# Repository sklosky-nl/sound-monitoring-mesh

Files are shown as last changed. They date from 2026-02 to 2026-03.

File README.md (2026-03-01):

# Sound Monitoring Mesh

A distributed sound monitoring system: ESP32-C3 sensor nodes sample audio via INMP441 I2S microphone, compute FFT-based dB and frequency-band levels, and POST measurements to a Node.js backend. A browser frontend provides real-time monitoring, triangulation, history playback, alerts, analytics, and a public kiosk display.

**Status:** ✅ Operational — 9 devices at Nova Labs makerspace (`xibo.space.nova-labs.org`)  
**Firmware:** `2.1.1-prod` (production) · `2.1.2-dev` (dev / OTA testing)  
**Backend / Frontend:** `v2.1.0`

---

## Table of Contents

1. [Architecture](#architecture)
2. [Hardware](#hardware)
3. [Firmware](#firmware)
4. [Backend](#backend)
5. [Frontend](#frontend)
6. [Production Deployment](#production-deployment-nova-labs)
7. [Development Setup](#development-setup)
8. [Scripts](#scripts)
9. [Security & Credentials](#security--credentials)
10. [Changelog](#changelog)

---

## Architecture

```
ESP32-C3 + INMP441  (×9)
        │  WiFi (REDACTED_WORKSHOP_WIFI_SSID)
        ▼
┌───────────────────────────────┐
│  xibo.space.nova-labs.org     │
│  Ubuntu 20.04 · Apache proxy  │
│                               │
│  ┌──────────────────────────┐ │
│  │ Node.js/Express :3000    │ │  ← /api/*
│  │  13 REST route modules   │ │
│  └──────────────────────────┘ │
│  ┌──────────────────────────┐ │
│  │ Frontend (vanilla JS)    │ │  ← xibo.space.nova-labs.org/sound/
│  │  Served by Apache        │ │
│  └──────────────────────────┘ │
│  ┌──────────────────────────┐ │
│  │ JSON file storage        │ │  ← backend/data/
│  └──────────────────────────┘ │
└───────────────────────────────┘
```

**Data flow:** Each device POSTs to `/api/data` every 5 s → backend stores JSON → frontend polls → renders.  
**Authentication:** Shared API key in `Authorization: Bearer` header (all devices share one key, uniquely identified by MAC address).

---

## Hardware

### Bill of Materials (per sensor node)

| Component | Part | Notes |
|---|---|---|
| MCU | ESP32-C3 SuperMini | RISC-V 160 MHz, 4 MB flash, 400 KB SRAM, USB-CDC |
| Microphone | INMP441 I2S MEMS | −26 dBFS, 61 dB SNR, 60 Hz–15 kHz |
| Power | USB-C cable + 5V wall charger | |
| Enclosure | 15–30 mm foam microphone windscreen | RF-transparent (<0.5 dB loss), acoustically transparent |
| Wiring | Dupont jumper wires | Solder header pins to ESP32-C3 SuperMini first |

> ⚠️ 3D-printed PETG enclosures blocked WiFi signals (6–16 dB loss). Foam windscreens are the confirmed solution.

### Wiring — ESP32-C3 → INMP441

| ESP32-C3 | GPIO | INMP441 Pin | Signal |
|---|---|---|---|
| 3V3 | — | VDD | Power (3.3 V) |
| GND | — | GND | Ground |
| GND | — | L/R | Channel select (GND = Left channel) |
| **4** | GPIO 4 | SD | I2S Data |
| **5** | GPIO 5 | SCK | I2S Bit Clock |
| **6** | GPIO 6 | WS | I2S Word Select |

> ⚠️ A **10 kΩ pull-down resistor on the SD line** (GPIO 4 to GND) is required. Without it the SD line floats and produces noise/incorrect readings.

```
ESP32-C3 SuperMini             INMP441
  3.3V ●────────────────────── VDD
   GND ●──────────┬─────────── GND
                  └─────────── L/R  (Left channel)
GPIO 4 ●──[10kΩ]──┤─────────── SD
GPIO 5 ●────────────────────── SCK
GPIO 6 ●────────────────────── WS
```

---

## Firmware

**Source:** `firmware/sound-level-sensor/`  
**Current versions:** `2.1.1-prod` (production binary) · `2.1.2-dev` (dev binary, points at local backend)

### Key Features

| Feature | Detail |
|---|---|
| I2S sampling | 16 kHz, **32-bit container** (INMP441 outputs 24-bit; DMA data width must be 32-bit) |
| FFT | 1024-point, Hamming window, ESP-DSP library |
| Frequency bands | 3 configurable bands (start Hz, end Hz per band), SPL via self-normalizing energy fraction |
| dB calculation | Full-spectrum RMS + peak-hold over reporting window |
| Event detection | Threshold 55 dB, min duration 50 ms, cooldown 500 ms |
| OTA updates | Checks `/api/firmware/check` hourly; dual OTA partitions; auto-rollback on failure |
| Time sync | SNTP/NTP on boot |
| Auth | `Authorization: Bearer <API_KEY>` on all API calls |
| Device identity | MAC address used as `device_id` (auto-detected at runtime) |

### Configuration (`sdkconfig.defaults` → copy to `sdkconfig`)

```ini
CONFIG_WIFI_SSID         = "YOUR_WIFI_SSID"
CONFIG_WIFI_PASSWORD     = "YOUR_WIFI_PASSWORD"
CONFIG_SERVER_URL        = "http://YOUR_SERVER_HOST:3000"
CONFIG_API_KEY           = "YOUR_API_KEY"
```

Real values live in `CREDENTIALS.local` (gitignored). Never commit actual credentials.

### Build & Flash

```bash
# One-time: source ESP-IDF
source ~/esp/esp-idf/export.sh

cd firmware/sound-level-sensor

# Configure (first time or when credentials change)
cp sdkconfig.defaults sdkconfig
idf.py menuconfig          # Set WiFi SSID, password, server URL, API key

# Build
idf.py build

# Flash (USB)
idf.py -p /dev/cu.usbmodem* flash

# Monitor serial output
idf.py -p /dev/cu.usbmodem* monitor
```

Expected serial output after successful boot:
```
I (xxxx) SOUND_SENSOR: Connected to WiFi
I (xxxx) SOUND_SENSOR: NTP sync complete
I (xxxx) SOUND_SENSOR: Starting measurement loop
I (xxxx) SOUND_SENSOR: dB=62.3 peak=71.0 band1=45.2 band2=58.1 band3=41.6
```

### OTA Update Workflow

1. Build new firmware binary
2. Copy binary to `backend/data/firmware/sound-sensor-X.Y.Z.bin`
3. Update `backend/data/firmware/versions.json` (version, filename, size, sha256)
4. Devices check hourly; auto-download and reboot if newer version found

Compute sha256:
```bash
shasum -a 256 backend/data/firmware/sound-sensor-X.Y.Z.bin
stat -f%z backend/data/firmware/sound-sensor-X.Y.Z.bin  # file size in bytes
```

### Firmware Version Registry (`backend/data/firmware/versions.json`)

| Version | Type | Notes |
|---|---|---|
| `2.1.1-prod` | Production | **Current** — I2S DMA fix, frequency SPL fix, 10kΩ SD pull-down |
| `2.1.2-dev` | Dev | Same fixes; points to local backend for OTA testing |
| `2.1.0-prod` | Production | Continuous sampling + peak detection |
| `1.2.0-prod` | Legacy | Production WiFi + server config |

### Critical I2S Fix (v2.1.1)

Prior firmware used `I2S_DATA_BIT_WIDTH_24BIT` in the DMA config, causing DMA mis-packing that produced a constant ~110 dB reading. The fix:

```c
// WRONG (caused constant ~110 dB):
.data_bit_width = I2S_DATA_BIT_WIDTH_24BIT,

// CORRECT (INMP441 uses 32-bit container for 24-bit data):
.data_bit_width = I2S_DATA_BIT_WIDTH_32BIT,
```

---

## Backend

**Source:** `backend/src/`  
**Runtime:** Node.js ≥18, Express.js  
**Storage:** JSON files in `backend/data/`

### Setup

```bash
cd backend
cp .env.example .env       # configure SHARED_API_KEY (and optionally PORT)
npm install
npm start                  # production
npm run dev                # development (nodemon)
```

**Environment variables (`.env`):**
```
PORT=3000
HOST=0.0.0.0
SHARED_API_KEY=<see CREDENTIALS.local>
```

### API Routes

All routes are prefixed `/api/`.

| Prefix | File | Description |
|---|---|---|
| `/api/devices` | `routes/devices.js` | Register, list, update, delete devices; calibration; frequency-band config |
| `/api/data` | `routes/data.js` | Receive measurements; query recent/range; export CSV/JSON |
| `/api/config` | `routes/config.js` | Display thresholds; per-device config |
| `/api/alerts` | `routes/alerts.js` | Alert rules CRUD; alert history |
| `/api/analytics` | `routes/analytics.js` | Aggregated stats, trend data, heatmap data |
| `/api/positions` | `routes/positions.js` | Sensor XYZ positions for triangulation map |
| `/api/barriers` | `routes/barriers.js` | Acoustic barriers (walls, curtains, partitions) |
| `/api/sources` | `routes/sources.js` | Sound source location records |
| `/api/triangulation` | `routes/triangulation.js` | Locate/locate-multiple; playback endpoints |
| `/api/labels` | `routes/labels.js` | Map label annotations CRUD |
| `/api/firmware` | `routes/firmware.js` | OTA: `/check`, `/download/:version`, `/upload`, `/versions`, `/latest` |
| `/api/grafana` | `routes/grafana.js` | Grafana JSON datasource (`/search`, `/query`, `/annotations`) |
| `/api/version` | `routes/version.js` | Returns backend version |

**Key endpoints:**
```
GET  /health
GET  /api/devices
POST /api/devices/register              ← called by firmware on boot
POST /api/data                          ← called by firmware every 5 s
GET  /api/data/recent                   ← latest reading per device
GET  /api/data/measurements/:deviceId
GET  /api/firmware/check?device_id=&current_version=
GET  /api/firmware/download/:version
GET  /api/triangulation/locate
GET  /api/triangulation/playback/range
GET  /api/grafana/kiosk/data
```

**Data storage layout:**
```
backend/data/
├── devices/           ← one JSON file per device (MAC address filename)
├── measurements/      ← daily JSON files per device (gitignored)
├── config/
│   └── display-thresholds.json
├── alerts/
│   └── history/
├── firmware/
│   ├── versions.json
│   └── *.bin
├── map_labels.json
└── acoustic_barriers.json
```

---

## Frontend

**Source:** `frontend/`  
**Technology:** Vanilla JavaScript (ES6+), HTML5/CSS3, Chart.js 4.4.0  
**Served by:** Apache at `/sound/` (production) or directly from `frontend/` in development

### Pages

| File | Purpose |
|---|---|
| `index.html` | Main dashboard (7 tabs) |
| `kiosk.html` | Public display — full-screen map + sensor status |
| `kiosk-debug.html` | Debug kiosk with API diagnostics |
| `debug.html` | API connectivity testing |

### Dashboard Tabs (`index.html`)

| Tab | Key Features |
|-----|---|
| **Dashboard** | Live device cards: dB level, frequency bands, color-coded status; auto-refresh 5 s |
| **Devices** | Register (MAC), edit, calibrate (dB offset), delete, export JSON |
| **Triangulation** | HTML5 Canvas map; sensor positions; acoustic barriers; map labels; real-time + playback |
| **History** | Time-series charts per device; second-precision datetime range picker |
| **Alerts** | Create/edit/delete alert rules; alert history viewer |
| **Analytics** | Statistical summaries, trend charts, customizable date ranges |
| **Settings** | Display thresholds, data retention, system configuration |

### Kiosk Mode (`kiosk.html`)

Auto-refreshing public display designed for permanent large-screen installation:
- Workshop layout canvas with sensor positions, acoustic barriers, and map labels
- Color-coded sensor indicators by dB level
- Active sensor count and system status summary

### Triangulation Playback

The Triangulation tab supports historical replay:
- Transport: play/pause, jog ±1 s, skip to start/end
- Variable speed: 0.25×, 0.5×, 1×, 2×, 5×, 10×
- Date/time range picker (day/hour/minute/second precision)
- Timeline slider with data availability indicator

### Color Thresholds (configurable via `/api/config/display-thresholds`)

| Range | Color | Default |
|---|---|---|
| Quiet | Green | < 80 dB |
| Moderate | Yellow | 80–95 dB |
| Loud | Red | > 95 dB |

---

## Production Deployment (Nova Labs)

| Item | Value |
|---|---|
| Server | `xibo.space.nova-labs.org` — Ubuntu 20.04.2 LTS |
| Proxy | Apache 2.4 reverse proxy |
| WiFi network | `REDACTED_WORKSHOP_WIFI_SSID` — isolated IoT VLAN |
| Backend URL | `http://xibo.space.nova-labs.org/api/sound` |
| Frontend URL | `http://xibo.space.nova-labs.org/sound/` |
| Active devices | 9 ESP32-C3 sensors |

### Apache Configuration (key lines)

```apache
# Proxy /api/sound/* → Node.js :3000/api/*
ProxyPass        /api/sound/ http://localhost:3000/api/
ProxyPassReverse /api/sound/ http://localhost:3000/api/

# Serve frontend static files
Alias /sound/ /path/to/frontend/
```

> ⚠️ The trailing slash on both `ProxyPass` paths is required. Without it, paths double to `/api/api/`.

### Operations

```bash
# SSH to server
ssh user@xibo.space.nova-labs.org

# Restart backend
cd ~/sound-monitoring-mesh/backend && npm start

# Deploy kiosk updates
./scripts/deploy-kiosk.sh
```

### Grafana Integration

The backend exposes a Grafana JSON datasource at `/api/grafana`.  
Dashboard definition: `scripts/grafana/grafana-dashboard.json`  
Install scripts: `scripts/grafana/install-grafana.sh` (dev) · `scripts/grafana/install-prod.sh` (production)

---

## Development Setup

```bash
# 1. Clone
git clone git@github.com:sklosky-nl/sound-monitoring-mesh.git
cd sound-monitoring-mesh

# 2. Backend
cd backend && cp .env.example .env   # fill in SHARED_API_KEY from CREDENTIALS.local
npm install && npm start             # http://localhost:3000

# 3. Access frontend
open http://localhost:3000           # main dashboard
open http://localhost:3000/kiosk.html

# 4. Flash a device
source ~/esp/esp-idf/export.sh
cd firmware/sound-level-sensor
cp sdkconfig.defaults sdkconfig
idf.py menuconfig                    # set WiFi + server + API key
idf.py build flash monitor -p /dev/cu.usbmodem*
```

**Versions:** Node.js ≥18 · ESP-IDF v6.x (tested with v6.1-dev-2300)

---

## Scripts

| Script | Purpose |
|---|---|
| `scripts/deploy-kiosk.sh` | Deploy frontend updates to production server |
| `scripts/grafana/install-grafana.sh` | Install Grafana on local/dev machine |
| `scripts/grafana/install-prod.sh` | Install Grafana on production server |
| `scripts/grafana/grafana-dashboard.json` | Grafana dashboard definition |

---

## Security & Credentials

**No credentials are stored in this repository.**

| Secret | Where used | How to set |
|---|---|---|
| WiFi SSID + password | Firmware `sdkconfig` | Copy from `CREDENTIALS.local` |
| Shared API key | Firmware `sdkconfig` + backend `.env` | Copy from `CREDENTIALS.local` |

The firmware and backend API key **must match exactly** for device authentication to work.

> ⚠️ **Git history note:** Commits prior to `f087388` (Feb 28, 2026) contain real credential values. Those credentials have been rotated. If you fork this repo, use `bfg --replace-text secrets.txt` to purge history before making it public.

---

## Repository Structure

```
sound-monitoring-mesh/
├── README.md                        ← this file
├── CHANGELOG.md                     ← version history
├── CREDENTIALS.local                ← gitignored; real secrets
├── backend/
│   ├── src/
│   │   ├── server.js
│   │   ├── routes/                  ← 13 route modules
│   │   ├── models/
│   │   ├── services/
│   │   └── utils/
│   └── data/                        ← gitignored runtime data
│       ├── devices/
│       ├── measurements/
│       ├── config/
│       ├── alerts/
│       ├── firmware/
│       │   ├── versions.json
│       │   └── *.bin
│       ├── map_labels.json
│       └── acoustic_barriers.json
├── frontend/
│   ├── index.html                   ← main dashboard (7 tabs)
│   ├── kiosk.html                   ← public display
│   ├── css/
│   └── js/
├── firmware/
│   ├── sound-level-sensor/          ← production firmware
│   │   ├── main/main.c
│   │   ├── sdkconfig.defaults       ← placeholder values only (never real credentials)
│   │   └── partitions.csv           ← dual OTA partitions
│   └── sound-level-sensor-debug/    ← debug build (serial only, no WiFi)
├── enclosure/
│   ├── Sound Sensor enclosure.f3d   ← Fusion 360 (archived; foam windscreens used instead)
│   └── WIFI_SIGNAL_SOLUTIONS.md
├── scripts/
│   ├── deploy-kiosk.sh
│   └── grafana/
│       ├── install-grafana.sh
│       ├── install-prod.sh
│       └── grafana-dashboard.json
└── docs-archive/                    ← superseded reference documents
```

---

## Changelog

See [CHANGELOG.md](CHANGELOG.md) for full version history.

### Recent: v2.1.1-prod / v2.1.2-dev — Feb 28, 2026
- Fix I2S DMA mis-packing (`I2S_DATA_BIT_WIDTH_24BIT` → `32BIT`) — was causing constant ~110 dB
- Fix frequency band SPL calculation (self-normalizing energy fraction)
- Confirm and document 10 kΩ pull-down on SD line (GPIO 4)

### v2.1.0-prod — Feb 12, 2026
- Continuous sampling with peak detection (was previously sampling only 6.4% of audio)
- Reports both RMS average and peak dB per reporting window

### v2.0.0 — Feb 12, 2026
- Historical data playback for triangulation (timeline scrubber, variable speed)
- Backend playback API: `/api/triangulation/playback/*`

### v1.2.0 — Feb 11, 2026
- Kiosk display page; production deployment to Nova Labs (9 devices)
- Apache ProxyPass configuration

---

**Author:** Stephen Klosky — [stephen.klosky@nova-labs.org](mailto:stephen.klosky@nova-labs.org)  
**Last updated:** February 28, 2026

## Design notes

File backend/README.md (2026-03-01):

# Backend

See the [main README](../README.md) for full documentation.

# Sound Level Mesh System - Backend API

Node.js backend API server for the Sound Level Mesh System.

**Status:** ✅ Operational with 9 devices actively sending data

## Features

### Core Functionality
- RESTful API with 9 route modules
- Device registration and management
- Real-time measurement data collection and storage
- Shared API key authentication with per-device validation
- File-based JSON storage (no database required)
- Automatic data cleanup with configurable retention
- Comprehensive logging with Winston

### API Modules
1. **Device Management** - Registration, CRUD operations, device info
2. **Data Collection** - Measurement submission and retrieval
3. **Configuration** - Frequency bands, calibration, device settings
4. **Alerts** - Alert rules, threshold monitoring, notification system
5. **Analytics** - Statistical analysis, trends, aggregations
6. **Triangulation** - Sound source localization using continuous RSS (Received Signal Strength) measurements
   - Single-source localization using basic RSS
   - Multi-source detection using frequency-band separation and temporal clustering
7. **Positions** - Sensor spatial positioning and mapping
8. **Sources** - Sound source tracking and management
9. **Barriers** - Acoustic obstacle modeling for triangulation

### Data Management
- JSON file-based storage for devices, measurements, alerts
- Time-series measurement data organized by device and date
- Configurable data retention (default: 7 days)
- CSV export functionality
- Bulk data export (all devices + measurements)

## Setup

### Prerequisites

- Node.js 18.0.0 or higher
- npm

### Installation

```bash
cd backend
npm install
```

### Configuration

Create a `.env` file in the backend directory:

```bash
# Server Configuration
PORT=3000
NODE_ENV=development
HOST=0.0.0.0

# Data Storage
DATA_DIR=./data
DATA_RETENTION_DAYS=7

# API Configuration - Shared Key Approach
# All devices use this SAME API key (must match firmware CONFIG_API_KEY)
SHARED_API_KEY=<your-api-key>  # see CREDENTIALS.local
# Legacy alias (SHARED_API_KEY takes precedence)
API_KEY=<your-api-key>  # see CREDENTIALS.local

# Logging
LOG_LEVEL=info
```

**Shared API Key Approach:**
- All ESP32 devices use the **same API key** compiled into firmware
- The `SHARED_API_KEY` (or `API_KEY`) must **exactly match** the firmware's `CONFIG_API_KEY`
- Each device is uniquely identified by its MAC address (e.g., `08:92:72:84:1d:18`)
- Backend validates the shared key first, then checks if device exists
- Simplifies deployment: one firmware build for all devices
- **Current deployment:** 9 devices operational, 10 purchased (1 spare)

**To change the key:**
1. Choose a secure random string (e.g., UUID)
2. Update `SHARED_API_KEY` in backend `.env`
3. Update `CONFIG_API_KEY` in firmware `sdkconfig` (via `idf.py menuconfig`)
4. Rebuild and reflash all devices
5. Re-register all devices in backend (they'll get new shared key)

### Server Settings

The backend includes the following optimizations for IoT device communication:

- **Body Parser Limit**: 10MB (handles large JSON payloads)
- **Request Timeout**: 30 seconds
- **Response Timeout**: 30 seconds
- **CORS**: Enabled for all origins (development mode)
- **Host**: 0.0.0.0 (listens on all network interfaces)

## Running the Server

### Development mode (with auto-restart)

```bash
npm run dev
```

### Production mode

```bash
npm start
```

The server will start on port 3000 (configurable via `PORT` env variable).

**Access:**
- API Base: http://localhost:3000/api/
- Frontend: http://localhost:3000 (serves static files from ../frontend)
- Health Check: http://localhost:3000/health
- Kiosk Display: http://localhost:3000/kiosk.html

**Logs:**
- Console output (info level)
- File logging: `data/logs/server.log`

### Current Status

**Active System:**
- 9 devices registered and sending data
- Real-time measurements every 5 seconds
- All API endpoints operational
- Frontend fully integrated

---

## API Endpoints

### Quick Reference

**Devices:**
- `GET /api/devices` - List all devices
- `POST /api/devices/register` - Register new device
- `GET /api/devices/:id` - Get device details
- `PUT /api/devices/:id` - Update device
- `DELETE /api/devices/:id` - Delete device

**Measurements:**
- `POST /api/data/measurements` - Submit measurement (requires auth)
- `GET /api/data/measurements/:deviceId` - Get device measurements
- `GET /api/data/export/csv/:deviceId` - Export to CSV

**Configuration:**
- `GET /api/config/devices/:id/frequency-bands` - Get device config
- `PUT /api/config/devices/:id/frequency-bands` - Update bands
- `PUT /api/config/devices/:id/calibration` - Update calibration

**Alerts:**
- `GET /api/alerts` - List alert rules
- `POST /api/alerts` - Create alert rule
- `GET /api/alerts/history/all` - Get alert history

**Analytics:**
- `GET /api/analytics/stats` - Get statistics

**Triangulation:**
- `GET /api/triangulation/locate` - Locate single sound source using RSS
- `GET /api/triangulation/locate-multiple` - Locate multiple simultaneous sources
- `GET /api/triangulation/sensors` - Get sensor positions
- `GET /api/triangulation/sources/recent` - Get recent sound sources

**Positions & Barriers:**
- `GET /api/positions/sensors` - Get sensor positions
- `PUT /api/positions/sensors` - Update position
- `GET /api/barriers` - Get acoustic barriers
- `POST /api/barriers` - Add barrier

See [DEVELOPER_REFERENCE.md](../DEVELOPER_REFERENCE.md) for complete API documentation.

---

## Architecture

### File Structure
```
backend/
├── src/
│   ├── server.js           # Main Express server
│   ├── routes/             # API route modules (9 files)
│   ├── models/             # Data models (5 files)
│   ├── services/           # Business logic (triangulation, etc.)
│   └── utils/              # Helpers (logger)
├── data/
│   ├── devices/            # Device JSON files
│   ├── measurements/       # Measurement time-series data
│   ├── alerts/             # Alert rules and history
│   └── logs/               # Server logs
├── package.json
└── .env                    # Configuration
```

### Data Storage

**Devices:** `data/devices/{device_id}.json`
- One file per device
- Contains registration info, config, position

**Measurements:** `data/measurements/{device_id}_{YYYY-MM-DD}.json`
- One file per device per day
- Array of measurements with timestamps
- Old files cleaned up based on retention policy

**Alerts:** `data/alerts/`
- Alert rules and triggered alert history

### Authentication Flow

1. Device sends measurement with `Authorization: Bearer {api_key}` header
2. Backend extracts API key and device_id from request
3. Validates via `DeviceModel.verifyApiKey()`:
   - First checks if key matches `SHARED_API_KEY` (if configured)
   - If shared key matches, verifies device exists
   - Otherwise checks device-specific API key
4. If valid, stores measurement and updates last_seen
5. If invalid, returns 403 error

---

## API Endpoints (Detailed)

### Health Check

```http
GET /health
```

### Device Management

**Register a device:**
```http
POST /api/devices/register
Content-Type: application/json

{
  "device_id": "esp32_001",
  "mac_address": "AA:BB:CC:DD:EE:FF",
  "name": "Living Room Sensor",
  "location": "Living Room, North Wall"
}
```

**Get all devices:**
```http
GET /api/devices
```

**Get specific device:**
```http
GET /api/devices/:deviceId
```

**Update device:**
```http
PUT /api/devices/:deviceId
Content-Type: application/json

{
  "name": "Updated Name",
  "location": "New Location"
}
```

### Data Submission

**Submit measurement (requires API key):**
```http
POST /api/data/measurements
Authorization: Bearer <api_key>
Content-Type: application/json

{
  "device_id": "esp32_001",
  "timestamp": "2026-01-30T18:00:00Z",
  "db_level": 65.5,
  "db_level_raw": 65.5,
  "frequency_bands": [
    {
      "band_number": 1,
      "start_freq": 20,
      "end_freq": 200,
      "level": 45.2,
      "level_raw": 45.2
    }
  ]
}
```

**Get measurements:**
```http
GET /api/data/measurements/:deviceId?start_date=2026-01-29&end_date=2026-01-30
GET /api/data/measurements/:deviceId?limit=10
```

### Configuration

**Get device configuration:**
```http
GET /api/config/devices/:deviceId/frequency-bands
```

**Update frequency bands:**
```http
PUT /api/config/devices/:deviceId/frequency-bands
Content-Type: application/json

{
  "frequency_bands": [
    {
      "band_number": 1,
      "start_frequency": 20,
      "end_frequency": 200,
      "calibration_offset_db": 0.0
    }
  ],
  "measurement_interval": 5,
  "calibration_offset_db": 2.5
}
```

**Update calibration:**
```http
PUT /api/config/devices/:deviceId/calibration
Content-Type: application/json

{
  "calibration_offset_db": 2.5
}
```

## Data Storage

All data is stored in the `./data` directory:

- `data/devices/` - Device configuration files (JSON)
- `data/measurements/` - Measurement data files (JSON, one file per device per day)
- `data/logs/` - Server logs

## Automatic Cleanup

Old measurement data is automatically cleaned up based on the `DATA_RETENTION_DAYS` setting (default: 7 days).

Manual cleanup:
```http
POST /api/data/cleanup
```

## Development

### Project Structure

```
backend/
├── src/
│   ├── server.js          # Main server file
│   ├── routes/            # API route handlers
│   │   ├── devices.js
│   │   ├── data.js
│   │   └── config.js
│   ├── models/            # Data models
│   │   ├── Device.js
│   │   └── Measurement.js
│   └── utils/             # Utility functions
│       └── logger.js
├── data/                  # Data storage (git-ignored)
│   ├── devices/
│   ├── measurements/
│   └── logs/
├── package.json
├── .env                   # Environment configuration
└── README.md
```

### Adding New Endpoints

1. Create route handler in `src/routes/`
2. Import and register in `src/server.js`
3. Add model functions if needed in `src/models/`

## Deployment

For production deployment on Ubuntu server, see the main architecture document.

## License

TBD

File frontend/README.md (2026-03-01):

# Frontend

See the [main README](../README.md) for full documentation.

# Sound Level Mesh System - Frontend

Web-based dashboard for monitoring and managing sound level sensors.

**Status:** ✅ Operational - Served automatically by backend on port 3000

## Features

- **Dashboard:** Real-time device monitoring with live statistics (auto-refresh every 30 seconds)
- **Devices:** Device registration, management, and configuration
- **Triangulation:** Sound source localization with visual 2D map
- **History:** Time-series data viewer with second-precision datetime controls
- **Alerts:** Alert rule configuration and history viewer
- **Analytics:** Statistical analysis and trend visualization
- **Settings:** System configuration and data management
- **Kiosk Mode:** Public display dashboard (separate page)
- Responsive design (desktop and tablet)

## Running the Frontend

### Recommended: Backend Serves Frontend (Default)

**The backend automatically serves the frontend - no separate server needed!**

```bash
cd backend
npm install
npm start
```

Then open http://localhost:3000 in your browser.

**Access URLs:**
- Main Dashboard: http://localhost:3000
- Kiosk Display: http://localhost:3000/kiosk.html  
- API Endpoints: http://localhost:3000/api/*
- Health Check: http://localhost:3000/health

**Current Setup:**
- Running on MacBook
- Backend + Frontend on single port (3000)
- API and static files served together
- All devices connecting and sending data

### Alternative: Standalone Development Server (Optional)

For frontend-only development without backend:

```bash
cd frontend
python3 -m http.server 8080
```

Then open http://localhost:8080 in your browser.

**Note:** You'll need to configure the backend API URL in Settings tab.

### Option 2: Node.js http-server

```bash
# Install globally
npm install -g http-server

# Run
cd frontend
http-server -p 8080
```

### Option 3: VS Code Live Server Extension

1. Install "Live Server" extension in VS Code
2. Right-click on `index.html`
3. Select "Open with Live Server"

### Troubleshooting

**Port Already in Use:**
```bash
# Kill existing process on port 8080
lsof -ti :8080 | xargs kill -9 2>/dev/null
```

**CORS Issues:**
- The backend has CORS enabled for all origins (development mode)
- Make sure backend is running and accessible
- Check browser console for specific CORS errors

## Configuration

**Default Configuration (when served by backend):**
- API URL is automatically set to the same origin (http://localhost:3000)
- No configuration needed for normal use

**Production Configuration (Nova Labs):**
- Set the Backend API URL to http://xibo.space.nova-labs.org/api/sound

**Manual Configuration (if needed):**
1. Open the frontend in your browser
2. Go to the "Settings" tab
3. Set the Backend API URL (e.g., `http://localhost:3000` or `http://xibo.space.nova-labs.org/api/sound`)
4. Click "Save Configuration"

The setting is saved to browser localStorage and persists across sessions.

## Usage

### Dashboard Tab
- View all 9 registered devices
- See real-time sound levels and frequency bands
- Monitor device status (active within last minute)
- View average sound level across all devices
- Auto-refreshes every 30 seconds

### Devices Tab
- View detailed device information
- Edit device names (nickname) and locations
- Configure frequency bands
- Update calibration offsets
- Delete devices

### Triangulation Tab
- Visual 2D map of sensor positions
- Click-to-place sensor locations
- Real-time sound source localization
- Acoustic barrier modeling  

### History Tab  
- Select device from dropdown
- Choose date/time range with **second precision**
- View time-series chart of measurements
- Export data to CSV

### Alerts Tab
- Create threshold-based alert rules
- Configure alert conditions and durations
- View alert history
- Manage alert notifications

### Analytics Tab
- Statistical analysis (avg, min, max, std dev)
- Trend visualization
- Device comparison
- Custom date range selection

## API Integration

The frontend communicates with the backend API at the configured URL.

Default: `http://localhost:3000`

All API calls are made from `js/api.js`. The base URL is configurable through the Settings tab.

## Browser Support

- Chrome/Edge (recommended)
- Firefox
- Safari
- Modern mobile browsers

## Development

### File Structure

```
frontend/
├── index.html          # Main HTML file
├── css/
│   └── styles.css      # Application styles
└── js/
    ├── api.js          # API client
    └── app.js          # Main application logic
```

### Customization

- **Colors**: Edit CSS custom properties in `styles.css` `:root` section
- **Refresh interval**: Change value in `startAutoRefresh()` in `app.js`
- **Default ports**: Update in `api.js` and Settings tab

## Screenshots

(Screenshots would go here in a real README)

## License

TBD

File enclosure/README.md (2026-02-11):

# Sound Sensor Enclosure

This directory contains enclosure design files and documentation for the sound sensor hardware.

## ✅ Current Solution: Microphone Foam Windscreen Enclosure

**The final working solution uses microphone foam windscreens as the complete enclosure.**

### Implementation

**Materials:**
- Microphone foam windscreen (medium size, 15-30mm diameter)
- Zip tie or twist tie
- USB-C cable for power

**Assembly:**
1. Insert assembled ESP32-C3 + INMP441 sensor into foam windscreen
2. Route USB-C cable through foam
3. Secure foam around cable with zip tie
4. Ensure microphone opening has clear path through foam

**Why This Works:**
- ✅ **RF Transparent**: Foam has <0.5 dB WiFi signal loss
- ✅ **Acoustically Transparent**: Designed for microphone use, minimal SPL impact
- ✅ **Dust Protection**: Open-cell foam filters particles while allowing airflow
- ✅ **Cost Effective**: ~$1-2 per device
- ✅ **Washable**: Can clean foam when dirty
- ✅ **Quick Assembly**: No 3D printing required
- ✅ **Lightweight**: Easy to mount anywhere

**Recommended Products:**
- [Amazon microphone windscreens](https://a.co/d/01RMTvTz) - Medium size (15-25mm)
- Alternative: Air filter foam from hardware stores

**Maintenance:**
- Inspect foam monthly in dusty environments
- Wash with mild soap and water when dirty
- Dry completely (24 hours) before reinstalling
- Replace every 6-12 months or when degraded

---

## ❌ Previous Attempts (Did Not Work)

### 3D Printed PETG Enclosures

- **Sound Sensor enclosure.f3d** - Fusion 360 source file (archived)
- **Sound Sensor enclosure.stl** - STL file for 3D printing (archived)

**Issues Discovered:**
- ❌ **WiFi Signal Blocking**: PETG plastic attenuates 2.4 GHz WiFi by 6-16 dB
- ❌ **Connection Failures**: Devices could not maintain WiFi connection when fully enclosed
- ❌ **Fit Problems**: Lid required heat gun adjustment to close properly
- ❌ **Complexity**: 3D printing and post-processing time not justified

**Lessons Learned:**
- Solid plastic enclosures create Faraday cage effect for 2.4 GHz WiFi
- RF transparency is critical for wireless IoT devices
- Simple foam solutions outperform complex rigid enclosures for this application

**→ See [WIFI_SIGNAL_SOLUTIONS.md](WIFI_SIGNAL_SOLUTIONS.md) for detailed analysis of WiFi blocking issues and alternative solutions tested.**

---

## Design Files (Reference Only)

The 3D printed enclosure files are retained for reference but are **not recommended** for production use due to WiFi blocking issues.

---

## Usage Instructions (Foam Windscreen Solution)

### Assembly Steps

**Step 1: Component Preparation**
- Fully assemble ESP32-C3 with INMP441 microphone (see [HARDWARE_AND_FIRMWARE.md](../HARDWARE_AND_FIRMWARE.md))
- Connect USB-C cable for power
- Test device functionality before enclosing

**Step 2: Foam Installation**
1. Select foam windscreen slightly larger than device (20-30mm diameter typical)
2. Gently insert device into foam, microphone end first
3. Position INMP441 near an opening in the foam for clear sound path
4. Route USB cable through opposite end of foam

**Step 3: Securing**
1. Gather foam around USB cable at exit point
2. Secure with zip tie or twist tie (not too tight - allow some airflow)
3. Trim excess zip tie

**Step 4: Testing**
1. Power on device
2. Verify WiFi connection in backend dashboard (http://localhost:3000)
3. Check sound level readings are within expected range
4. If readings seem low, adjust foam position around microphone

**Step 5: Deployment**
- Mount device in desired location
- Ensure foam doesn't compress against surfaces
- Orient microphone opening away from direct weather exposure if outdoor
- Label device with MAC address for easy identification

### Mounting Options

- **Zip tie to post/beam**: Create loops through foam
- **Velcro strips**: Works well on flat surfaces  
- **Hanging with string**: Thread through foam
- **Shelf placement**: Simply set on flat surface

### Troubleshooting

**Issue: WiFi disconnections**
- Ensure foam is dry (wet foam increases RF attenuation)
- Check device is not in metal enclosure or near metal surfaces
- Verify router signal strength in deployment location

**Issue: Inaccurate sound readings**
- Check microphone opening is not blocked by compressed foam
- Verify foam is not touching INMP441 membrane directly
- Calibrate using `calibration_offset_db` parameter if needed

**Issue: Dust accumulation**
- Remove and wash foam with mild soap and water
- Dry completely for 24 hours before reinstalling
- Replace foam if heavily soiled or degraded

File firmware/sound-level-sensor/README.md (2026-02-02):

# Sound Level Sensor - ESP32-C3 Firmware

ESP32-C3 firmware for sound level monitoring with INMP441 I2S microphone.

## Features

- I2S audio sampling from INMP441 microphone (16kHz, 32-bit)
- FFT-based frequency analysis (1024 points with Hamming window)
- Configurable frequency bands (default: 20-200Hz, 200-2000Hz, 2000-8000Hz)
- dB level calculation with calibration support
- WiFi connectivity with automatic reconnection
- HTTP client with retry logic (3 attempts with exponential backoff)
- NTP time synchronization
- Robust error handling and connection management

## Hardware Configuration

- **ESP32-C3 SuperMini**
- **INMP441 I2S Microphone**

### Wiring (ESP32-C3 to INMP441)
- GPIO 4 → SD (I2S Data)
- GPIO 5 → SCK (I2S Clock)
- GPIO 6 → WS (Word Select)
- 3.3V → VDD
- GND → GND
- GND → L/R (Left channel select)

## Building and Flashing

### Prerequisites
- ESP-IDF v5.0 or later installed
- ESP32-C3 connected via USB

### Configure the Project

```bash
cd firmware/sound-level-sensor
. $HOME/esp/esp-idf/export.sh
idf.py menuconfig
```

Navigate to "Sound Level Sensor Configuration" and set:
- WiFi SSID (your home WiFi network name)
- WiFi Password
- Backend Server URL (e.g., `http://192.168.68.67:3000`)
- API Key (obtain from backend server)

### Build and Flash

```bash
# Build
idf.py build

# Flash to ESP32-C3 (replace port as needed)
idf.py -p /dev/tty.usbserial-* flash

# Monitor serial output
idf.py -p /dev/tty.usbserial-* monitor
```

### Build, Flash, and Monitor (all in one)

```bash
idf.py -p /dev/tty.usbserial-* flash monitor
```

## Configuration

Edit via `idf.py menuconfig` under "Sound Level Sensor Configuration":

- **WiFi SSID**: Your WiFi network name
- **WiFi Password**: Your WiFi password
- **Server URL**: Backend API server URL (e.g., `http://192.168.68.57:3000`)
- **API Key**: Authentication token for backend API

### HTTP Communication Settings

The firmware includes robust HTTP communication with the following configuration:

- **Connection Timeout**: 10 seconds
- **Retry Attempts**: 3 maximum retries
- **Retry Delay**: Exponential backoff (2s, 4s, 8s)
- **Keep-Alive**: Disabled (forces fresh connections)
- **Transport Type**: HTTP_TRANSPORT_OVER_TCP
- **Connection Header**: "Connection: close"

These settings ensure reliable communication even in challenging network conditions.

## Data Format

The firmware sends JSON data to `POST /api/data/measurements`:

```json
{
  "device_id": "esp32_001",
  "timestamp": "2026-01-30T18:00:00Z",
  "db_level": 65.5,
  "db_level_raw": 65.5,
  "frequency_bands": [
    {
      "band_number": 1,
      "start_freq": 20,
      "end_freq": 200,
      "level": 45.2,
      "level_raw": 45.2
    },
    {
      "band_number": 2,
      "start_freq": 200,
      "end_freq": 2000,
      "level": 52.1,
      "level_raw": 52.1
    },
    {
      "band_number": 3,
      "start_freq": 2000,
      "end_freq": 8000,
      "level": 48.3,
      "level_raw": 48.3
    }
  ]
}
```

## Troubleshooting

### Can't find serial port
- Check USB connection
- Verify driver installation: `ls /dev/tty.*`
- Try different USB port or cable

### Build errors
- Ensure ESP-IDF environment is activated: `. $HOME/esp/esp-idf/export.sh`
- Clean build: `idf.py fullclean && idf.py build`

### WiFi connection issues
- Verify SSID and password in menuconfig
- Check 2.4GHz WiFi availability (ESP32-C3 doesn't support 5GHz)
- Monitor serial output for connection status

### No audio data
- Verify I2S wiring connections
- Check microphone power (3.3V)
- Ensure L/R pin is connected to GND

## License

TBD

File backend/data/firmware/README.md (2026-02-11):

# Firmware OTA Update System

This directory contains firmware binaries for Over-The-Air (OTA) updates to ESP32-C3 sound sensor devices.

## Directory Structure

```
firmware/
├── versions.json           # Firmware version metadata
├── sound-sensor-1.0.0.bin  # Firmware binary files
├── sound-sensor-1.0.1.bin
└── README.md              # This file
```

## How OTA Updates Work

1. **Firmware Check**: Devices periodically check for updates via `GET /api/firmware/check`
2. **Version Comparison**: Backend compares device version with latest available
3. **Download**: If update available, device downloads binary via `GET /api/firmware/download/:version`
4. **Installation**: Device writes firmware to alternate partition and reboots
5. **Verification**: On boot, device verifies new firmware and marks it valid
6. **Rollback**: If new firmware fails, device automatically reverts to previous version

## Uploading New Firmware

### Method 1: Using curl

```bash
# Build firmware first
cd firmware/sound-level-sensor
idf.py build

# Upload to backend
curl -X POST "http://localhost:3000/api/firmware/upload?version=1.0.1&description=Bug%20fixes" \
     -H "Content-Type: application/octet-stream" \
     --data-binary "@build/sound-level-sensor.bin"
```

### Method 2: Manual File Copy

```bash
# Copy binary file
cp firmware/sound-level-sensor/build/sound-level-sensor.bin \
   backend/data/firmware/sound-sensor-1.0.1.bin

# Update versions.json
# Add new version entry manually
```

## API Endpoints

### Check for Updates
```http
GET /api/firmware/check?device_id=08:92:72:84:1d:18&current_version=1.0.0
```

Response (update available):
```json
{
  "updateAvailable": true,
  "version": "1.0.1",
  "url": "/api/firmware/download/1.0.1",
  "filename": "sound-sensor-1.0.1.bin",
  "size": 823456,
  "releaseDate": "2026-02-10T12:00:00.000Z",
  "description": "Bug fixes and performance improvements"
}
```

Response (no update): `204 No Content`

### Download Firmware
```http
GET /api/firmware/download/1.0.1
```

Returns binary file with headers:
- `Content-Type: application/octet-stream`
- `X-Firmware-Version: 1.0.1`
- `X-Firmware-SHA256: <hash>`

### List All Versions
```http
GET /api/firmware/versions
```

### Get Latest Version
```http
GET /api/firmware/latest
```

### Upload Firmware
```http
POST /api/firmware/upload?version=1.0.1&description=Release%20notes
Content-Type: application/octet-stream
Body: <binary data>
```

### Delete Version
```http
DELETE /api/firmware/1.0.0
```

## Firmware Update Schedule

- Devices check for updates every **60 minutes**
- First check occurs **5 minutes** after boot (allows system to stabilize)
- Updates only occur when WiFi is connected
- Devices automatically reboot after successful update

## Version Naming Convention

Use semantic versioning: `MAJOR.MINOR.PATCH`

- **MAJOR**: Incompatible API changes or major new features
- **MINOR**: Backward-compatible functionality additions
- **PATCH**: Backward-compatible bug fixes

## Safety Features

1. **Dual Partition**: Firmware stored in two partitions (ota_0 and ota_1)
2. **Automatic Rollback**: If new firmware fails to boot, device reverts to previous version
3. **Verification**: Devices validate firmware before marking as successful
4. **SHA-256 Checksums**: Ensures firmware integrity during download
5. **Timeout Protection**: HTTP downloads timeout after 30 seconds

## Staged Rollout

For production deployments with multiple devices:

1. Upload new firmware to backend
2. Monitor first device to receive update
3. Verify device stability for 24 hours
4. Allow remaining devices to update naturally
5. Or trigger immediate updates via device reboot (forces check)

## Troubleshooting

### Device Not Updating

1. Check device logs for OTA task status
2. Verify WiFi connectivity
3. Check backend firmware versions: `GET /api/firmware/versions`
4. Verify version comparison logic

### Update Failed

1. Check device logs for error messages
2. Verify firmware binary is valid ESP32-C3 image
3. Check firmware size (must fit in partition)
4. Device will automatically rollback to previous version

### Manual Rollback

If needed, flash device manually via USB:
```bash
cd firmware/sound-level-sensor
idf.py flash
```

## Security Considerations

- **HTTP vs HTTPS**: Currently using HTTP for simplicity
- **Authentication**: Uses API key authentication
- **Network**: Deploy on trusted network only
- **Future**: Consider HTTPS for production environments

## Monitoring

Device logs show OTA status:
```
I (12345) SOUND_SENSOR: Checking for firmware updates...
I (12346) SOUND_SENSOR: Current firmware version: 1.0.0
I (12500) SOUND_SENSOR: Update available: 1.0.1
I (12501) SOUND_SENSOR: Starting OTA update...
I (45000) SOUND_SENSOR: OTA update successful! Rebooting...
```

Backend logs show update activity:
```
Firmware update check from 08:92:72:84:1d:18: v1.0.0
Update available for 08:92:72:84:1d:18: v1.0.1
Serving firmware v1.0.1 (823456 bytes)
```

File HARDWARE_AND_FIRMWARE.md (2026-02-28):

# Hardware & Firmware Guide

Complete guide for hardware setup, wiring, firmware building, flashing, and device management for the Sound Level Mesh System.

**System Status:** ✅ Operational with multiple devices actively collecting data

## Table of Contents
1. [Hardware Components](#hardware-components)
2. [Component Pinouts & Wiring](#component-pinouts--wiring)
3. [Firmware Building](#firmware-building)
4. [Flashing Multiple Devices](#flashing-multiple-devices)
5. [Device Registration](#device-registration)
6. [OTA Firmware Updates](#ota-firmware-updates)
7. [Firmware Features](#firmware-features)
8. [Troubleshooting](#troubleshooting)

---

## Hardware Components

### Bill of Materials (Per Sensor Node)
- **1x ESP32-C3 SuperMini** - RISC-V microcontroller with WiFi
- **1x INMP441** - I2S digital MEMS microphone module  
- **1x USB-C cable** - For programming and power
- **Header pins** - For soldering to PCBs
- **Jumper wires** - For connecting microphone to ESP32
- **1x Microphone foam windscreen** - Enclosure/dust protection (15-30mm diameter)
- **1x Zip tie** - To secure foam around USB cable

### Example Components Used (AliExpress Links)

1. **ESP32-C3 SuperMini** - [AliExpress Link](https://www.aliexpress.us/item/3256807018729495.html)
2. **INMP441 I2S Microphone Module** - [AliExpress Link](https://www.aliexpress.us/item/3256809687889895.html)
3. **Header Pins** - [AliExpress Link](https://www.aliexpress.us/item/3256807581676863.html)
4. **USB-C Cables/Power** - [AliExpress Link](https://www.aliexpress.us/item/3256809620417878.html)
5. **Microphone Windscreens** - [Amazon Link](https://a.co/d/01RMTvTz) - Medium size recommended

### Enclosure Solution

**✅ Final Design: Foam Windscreen Enclosure**

After testing, the project uses **microphone foam windscreens** as the complete enclosure:
- **RF Transparent**: <0.5 dB WiFi signal loss (PETG blocked 6-16 dB)
- **Acoustically Transparent**: Optimized for microphone use
- **Dust Protection**: Filters particles while allowing airflow
- **Cost Effective**: ~$1-2 per device
- **Simple Assembly**: Insert device, route cable, secure with zip tie

See [enclosure/](enclosure/) directory for detailed assembly instructions.

❌ **3D Printed PETG Enclosures**: Initial designs blocked WiFi signals and are not recommended.

### Assembly Notes

⚠️ **Header Pin Issue**: The header pins listed above were not soldered to the PCBs. Manual soldering was required after receipt.

**Recommendation for Future Builds**: Order pre-soldered ("welded") headers and use Dupont jumpers for easier assembly and more reliable connections.

### ESP32-C3 SuperMini Specifications
- **MCU**: ESP32-C3 (RISC-V, single-core, 160 MHz)
- **RAM**: 400 KB SRAM
- **Flash**: 4 MB
- **WiFi**: 802.11 b/g/n (2.4 GHz)
- **GPIO**: 13 available pins
- **USB**: Built-in USB-CDC (no external USB-UART needed)
- **Power**: 5V via USB-C or 3.3V direct
- **Size**: Compact SuperMini form factor

### INMP441 I2S Microphone Specifications
- **Type**: Digital MEMS omnidirectional microphone
- **Interface**: I2S (Inter-IC Sound)
- **Sensitivity**: -26 dBFS
- **SNR**: 61 dB
- **Dynamic Range**: 83 dB
- **Frequency Response**: 60 Hz to 15 kHz
- **Supply Voltage**: 1.8V to 3.3V
- **Current**: ~1.4 mA

---

## Component Pinouts & Wiring

### ESP32-C3 SuperMini Pinout

**Physical Orientation**: Hold board with USB-C connector facing UP, chip facing YOU.

#### Complete Pin Table

| Pin Label | GPIO | Physical Position | Function / Notes |
|---|---|---|---|
| **5V** | - | Right Side, Pin 1 | 5V Power Input (from USB or external) |
| **GND** | - | Right Side, Pin 2 | Ground |
| **3V3** | - | Right Side, Pin 3 | 3.3V Output (Regulated) or Input |
| **0** | GPIO 0  | Right Side, Pin 4 | ADC1_CH0, Digital I/O |
| **1** | GPIO 1  | Right Side, Pin 5 | ADC1_CH1, Digital I/O |
| **2** | GPIO 2  | Right Side, Pin 6 | ⚠️ Strapping Pin (Keep floating at boot) |
| **3** | GPIO 3  | Right Side, Pin 7 | ADC1_CH3, Digital I/O |
| **4** | GPIO 4  | Right Side, Pin 8 | 🎤 **I2S_DATA (SD)** - Used for microphone |
| **5** | GPIO 5  | Left Side, Pin 1 | 🎤 **I2S_BCK (SCK)** - Used for microphone |
| **6** | GPIO 6  | Left Side, Pin 2 | 🎤 **I2S_WS (WS)** - Used for microphone  |
| **7** | GPIO 7  | Left Side, Pin 3 | SS (SPI), Digital I/O |
| **8** | GPIO 8  | Left Side, Pin 4 | ⚠️ Strapping Pin (Keep floating at boot) |
| **9** | GPIO 9  | Left Side, Pin 5 | ⚠️ Strapping Pin (Keep floating at boot) |
| **10** | GPIO 10 | Left Side, Pin 6 | Digital I/O |
| **20** | GPIO 20 | Left Side, Pin 7 | UART0 RX (USB CDC) |
| **21** | GPIO 21 | Left Side, Pin 8 | UART0 TX (USB CDC) |

### INMP441 Microphone Pinout

| Pin | Name | Function |
|-----|---|---|
| 1 | VDD  | Power supply (1.8-3.3V) |
| 2 | GND  | Ground |
| 3 | SD | Serial Data (I2S_DATA) |
| 4 | SCK  | Bit Clock (I2S_BCK) |
| 5 | WS | Word Select / L/R Clock |
| 6 | L/R  | Channel select (GND = Left) |

### Wiring Connections

**ESP32-C3 → INMP441**

| ESP32-C3 Pin | INMP441 Pin | Wire Color (Suggested) |
|---|---|---|
| 3V3 | VDD | Red |
| GND | GND | Black |
| GPIO 4 | SD | Yellow |
| GPIO 5 | SCK | Blue |
| GPIO 6 | WS | Green |
| GND | L/R | Black (same ground) |

### Wiring Diagram (Text)
```
ESP32-C3 SuperMini              INMP441 Microphone
┌────────────────┐              ┌──────────────┐
│                │              │              │
│     3.3V   ●───┼──────────────┼─● VDD        │
│                │              │              │
│      GND   ●───┼──────┬───────┼─● GND        │
│                │      │       │              │
│  GPIO 4    ●───┼──────┼───────┼─● SD         │
│  (I2S_DATA)    │      │       │              │
│                │      │       │              │
│  GPIO 5    ●───┼──────┼───────┼─● SCK        │
│  (I2S_BCK)     │      │       │              │
│                │      │       │              │
│  GPIO 6    ●───┼──────┼───────┼─● WS         │
│  (I2S_WS)      │      │       │              │
│                │      └───────┼─● L/R        │
│                │              │              │
└────────────────┘              └──────────────┘
```

### Important Notes
- ⚠️ **Strapping Pins**: GPIO 2, 8, and 9 must be floating or pulled correctly during boot
- ⚠️ **L/R Pin**: Connect to GND to set microphone as Left channel
- ⚠️ **Power**: Use 3.3V output from ESP32-C3, NOT 5V
- ⚠️ **Cable Length**: Keep wires short (<15cm) to reduce noise

---

## Firmware Building

### Prerequisites

#### Install ESP-IDF (macOS)
```bash
# Install dependencies
brew install cmake ninja dfu-util

# Clone ESP-IDF
mkdir -p ~/esp
cd ~/esp
git clone -b v5.3 --recursive https://github.com/espressif/esp-idf.git

# Install ESP-IDF tools
cd esp-idf
./install.sh esp32c3

# Add to shell profile (~/.zshrc or ~/.bash_profile)
alias get_idf='. $HOME/esp/esp-idf/export.sh'
```

### Configure the Project

```bash
cd firmware/sound-level-sensor

# Source ESP-IDF environment
. $HOME/esp/esp-idf/export.sh

# Configure project (opens menu)
idf.py menuconfig
```

#### Configuration Menu Settings

Navigate to: **Sound Level Sensor Configuration**

**Required Settings:**
- **WiFi SSID**: Your WiFi network name
- **WiFi Password**: Your WiFi password  
- **Server URL**: Backend API URL (e.g., `http://192.168.68.57:3000`)
- **API Key**: Shared authentication key (use same key for all devices)

**Shared API Key Approach:**
- ⚠️ **IMPORTANT**: All devices use the **same API key** hardcoded in firmware
- This allows flashing the same firmware to all devices without modification
- Current deployment: 9 operational devices (10 purchased)
- Each device is uniquely identified by its MAC address (e.g., `08:92:72:84:1d:18`)
- Example shared key: `YOUR_API_KEY_HERE`
- Backend must have matching key in `.env` as `SHARED_API_KEY` or `API_KEY`

**Production Environment (Nova Labs):**
- **WiFi SSID**: `REDACTED_WORKSHOP_WIFI_SSID`
- **WiFi Password**: `<see CREDENTIALS.local>`
- **Server URL**: `http://xibo.space.nova-labs.org/api/sound`
- **API Key**: `<see CREDENTIALS.local>`

⚠️ **Security Note**: These credentials are for the isolated IoT network at Nova Labs. The shared API key approach is suitable for trusted, internal networks only.

**Optional Settings (ESP-IDF standard menus):**
- Serial flasher config → Flash size: 4MB
- Component config → ESP32C3-Specific → CPU frequency: 160 MHz
- Component config → FreeRTOS → Tick rate: 1000 Hz

Save and exit (press `S`, then `Q`)

### Build the Firmware

```bash
# Clean build (if needed)
idf.py fullclean

# Build firmware
idf.py build
```

**Build Output:**, ~30 seconds (incremental)

**Current Firmware Version:**
- I2S sampling: 16kHz, 32-bit
- FFT: 1024 points with Hamming window
- Frequency bands: 3 configurable ranges
- Network: WiFi with HTTP client and NTP sync
- Authentication: Shared API key
- Auto-identification: MAC address-based device ID
- Binary file: `build/sound-level-sensor.bin`
- ELF file: `build/sound-level-sensor.elf`
- Build time: ~2-5 minutes (first build)

---

## Flashing Multiple Devices

### ✨ One Build for All Devices

The firmware automatically uses each ESP32's unique MAC address as its device ID. This means you can:

1. **Build once**
2. **Flash all 10 ESP32 devices** with the same binary
3. Each device **automatically identifies itself** with its unique MAC address (e.g., `08:92:72:84:1d:18`)

### Single Device Flash

```bash
# Find device port
ls /dev/cu.usb*

# Flash and monitor
idf.py -p /dev/cu.usbmodem1201 flash monitor

# Or flash only
idf.py -p /dev/cu.usbmodem1201 flash
```

### Flashing Multiple Devices - Manual Method

Connect and flash each device one at a time:

```bash
# Device 1
idf.py -p /dev/cu.usbmodem1201 flash monitor
# Note the MAC address from serial output!

# Disconnect device 1, connect device 2
idf.py -p /dev/cu.usbmodem1401 flash monitor
# Note the MAC address!

# Repeat for each additional device
# (9 devices currently deployed)
```

### Automated Flashing Script

Create `flash_next.sh`:

```bash
#!/bin/bash
echo "===================="
echo "ESP32 Mass Flasher"
echo "===================="
echo ""
echo "Connect next ESP32 and press Enter..."
read

# Find the USB port
PORT=$(ls /dev/cu.usb* 2>/dev/null | head -n 1)

if [ -z "$PORT" ]; then
    echo "❌ No USB device found!"
    exit 1
fi

echo "✅ Found device at: $PORT"
echo ""
echo "Flashing firmware..."
cd firmware/sound-level-sensor
idf.py -p $PORT flash monitor

echo ""
echo "Device flashed! Make note of the MAC address above."
echo ""
```

Make executable and run:
```bash
chmod +x flash_next.sh
./flash_next.sh
```

### Verifying Flash

When monitoring serial output, you should see:

```
I (xxx) SOUND_SENSOR: Sound Level Sensor Starting...
I (xxx) SOUND_SENSOR: Device ID: 08:92:72:84:1d:18
I (xxx) SOUND_SENSOR: Connecting to WiFi...
I (xxx) SOUND_SENSOR: WiFi connected
I (xxx) SOUND_SENSOR: IP address: 192.168.1.XXX
I (xxx) SOUND_SENSOR: Fetching configuration from server...
```

**Record each MAC address** - you'll need them for registration!

### Flash Time Estimates
- **Per device**: ~30 seconds flash + 1 minute testing = ~90 seconds
- **Single device**: ~2-3 minutes
- **Multiple devices**: ~2-3 minutes per device (sequential)
- **9 operational devices**: ~15-20 minutes total

---

## Device Registration

**⚠️ Important: Shared API Key System**

This system uses a **shared API key** approach where all devices use the same API key compiled into the firmware. Each device is uniquely identified by its MAC address.

### How Device IDs Work

Each ESP32 has a **factory-burned unique MAC address** that cannot be changed. The firmware reads this at startup and uses it as the device ID in format: `08:92:72:84:1d:18`

### Registration Methods

#### Option 1: Frontend Web Interface (Recommended)

1. **Start Backend Server**
   ```bash
   cd backend
   npm start
   ```

2. **Open Frontend** in browser: `http://localhost:3000`

3. **Navigate** to "Devices" tab

4. **Click** "Register Device" button

5. **Fill in form:**
   - **Device ID**: MAC address from serial output (e.g., `08:92:72:84:1d:18`)
   - **MAC Address**: Same as device ID
   - **Name**: Friendly name (e.g., "Front Door Sensor", "Manufacturing Floor 1")
   - **Location**: Physical location (e.g., "Building A - Main Entrance")

6. **Save** - Backend automatically assigns the shared API key (matches firmware CONFIG_API_KEY)

7. **Verify** - Device should appear in devices list and start sending data within 5-10 seconds

#### Option 2: Direct API Registration

```bash
curl -X POST http://localhost:3000/api/devices/register \
  -H "Content-Type: application/json" \
  -d '{
    "device_id": "08:92:72:84:1d:18",
    "mac_address": "08:92:72:84:1d:18",
    "name": "Sensor 01",
    "location": "Building A - Floor  from server (3 bands: 20-200Hz, 200-2000Hz, 2000-8000Hz)
- Apply calibration settings (if configured)
- Start sending measurements every 5 seconds
- Sync time via NTP
- Reconnect automatically if WiFi drops

### Current Deployment Status

**Operational Devices:** 9 sensors actively sending data
**Data Collection:** Real-time measurements every 5 seconds
**Features Active:**
- dB level monitoring
- 3-band frequency analysis
- Timestamp synchronization
- Automatic reconnection
- Calibration offset applied

### Device List Example

| Device ID           | Name                  | Location                   |
|---------------------|-----------------------|----------------------------|
| 08:92:72:84:1d:18   | Front Entrance        | Building A - Main Door     |
| 08:92:72:84:2a:3c   | Conference Room A     | Building A - 2nd Floor     |
| 08:92:72:84:1f:92   | Manufacturing Floor   | Building B - Production    |
| ... (6 more)        | ...                   | ...                        |

---

## OTA Firmware Updates

**✅ Over-The-Air (OTA) Update Capability Active**

The system supports remote firmware updates without physical access to devices. This allows bug fixes, feature additions, and configuration updates to be deployed to all sensors over WiFi.

### How OTA Updates Work

1. **Build New Firmware**
   ```bash
   cd firmware/sound-level-sensor
   # Update FIRMWARE_VERSION in main.c (e.g., "1.0.0" → "1.0.1")
   idf.py build
   ```

2. **Upload to Backend**
   ```bash
   curl -X POST "http://localhost:3000/api/firmware/upload?version=1.0.1&description=Bug%20fixes" \
        -H "Content-Type: application/octet-stream" \
        --data-binary "@build/sound-level-sensor.bin"
   ```

3. **Automatic Distribution**
   - Devices check for updates **every hour**
   - First check occurs **5 minutes** after boot
   - Update downloaded automatically if newer version available
   - Device reboots and applies update
   - **Automatic rollback** if update fails

### OTA Configuration

**Partition Table:**
- **ota_0**: 1.5 MB - Primary app partition
- **ota_1**: 1.5 MB - Secondary app partition (for updates)
- **otadata**: 8 KB - OTA state tracking
- Configured in `sdkconfig.defaults`: `CONFIG_PARTITION_TABLE_TWO_OTA=y`

**Flash Requirements:**
- **Minimum**: 4 MB flash (ESP32-C3 SuperMini has 4 MB)
- **Current firmware size**: ~600-800 KB
- **Maximum safe size**: ~1.4 MB per partition

**Update Protocol:**
- **HTTP** (not HTTPS) for simplicity on trusted networks
- **Authentication**: API key header required
- **Timeout**: 30 seconds for download
- **Buffer size**: 1024 bytes

### Managing Firmware Versions

**Check Current Versions:**
```bash
# View all available firmware versions
curl http://localhost:3000/api/firmware/versions

# Get latest version info
curl http://localhost:3000/api/firmware/latest
```

**Simulate Device Update Check:**
```bash
# Check if update available for device running v1.0.0
curl "http://localhost:3000/api/firmware/check?device_id=08:92:72:84:1d:18&current_version=1.0.0"
```

**Response (update available):**
```json
{
  "updateAvailable": true,
  "version": "1.0.1",
  "url": "/api/firmware/download/1.0.1",
  "filename": "sound-sensor-1.0.1.bin",
  "size": 823456,
  "releaseDate": "2026-02-10T12:00:00.000Z",
  "description": "Bug fixes and performance improvements"
}
```

**Response (no update):** `204 No Content`

### Firmware Version Tracking

**In Firmware (`main.c`):**
```c
#define FIRMWARE_VERSION "1.0.0"
```

**Version Naming (Semantic Versioning):**
- **MAJOR.MINOR.PATCH** (e.g., `1.2.3`)
- **MAJOR**: Breaking changes or major features
- **MINOR**: Backward-compatible new features
- **PATCH**: Backward-compatible bug fixes

### Safety Features

1. **Dual Partitions**: Two app partitions allow safe rollback
2. **Automatic Rollback**: If new firmware fails to boot, device reverts to previous version
3. **Verification**: Device marks firmware valid only after successful operation
4. **SHA-256 Checksums**: Firmware integrity verified during download
5. **Atomic Updates**: Update is complete or not applied (no partial updates)

### Staged Rollout Strategy

For production deployments:

1. **Build and upload** new firmware to backend
2. **Monitor first device** - Usually updates within 60 minutes
3. **Verify stability** for 24 hours
4. **Natural rollout** - Remaining devices update on their hourly check
5. **Force immediate update** - Reboot devices to trigger immediate check

**Example Monitoring:**
```bash
# Device serial output
Checking for firmware updates...
Current firmware version: 1.0.0
Update available: 1.0.1
Starting OTA update to version 1.0.1...
OTA update successful! Rebooting...

# After reboot
Firmware Version: 1.0.1
Running partition: ota_1
OTA update pending verification - marking as valid
```

### Troubleshooting OTA Updates

**Device Not Updating:**
- Check WiFi connectivity
- Verify backend is serving firmware: `curl http://localhost:3000/api/firmware/versions`
- Check device logs during update check interval
- Confirm version numbers: device must be < backend version

**Update Failed:**
- Device automatically rolls back to previous version
- Check serial logs for specific error
- Common causes:
  - Firmware too large for partition (max ~1.4 MB)
  - Network timeout (increase timeout in code)
  - Invalid binary format
  - Corrupted download

**Manual Recovery:**
```bash
# Flash via USB if OTA fails completely
cd firmware/sound-level-sensor
idf.py -p /dev/cu.usbmodem1201 flash
```

### OTA API Endpoints

| Endpoint | Method | Description |
|---|---|---|
| `/api/firmware/check` | GET | Check if update available |
| `/api/firmware/download/:version` | GET | Download firmware binary |
| `/api/firmware/versions` | GET | List all versions |
| `/api/firmware/latest` | GET | Get latest version |
| `/api/firmware/upload` | POST | Upload new firmware |
| `/api/firmware/:version` | DELETE | Remove firmware version |

### Monitoring Updates

**Backend Logs:**
```
Firmware update check from 08:92:72:84:1d:18: v1.0.0
Update available for 08:92:72:84:1d:18: v1.0.1
Serving firmware v1.0.1 (823456 bytes)
```

**Device Logs:**
```
OTA task started
Checking for firmware updates...
Current firmware version: 1.0.0
Update check response: 200, content_length: 145
Starting OTA update to version 1.0.1
OTA update successful! Rebooting...
```

### Best Practices

1. **Test firmware thoroughly** before uploading to production
2. **Use descriptive release notes** in upload description
3. **Monitor first device** for 24 hours before wide rollout
4. **Keep one previous version** available for quick rollback
5. **Document changes** in firmware version comments
6. **Backup current firmware** before major updates

---

## Firmware Features

### Current Capabilities

**Audio Processing:**
- 16kHz sampling rate (optimal for speech/environmental sounds)
- 32-bit I2S interface with INMP441 microphone
- 1024-point FFT with Hamming window
- dB calculation: 20 * log10(RMS amplitude)
- Configurable calibration offset

**Frequency Band Analysis:**
- Band 1: 20-200 Hz (Low frequencies - vehicle noise, machinery)
- Band 2: 200-2000 Hz (Mid frequencies - speech, music)
- Band 3: 2000-8000 Hz (High frequencies - alarms, mechanical sounds)
- Per-band dB levels calculated separately
- Configurable via backend API

**Network Features:**
- WiFi auto-connect with retry logic
- HTTP client with exponential backoff (3 retries)
- NTP time synchronization
- JSON payload formatting
- Shared API key authentication
- MAC address auto-detection

**Data Transmission:**
- Measurements sent every 5 seconds
- Timestamp: ISO 8601 format
- Overall dB + 3 frequency bands
- Reliable delivery with retry mechanism
- Backend validates and stores data

**Error Handling:**
- WiFi disconnect recovery
- HTTP timeout handling (30 seconds)
- Microphone failure detection
- Automatic restart on critical errors
- Serial logging for debugging

### Device List Example

| Device ID | Name | Location |
|---|---|---|
| 08:92:72:84:1d:18 | Front Entrance | Building A - Main Door |
| 08:92:72:84:2a:3c | Conference Room A | Building A - 2nd Floor |
| 08:92:72:84:1f:92 | Manufacturing Floor | Building B - Production |
| 08:92:72:85:3b:1a | Loading Dock | Building B - Rear Entrance |
| 08:92:72:86:4c:2b | Office Area | Building A - 3rd Floor |
| ... (5 more) | ... | ... |

---

## Troubleshooting

### ESP-IDF Not Found
```bash
# Re-source the environment
. $HOME/esp/esp-idf/export.sh

# Or add to ~/.zshrc:
alias get_idf='. $HOME/esp/esp-idf/export.sh'
source ~/.zshrc
get_idf
```

### Build Errors

**Error: `idf.py: command not found`**
```bash
. $HOME/esp/esp-idf/export.sh
```

**Error: `CMake Error`**
```bash
brew install cmake ninja
idf.py fullclean
idf.py build
```

**Error: `esp_driver_i2s not found`**
- Update ESP-IDF to v5.3+: `cd ~/esp/esp-idf && git pull`

### Flash Errors

**Error: `Failed to connect to ESP32-C3`**
1. Check USB cable (try different cable)
2. Hold BOOT button while connecting USB
3. Try different USB port
4. Check device appears: `ls /dev/cu.usb*`

**Error: `A fatal error occurred: Could not open port`**
```bash
# Kill any process using the port
lsof | grep usbmodem
kill -9 <PID>

# Or unplug and replug USB
```

**Error: `Timeout waiting for packet content`**
- Device may be in deep sleep
- Unplug and replug USB
- Hold BOOT button and press RESET

### Runtime Errors

**Device ID not showing**
```
I (xxx) SOUND_SENSOR: Device ID: 08:92:72:84:1d:18
```
- If not shown, firmware wasn't rebuilt with MAC address changes
- Run `idf.py fullclean && idf.py build`

**WiFi not connecting**
- Check SSID and password in menuconfig
- Verify 2.4 GHz network (ESP32-C3 doesn't support 5 GHz)
- Check WiFi signal strength
- Monitor serial output for error details

**Cannot reach server**
- Verify server URL in menuconfig
- Check backend is running: `curl http://192.168.68.57:3000/health`
- Ping server from ESP32 network
- Check firewall settings

**Device not sending measurements**
- **Check device is registered** in backend:
  ```bash
  curl http://localhost:3000/api/devices/08:92:72:84:1d:18
  ```
- **Verify API key matches** between firmware and backend:
  - Firmware: Check `sdkconfig` for `CONFIG_API_KEY`
  - Backend: Check `.env` for `SHARED_API_KEY` or `API_KEY`
  - **They must match exactly!**
- **Monitor backend logs**: `cd backend && npm start`
- **Check serial output** for HTTP error codes:
  - 401: Missing/invalid authorization header
  - 403: Invalid API key (key mismatch between firmware and backend)
  - 404: Device not registered in backend

### Serial Monitor Commands

**View logs:**
```bash
idf.py -p /dev/cu.usbmodem1201 monitor
```

**Exit monitor:** `Ctrl+]`

**Clear screen and reset:** `Ctrl+T` then `Ctrl+R`

**Filter logs:**
```bash
idf.py monitor -p /dev/cu.usbmodem1201 | grep SOUND_SENSOR
```

### Hardware Issues

**No audio readings**
- Check INMP441 wiring (especially GND and 3.3V)
- Verify GPIO pins match firmware (4, 5, 6)
- Check L/R pin connected to GND
- Test microphone with loud sound

**Erratic readings**
- Shorten wire connections (<15cm)
- Twist I2S signal wires together
- Add 0.1µF capacitor near microphone VDD
- Keep away from EMI sources

**Device keeps resetting**
- Power supply issue - use quality USB cable
- Remove connections to strapping pins (GPIO 2, 8, 9)
- Check for short circuits

---

## Quick Reference Card

### Wiring (ESP32-C3 → INMP441)
```
3.3V → VDD
GND  → GND  
GPIO4 → SD   (I2S Data)
GPIO5 → SCK  (I2S Clock)
GPIO6 → WS   (Word Select)
GND  → L/R  (Channel Select)
```

### Common Commands
```bash
# Setup environment
. $HOME/esp/esp-idf/export.sh

# Configure
idf.py menuconfig

# Build
idf.py build

# Flash and monitor
idf.py -p /dev/cu.usbmodem1201 flash monitor

# Monitor only
idf.py -p /dev/cu.usbmodem1201 monitor

# Exit monitor
Ctrl+]
```

### Device ID Format
- MAC address: `08:92:72:84:1d:18`
- Unique per device
- Auto-generated at startup
- Used for registration and API calls

---

**Document Version**: 1.1  
**Last Updated**: February 10, 2026

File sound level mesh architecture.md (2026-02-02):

# Sound Level Mesh System - Architecture Document

## Document Information
- **Version:** 1.2
- **Date:** 2024 (Updated: February 1, 2026)
- **Status:** Active - Production Implementation
- **Author:** Engineering Team
- **Related Documents:** Sound Level Mesh System PRD
- **Latest Updates:** Dynamic frequency band configuration, enhanced visualization, analytics dashboard

---

## Important Note: PCB Design Approach

**Date:** January 30, 2026

**Lesson Learned:** Initial attempts to automate KiCad PCB generation through Python scripting proved overly complex and ultimately unsuccessful. While the KiCad Python API (pcbnew) exists, the complexity of automated PCB generation, combined with the limitations of AI assistance in this specialized domain, made this approach impractical.

**Decision:** For this project, we will use **breadboard or protoboard** assembly for the ESP32-C3 and INMP441 microphone modules. This approach is:
- Faster to implement and test
- More flexible for prototyping and debugging
- Appropriate for a 10-device deployment
- Easier to modify during development
- Well-documented in the Component Pinout Reference

**Recommendation:** For future projects requiring custom PCBs, consider:
- Manual PCB design using KiCad GUI (not automated)
- Working with professional PCB design services
- Using off-the-shelf breakout boards and protoboard
- Only investing in custom PCB design for production-scale deployments (100+ units)

The [Component Pinout Reference](COMPONENT_PINOUT_REFERENCE.md) document contains all necessary wiring information for breadboard/protoboard assembly.

---

## 1. Executive Summary

This document describes the technical architecture for the Sound Level Mesh System, a distributed monitoring solution consisting of 10 ESP32-based WiFi sensor devices communicating with a central web server. The architecture is designed for real-time sound level monitoring, configurable frequency band analysis, and flexible data management.

### Architecture Principles
- **Centralized Processing:** All data processing and storage occurs on the central server
- **Star Topology:** ESP32 devices connect directly to the central server via WiFi
- **RESTful Communication:** HTTP-based API for device-server communication (unencrypted)
- **Web-Based Interface:** Browser-accessible monitoring and administration
- **Configurable Design:** Flexible frequency band and retention period configuration

---

## 2. System Architecture Overview

### 2.1 High-Level Architecture

```
┌─────────────────────────────────────────────────────────────┐
│                    WiFi Network (802.11)                     │
└─────────────────────────────────────────────────────────────┘
                            │
        ┌───────────────────┼───────────────────┐
        │                   │                   │
┌───────▼──────┐   ┌────────▼────────┐   ┌─────▼──────┐
│  ESP32       │   │   ESP32         │   │  ESP32     │
│  Device 1    │   │   Device 2      │   │  Device N  │
│              │   │                 │   │  (up to 10)│
│  [Firmware]  │   │  [Firmware]     │   │  [Firmware]│
└───────┬──────┘   └────────┬────────┘   └─────┬──────┘
        │                   │                   │
        └───────────────────┼───────────────────┘
                            │
                    ┌───────▼────────┐
                    │  Central Web   │
                    │     Server     │
                    │                │
                    │  ┌──────────┐ │
                    │  │  Web App │ │
                    │  │ (Frontend)│ │
                    │  └──────────┘ │
                    │  ┌──────────┐ │
                    │  │  Backend │ │
                    │  │   API    │ │
                    │  └──────────┘ │
                    │  ┌──────────┐ │
                    │  │File System│ │
                    │  │  Storage  │ │
                    │  └──────────┘ │
                    └───────────────┘
```

### 2.2 Component Overview

The system consists of three main components:

1. **ESP32 Sensor Devices (10 units)**
   - Custom firmware for audio sampling and processing
   - WiFi connectivity for data transmission
   - Local audio processing (FFT for frequency bands)

2. **Central Web Server**
   - Backend API server
   - Web application (monitoring and admin interfaces)
   - File-based storage for data storage and configuration

3. **WiFi Infrastructure**
   - Access point/router connecting devices to server
   - Network security (WPA2/WPA3)

---

## 3. Component Architecture

### 3.1 ESP32 Device Architecture

#### Hardware Components
- **ESP32-C3 Microcontroller (Purchased)**
  - Single-core RISC-V 160 MHz processor
  - WiFi 802.11 b/g/n (2.4 GHz)
  - Bluetooth 5.0 LE
  - I2S interface for digital microphone connection (to be verified)
  - GPIO pins for sensor connections
  - USB-C interface
  - **Status:** 10 units purchased, awaiting delivery

- **Audio Input - MH-ET LIVE INMP441 I2S Digital Microphone Module (Purchased)**
  - **Status:** ✅ 10 units purchased, awaiting delivery
  - **Module Specifications:**
    - Omnidirectional MEMS microphone
    - Low noise, high precision design
    - I2S digital interface (no ADC required)
    - PDM (Pulse Density Modulation) output converted to I2S format
    - Operating voltage: 1.8V - 3.3V (typically 3.3V)
    - Sample rate: Up to 48 kHz
    - Bit depth: 24-bit
    - Signal-to-Noise Ratio (SNR): 65 dB
    - Sensitivity: -26 dBFS
  - **Pin Connections (INMP441 to ESP32-C3 - Verified):**
    - VDD → ESP32-C3 3.3V
    - GND → ESP32-C3 GND
    - SCK (Serial Clock) → ESP32-C3 GPIO 5 (I2S_BCLK)
    - WS (Word Select) → ESP32-C3 GPIO 6 (I2S_WS)
    - SD (Serial Data) → ESP32-C3 GPIO 4 (I2S_DATA)
    - L/R (Left/Right select) → ESP32-C3 GND (for mono/left channel)
  - **Connection Type:** Direct I2S digital connection (no analog components required)
  - **Status:** ✅ Verified and implemented in firmware. I2S peripheral confirmed functional on ESP32-C3.

- **Power Supply**
  - USB power (5V) or external power adapter
  - Optional: Battery backup for temporary operation

#### Firmware Architecture

```
┌─────────────────────────────────────────┐
│         ESP32 Firmware Stack             │
├─────────────────────────────────────────┤
│  Application Layer                       │
│  ├─ Audio Sampling                       │
│  ├─ FFT Processing (Frequency Bands)     │
│  ├─ dB Calculation                       │
│  ├─ Data Packaging                       │
│  └─ WiFi Communication                   │
├─────────────────────────────────────────┤
│  System Services                         │
│  ├─ WiFi Manager                         │
│  ├─ HTTP Client                          │
│  ├─ NTP Time Sync                        │
│  ├─ Configuration Manager                │
│  └─ Error Handling & Retry Logic         │
├─────────────────────────────────────────┤
│  Hardware Abstraction                    │
│  ├─ Audio Driver (I2S)                   │
│  ├─ WiFi Driver                          │
│  └─ System Timer                         │
├─────────────────────────────────────────┤
│  ESP-IDF Framework                        │
└─────────────────────────────────────────┘
```

#### Firmware Modules

1. **HTTP Communication Module**
   - **Connection Management:**
     - Timeout: 10 seconds per attempt
     - Maximum retries: 3 attempts
     - Retry delay: Exponential backoff (2s, 4s, 8s)
     - Keep-alive: Disabled (fresh connections per request)
     - Transport type: HTTP_TRANSPORT_OVER_TCP
     - Connection header: "Connection: close"
   - **Error Handling:**
     - Automatic retry on connection failures
     - Detailed error logging with symbols (✓/✗)
     - Handles ESP_ERR_HTTP_CONNECT errors
     - Recovers from network interruptions
   - **Data Submission:**
     - POST to /api/data/measurements endpoint
     - JSON payload with device_id, timestamp, dB levels, frequency bands
     - Bearer token authentication
     - Content-Type: application/json
   - **Network Considerations:**
     - Works on standard WiFi networks (WPA2/WPA3)
     - Compatible with DHCP IP assignment
     - May experience issues with VPN software on server machine
     - Requires both devices on same network or proper routing

2. **Audio Sampling Module**
   - **I2S Interface Configuration for INMP441:**
     - Sample rate: 16 kHz (INMP441 supports up to 48 kHz)
     - Bit depth: 32-bit containers (24-bit data left-aligned)
     - Channel format: Mono (left channel)
     - Communication format: I2S MSB standard mode
     - DMA buffer size: 1024 samples
     - DMA buffer count: 4
     - GPIO Pins: BCLK=GPIO5, WS=GPIO6, DATA=GPIO4
   - Continuous audio sampling via I2S DMA
   - 24-bit audio data reception from INMP441 in 32-bit containers
   - Buffer management for audio data (1024 samples per read)
   - Interrupt-driven I2S DMA for real-time processing
   - Data format conversion: 24-bit I2S data (right-shifted by 8) to float normalized -1.0 to 1.0
   - **Windowing:**
     - Hamming window applied before FFT
     - Reduces spectral leakage
     - Implemented in firmware

2. **Audio Processing Module**
   - **FFT (Fast Fourier Transform) for frequency analysis:**
     - FFT size: 256-1024 points (configurable, power of 2)
     - **Windowing Function:**
       - Apply window function to reduce spectral leakage
       - Window types: Hamming, Hanning, or Blackman (recommended: Hamming)
       - Window applied to time-domain samples before FFT
       - Compensates for window gain in frequency domain calculations
     - **Overlap Processing (Optional):**
       - Overlap-add or overlap-save technique for continuous analysis
       - 50% overlap recommended for smooth frequency response
       - Reduces edge effects from windowing
   - **Frequency Domain Processing:**
     - Magnitude calculation from FFT output
     - Power spectral density (PSD) computation
     - Frequency bin to Hz conversion: `frequency = (bin_index × sample_rate) / FFT_size`
   - dB calculation from frequency domain data
   - Frequency band filtering and level calculation
   - **Calibration Application:**
     - Apply calibration offset to overall dB measurement
     - Apply per-band calibration offsets (if configured)
     - Store both raw and calibrated values (optional)
   - A-weighting/C-weighting (optional)

3. **Configuration Module**
   - Device registration and authentication
   - Frequency band configuration storage (EEPROM/Flash)
   - Measurement interval configuration
   - **Calibration Configuration:**
     - Calibration offset storage (EEPROM/Flash)
     - Per-band calibration offset storage (if supported)
     - Calibration enable/disable flag
   - WiFi credentials management

4. **Communication Module**
   - HTTP client for API communication (unencrypted, using esp_http_client)
   - Data transmission to central server
   - Configuration retrieval from server
   - Retry logic and error handling
   - Connection status monitoring
   - WiFi connection management (esp_wifi)

5. **System Management Module**
   - NTP time synchronization
   - Watchdog timer
   - Error logging
   - OTA update capability (future)

### 3.2 Central Web Server Architecture

#### Server Components (Ubuntu 20.04 with Nginx)

```
┌─────────────────────────────────────────────────────┐
│         Ubuntu 20.04 Server with Nginx               │
├─────────────────────────────────────────────────────┤
│                                                      │
│  ┌──────────────────────────────────────────────┐  │
│  │         Nginx Web Server (Port 80)           │  │
│  │  - Reverse Proxy                             │  │
│  │  - Static File Serving (Frontend)            │  │
│  │  - API Proxy to Backend                      │  │
│  └──────────────┬───────────────────────────────┘  │
│                 │                                    │
│  ┌──────────────▼───────────────────────────────┐  │
│  │         Web Application (Frontend)            │  │
│  │  ┌──────────────┐      ┌──────────────┐      │  │
│  │  │  Monitoring  │      │    Admin     │      │  │
│  │  │    Pages     │      │    Pages     │      │  │
│  │  └──────────────┘      └──────────────┘      │  │
│  └──────────────────────────────────────────────┘  │
│                                                      │
│  ┌──────────────────────────────────────────────┐  │
│  │         Backend API Server (Port 3000)       │  │
│  │  ┌──────────┐  ┌──────────┐  ┌──────────┐   │  │
│  │  │  Device  │  │   Data   │  │   Config │   │  │
│  │  │   API    │  │   API    │  │   API    │   │  │
│  │  └──────────┘  └──────────┘  └──────────┘   │  │
│  └──────────────┬───────────────────────────────┘  │
│                 │                                    │
│  ┌──────────────▼───────────────────────────────┐  │
│  │         File Storage Layer                    │  │
│  │  ┌──────────────┐      ┌──────────────┐      │  │
│  │  │  JSON Config │      │ CSV/JSON     │      │  │
│  │  │    Files     │      │ Measurements │      │  │
│  │  └──────────────┘      └──────────────┘      │  │
│  │  Location: /var/www/sound-monitoring/data/   │  │
│  └──────────────────────────────────────────────┘  │
│                                                      │
└─────────────────────────────────────────────────────┘
```

#### Backend API Server

**Technology Stack Options:**
- **Option 1:** Node.js + Express
- **Option 2:** Python + Flask/FastAPI
- **Option 3:** Go + Gin/Echo

**API Endpoints:**

1. **Device Management API**
   - `POST /api/devices/register` - Register new device
   - `GET /api/devices` - List all devices
   - `GET /api/devices/:id` - Get device details
   - `PUT /api/devices/:id/config` - Update device configuration
   - `GET /api/devices/:id/status` - Get device status

2. **Data Collection API**
   - `POST /api/data/measurements` - Receive measurement data from devices
   - `GET /api/data/devices/:id` - Get measurements for specific device
   - `GET /api/data/devices/:id/bands` - Get frequency band data
   - `GET /api/data/devices/:id/history` - Get historical data

3. **Configuration API**
   - `GET /api/config/devices/:id/frequency-bands` - Get frequency band config
   - `PUT /api/config/devices/:id/frequency-bands` - Update frequency bands
   - `GET /api/config/retention` - Get retention period settings
   - `PUT /api/config/retention` - Update retention period
   - `GET /api/config/devices/:id/calibration` - Get calibration settings
   - `PUT /api/config/devices/:id/calibration` - Update calibration offsets
   - `POST /api/config/devices/:id/calibration/reset` - Reset calibration to zero

4. **Monitoring API**
   - `GET /api/monitoring/devices/:id/realtime` - Real-time data stream
   - `GET /api/monitoring/summary` - System summary
   - `GET /api/monitoring/health` - System health check

#### Web Application (Frontend)

**Technology Stack:**
- **Framework:** React, Vue.js, or vanilla JavaScript
- **Charts/Visualization:** Chart.js, D3.js, or Plotly
- **HTTP Client:** Axios or Fetch API
- **Real-time Updates:** WebSocket or Server-Sent Events (SSE)
- **Responsive Design:** CSS Grid, Flexbox, or responsive framework (Bootstrap, Tailwind CSS)
- **Mobile Optimization:** Touch events, responsive breakpoints, mobile-first design

**Application Structure:**

1. **Monitoring Dashboard**
   - Real-time sound level display (dB)
   - Frequency band visualization
   - Historical data charts
   - Device status indicators
   - Time range selector
   - **Responsive Layout:**
     - Desktop view: Multi-column layout, larger charts, detailed information
     - Mobile view: Single column layout, compact charts, touch-optimized controls

2. **Admin Interface**
   - Device registration form
   - Device list and management
   - Frequency band configuration interface
   - **Sensor Calibration Interface:**
     - Calibration offset input (dB)
     - Per-band calibration offset input (optional)
     - Calibration date and notes
     - Calibration enable/disable toggle
     - View raw vs calibrated values
   - Data retention configuration
   - System settings
   - **Responsive Layout:**
     - Desktop view: Full form layouts, side-by-side panels
     - Mobile view: Stacked forms, collapsible sections, touch-friendly inputs

3. **Components:**
   - Device status widget
   - Real-time chart component
   - Historical chart component
   - Frequency band editor
   - Configuration form components
   - **Responsive Components:**
     - Adaptive navigation (hamburger menu for mobile)
     - Responsive tables (scrollable or card view on mobile)
     - Touch-optimized buttons and controls

### 3.3 File-Based Storage Architecture

#### File Structure Design

**Storage Organization:**

```
data/
├── config/
│   ├── devices.json              # Device registry (array of device objects)
│   ├── device_configs/
│   │   ├── esp32_001.json       # Per-device configuration
│   │   ├── esp32_002.json
│   │   └── ...
│   ├── frequency_bands/
│   │   ├── esp32_001.json       # Frequency band configs per device
│   │   └── ...
│   ├── system_settings.json      # Global system settings
│   └── users.json                # User accounts (optional)
├── measurements/
│   ├── esp32_001/
│   │   ├── 2024-01-15.csv       # Daily measurement files (CSV format)
│   │   ├── 2024-01-16.csv
│   │   └── ...
│   ├── esp32_002/
│   │   └── ...
│   └── ...
└── logs/
    └── application.log
```

#### File Format Specifications

**1. Device Registry (`config/devices.json`):**

```json
[
  {
    "id": "esp32_001",
    "name": "Building A - Floor 1",
    "mac_address": "AA:BB:CC:DD:EE:FF",
    "registered_at": "2024-01-10T10:00:00Z",
    "last_seen": "2024-01-15T14:30:00Z",
    "status": "online",
    "location": "Building A, Floor 1",
    "created_by": "admin"
  }
]
```

**2. Device Configuration (`config/device_configs/esp32_001.json`):**

```json
{
  "device_id": "esp32_001",
  "measurement_interval": 5,
  "sampling_rate": 16000,
  "retention_days": 7,
  "calibration": {
    "offset_db": 2.5,
    "enabled": true,
    "date": "2024-01-10T14:30:00Z",
    "notes": "Calibrated using reference sound level meter"
  }
}
```

**3. Frequency Bands Configuration (`config/frequency_bands/esp32_001.json`):**

```json
[
  {
    "band_number": 1,
    "start_frequency": 20,
    "end_frequency": 200,
    "calibration_offset_db": 2.2
  },
  {
    "band_number": 2,
    "start_frequency": 200,
    "end_frequency": 2000,
    "calibration_offset_db": 0.0
  }
]
```

**4. System Settings (`config/system_settings.json`):**

```json
{
  "default_retention_days": 7,
  "max_devices": 10,
  "system_name": "Sound Monitoring System"
}
```

**5. Measurement Data (`measurements/esp32_001/2024-01-15.csv`):**

```csv
timestamp,db_level,db_level_raw,band_1_level,band_1_raw,band_2_level,band_2_raw
2024-01-15T10:00:00Z,65.5,63.0,45.2,43.0,52.1,50.0
2024-01-15T10:00:05Z,66.2,63.7,46.1,43.9,52.8,50.7
2024-01-15T10:00:10Z,64.8,62.3,44.5,42.3,51.5,49.4
...
```

**Alternative: JSON Measurement Format (`measurements/esp32_001/2024-01-15.json`):**

```json
[
  {
    "timestamp": "2024-01-15T10:00:00Z",
    "db_level": 65.5,
    "db_level_raw": 63.0,
    "frequency_bands": [
      {
        "band_number": 1,
        "level": 45.2,
        "level_raw": 43.0
      },
      {
        "band_number": 2,
        "level": 52.1,
        "level_raw": 50.0
      }
    ]
  }
]
```

#### Data Retention Strategy

- **Automatic Purging:** Background job runs daily to delete data older than retention period
- **Per-Device Retention:** Each device can have custom retention period
- **Global Default:** System-wide default retention (7 days)
- **Retention Job:** Scheduled task (cron job or task scheduler)

---

## 4. Data Flow Architecture

### 4.1 Measurement Data Flow

```
ESP32 Device                    Central Server
     │                               │
     │  1. Audio Sampling            │
     │     (Continuous)               │
     │                               │
     │  2. Anti-Aliasing Filter      │
     │     - Apply low-pass filter   │
     │     - Cutoff at Nyquist freq  │
     │                               │
     │  3. Apply Windowing Function  │
     │     - Hamming/Hanning window  │
     │     - Reduce spectral leakage │
     │                               │
     │  4. FFT Processing            │
     │     - Calculate frequency     │
     │       domain representation   │
     │     - Calculate dB             │
     │     - Calculate frequency      │
     │       band levels              │
     │                               │
     │  5. Apply Calibration         │
     │     - Apply dB offset         │
     │     - Apply per-band offsets  │
     │     - Store raw values        │
     │                               │
     │  4. Package Data              │
     │     - Timestamp               │
     │     - Device ID               │
     │     - dB level (calibrated)   │
     │     - dB level (raw)          │
     │     - Frequency band levels   │
     │       (calibrated & raw)      │
     │                               │
     │  4. HTTP POST                 │
     │  ────────────────────────────>│
     │  POST /api/data/measurements  │
     │                               │
     │                               │  5. Validate & Store
     │                               │     - Validate data
     │                               │     - Write to file
     │                               │     - Update device status
     │                               │
     │  6. HTTP Response             │
     │  <────────────────────────────│
     │  200 OK / Error               │
     │                               │
     │  7. Update Configuration      │
     │     (if needed)               │
     │                               │
```

### 4.2 Dynamic Configuration Flow (Updated February 2026)

```
Admin User                    Web Server                    ESP32 Device
     │                            │                              │
     │  1. Configure Frequency    │                              │
     │     Bands via Dashboard    │                              │
     │     (Click ⚙️ on device)   │                              │
     │                            │                              │
     │  2. Save Configuration     │                              │
     │  ────────────────────────> │                              │
     │  PUT /api/config/devices/:id/frequency-bands               │
     │                            │                              │
     │                            │  3. Store in Device JSON     │
     │                            │     (data/devices/{id}.json)  │
     │                            │                              │
     │                            │                              │
     │                            │  4. Device Startup:          │
     │                            │     Fetch Configuration      │
     │                            │  <───────────────────────────│
     │                            │  GET /api/config/devices/     │
     │                            │      Sensor%2001/frequency-bands│
     │                            │                              │
     │                            │  5. Return Configuration     │
     │                            │  ───────────────────────────>│
     │                            │  {frequency_bands: [...],    │
     │                            │   calibration_offset_db: 1}  │
     │                            │                              │
     │                            │                              │  6. Apply Configuration
     │                            │                              │     - Update frequency bands
     │                            │                              │     - Update calibration
     │                            │                              │     - Log changes
     │                            │                              │
     │                            │  7. Periodic Refresh         │
     │                            │     (Every 100 measurements  │
     │                            │      ~5 minutes)             │
     │                            │  <───────────────────────────│
     │                            │  GET /api/config/devices/...  │
     │                            │                              │
     │  8. View Live Data with    │                              │
     │     Updated Configuration  │                              │
     │  <──────────────────────── │                              │
     │                            │                              │
```

**Key Features:**
- **Startup Configuration Fetch:** Device fetches configuration immediately after WiFi connection
- **Periodic Refresh:** Configuration automatically re-fetched every ~5 minutes (100 measurements)
- **Per-Sensor Settings:** Each sensor stores and applies its own unique configuration
- **Runtime Updates:** No firmware reflash needed for frequency band changes
- **URL Encoding:** Device ID automatically URL-encoded in firmware to handle spaces
- **Calibration Sync:** Both frequency bands and calibration offsets fetched together

### 4.3 Real-Time Monitoring Flow

```
Web Browser                    Web Server                    File System
     │                            │                              │
     │  1. Load Dashboard         │                              │
     │  ────────────────────────> │                              │
     │                            │                              │
     │                            │  2. Read Recent Data Files  │
     │                            │  ──────────────────────────> │
     │                            │                              │
     │                            │  3. Return Data             │
     │                            │  <────────────────────────── │
     │                            │                              │
     │  4. Display Initial Data   │                              │
     │  <──────────────────────── │                              │
     │                            │                              │
     │  5. Establish WebSocket/   │                              │
     │     SSE Connection         │                              │
     │  ────────────────────────> │                              │
     │                            │                              │
     │                            │  6. Subscribe to Updates    │
     │                            │                              │
     │                            │  7. New Data Written to File │
     │                            │  <────────────────────────── │
     │                            │                              │
     │  8. Receive Real-Time      │                              │
     │     Update                │                              │
     │  <──────────────────────── │                              │
     │                            │                              │
```

---

## 5. Network Architecture

### 5.1 Network Topology

```
                    Internet (Optional)
                         │
                         │
              ┌──────────▼──────────┐
              │   Router/Gateway    │
              │   (WiFi Access      │
              │    Point)           │
              └──────────┬──────────┘
                         │
              ┌──────────┼──────────┐
              │          │          │
         ┌────▼───┐ ┌────▼───┐ ┌────▼───┐
         │ ESP32  │ │ ESP32  │ │ ESP32  │
         │Device 1│ │Device 2│ │Device N│
         └────────┘ └────────┘ └────────┘
              │          │          │
              └──────────┼──────────┘
                         │
              ┌──────────▼──────────┐
              │   Central Web       │
              │   Server            │
              │   (LAN IP or        │
              │    Public IP)       │
              └─────────────────────┘
```

### 5.2 Network Requirements

- **WiFi Standard:** 802.11 b/g/n (2.4 GHz)
- **Security:** WPA2 or WPA3
- **Range:** Devices within 50m of access point (recommended)
- **Bandwidth:** Minimum 1 Mbps per device (10 devices = 10 Mbps total)
- **Network Type:** Local Area Network (LAN) or VPN for remote access

### 5.3 Communication Protocols

1. **Device to Server:**
   - **Protocol:** HTTP (REST API, unencrypted)
   - **Port:** 80 (HTTP)
   - **Method:** POST for data transmission
   - **Format:** JSON payload

2. **Server to Browser:**
   - **Protocol:** HTTP for web pages (unencrypted)
   - **Protocol:** WebSocket or SSE for real-time updates (unencrypted)
   - **Port:** 80 (HTTP)

3. **Configuration Sync:**
   - **Protocol:** HTTP (REST API, unencrypted)
   - **Method:** GET (device polls server)
   - **Interval:** Configurable (default: every 5 minutes)

---

## 6. Application Architecture

### 6.1 Backend Application Structure

```
backend/
├── src/
│   ├── api/
│   │   ├── routes/
│   │   │   ├── devices.js          # Device management routes
│   │   │   ├── data.js              # Data collection routes
│   │   │   ├── config.js            # Configuration routes
│   │   │   └── monitoring.js        # Monitoring routes
│   │   ├── controllers/
│   │   │   ├── deviceController.js
│   │   │   ├── dataController.js
│   │   │   └── configController.js
│   │   └── middleware/
│   │       ├── auth.js              # Authentication middleware
│   │       ├── validation.js        # Input validation
│   │       └── errorHandler.js      # Error handling
│   ├── services/
│   │   ├── deviceService.js         # Device business logic
│   │   ├── dataService.js           # Data processing logic
│   │   ├── configService.js         # Configuration management
│   │   ├── calibrationService.js     # Calibration logic and offset application
│   │   └── retentionService.js       # Data retention logic
│   ├── models/
│   │   ├── Device.js                # Device model
│   │   ├── Measurement.js           # Measurement model
│   │   └── FrequencyBand.js         # Frequency band model
│   ├── storage/
│   │   ├── configManager.js         # JSON config file handler
│   │   ├── measurementWriter.js     # CSV/JSON measurement writer
│   │   ├── measurementReader.js      # CSV/JSON measurement reader
│   │   ├── fileLock.js              # File locking for concurrent access
│   │   └── retentionManager.js       # Data retention and cleanup
│   ├── utils/
│   │   ├── logger.js                # Logging utility
│   │   └── validators.js            # Validation helpers
│   └── server.js                    # Application entry point
├── config/
│   ├── storage.js                   # Storage configuration
│   └── app.js                       # Application configuration
└── package.json
```

### 6.2 Frontend Application Structure

**Implementation Status:** ✅ Production Ready (February 2026)

The current frontend implementation uses vanilla JavaScript with Chart.js for visualization, deployed via Python's http.server for development.

**Production Structure:**
```
frontend/
├── index.html                       # Main application page
├── test.html                        # Testing page
├── css/
│   ├── styles.css                   # Main styles with color-coded thresholds
│   └── features.css                 # Feature-specific styles
└── js/
    ├── app.js                       # Main application logic, device management
    ├── api.js                       # Backend API client
    └── charts.js                    # Chart.js visualization wrapper
```

**Key Features Implemented (v1.2):**

1. **Color-Coded Sound Level Display**
   - Under 80 dB: Green (#d1fae5 background, #065f46 text)
   - 80-95 dB: Yellow (#fef3c7 background, #92400e text)
   - Over 95 dB: Red (#fecaca background, #991b1b text)
   - Applied to: Dashboard cards, history items, measurement badges

2. **Multi-Line History Chart**
   - Chart.js v4.4.0 with multi-dataset support
   - Overall sound level (primary line)
   - Individual frequency band levels (3 additional lines)
   - Color scheme: Green, Orange, Pink, Purple, Yellow
   - Automatic dataset creation based on frequency_bands array
   - Time-series visualization with ISO timestamp parsing

3. **Full-Width History Display**
   - Flexbox layout for measurement items
   - Full screen width utilization (changed from grid layout)
   - Improved readability for frequency band data
   - Responsive design for mobile/desktop

4. **Active Status Monitoring**
   - 60-second activity threshold
   - Real-time status indicators (green=active, gray=inactive)
   - last_seen timestamp display
   - Auto-refresh every 10 seconds

5. **Analytics Dashboard**
   - Date range selection for queries
   - Statistical calculations (min, max, average, median)
   - Per-frequency band statistics
   - API endpoint: GET /api/analytics/stats

**Future Migration Path (Optional):**
```
frontend/ (React/Vue migration - not yet implemented)
├── src/
│   ├── components/
│   │   ├── monitoring/
│   │   │   ├── Dashboard.jsx
│   │   │   ├── DeviceStatus.jsx
│   │   │   ├── RealTimeChart.jsx
│   │   │   └── HistoricalChart.jsx
│   │   ├── admin/
│   │   │   ├── DeviceList.jsx
│   │   │   ├── DeviceRegistration.jsx
│   │   │   ├── FrequencyBandEditor.jsx
│   │   │   ├── SensorCalibration.jsx
│   │   │   └── RetentionConfig.jsx
│   │   └── common/
│   │       ├── Header.jsx
│   │       ├── Navigation.jsx
│   │       └── LoadingSpinner.jsx
│   ├── pages/
│   │   ├── MonitoringPage.jsx
│   │   └── AdminPage.jsx
│   ├── services/
│   │   ├── api.js                   # API client
│   │   └── websocket.js             # WebSocket client
│   ├── hooks/
│   │   ├── useRealtimeData.js
│   │   └── useDevices.js
│   ├── utils/
│   │   ├── formatters.js
│   │   └── validators.js
│   └── App.jsx
├── public/
│   └── index.html
└── package.json
```

### 6.3 ESP32 Firmware Structure

```
firmware/
├── main/
│   ├── main.c                       # Main application entry (ESP-IDF)
│   ├── main.h
│   └── CMakeLists.txt
├── components/                      # ESP-IDF components (optional)
│   ├── audio/
│   │   ├── i2s_driver.c            # I2S interface driver for INMP441
│   │   ├── audio_sampler.c         # Audio sampling via I2S
│   │   ├── anti_alias_filter.c     # Anti-aliasing low-pass filter
│   │   ├── window_function.c       # Windowing functions (Hamming, Hanning, etc.)
│   │   ├── audio_processor.c       # FFT and dB calculation
│   │   ├── frequency_bands.c       # Frequency band processing
│   │   └── calibration.c          # Calibration offset application
│   ├── communication/
│   │   ├── wifi_manager.c          # WiFi connection management
│   │   ├── http_client.c           # HTTP client
│   │   └── api_client.c            # API communication
│   ├── config/
│   │   ├── config_manager.c        # Configuration management (NVS)
│   │   ├── calibration_config.c    # Calibration configuration storage
│   │   └── ntp_sync.c              # NTP time synchronization
│   └── system/
│       ├── watchdog.c              # Watchdog timer
│       └── logger.c                # Logging
├── CMakeLists.txt                  # Main build configuration
├── sdkconfig                        # ESP-IDF configuration
└── partitions.csv                   # Flash partition table
```

---

## 7. Security Architecture

### 7.1 Authentication & Authorization

**Current Implementation Status (February 2026):**
- **⏳ Not Yet Implemented:** User authentication deferred for MVP
- System currently operates in development mode without authentication
- Future implementation would include:
  - Username/password authentication
  - Session management (JWT tokens or session cookies)
  - Role-based access (admin vs viewer)

**Device Authentication:**
- Device registration with unique device ID
- Device IDs support alphanumeric names with spaces (URL encoded)
- MAC address tracking for device identification
- Configuration access controlled by device_id parameter

### 7.2 Data Security

1. **Transport Security**
   - HTTP for all communication (unencrypted, no certificates)
   - Local network deployment (WiFi WPA2/WPA3)
   - Development environment: localhost communication
   - Production recommendation: HTTPS with Let's Encrypt certificates

2. **Data Storage Security**
   - File-based storage with filesystem permissions
   - Device configurations stored per device in JSON format
   - Measurement data organized by device and date
   - No sensitive credential storage in current implementation

3. **API Security**
   - Input validation via Express middleware
   - URL parameter sanitization (device IDs, dates)
   - CORS enabled for development (localhost:8080 to localhost:3000)
   - Rate limiting: Not yet implemented (recommended for production)

### 7.3 Network Security

**Current Deployment:**
- Local network deployment (192.168.68.x subnet)
- WiFi security: WPA2/WPA3 network encryption
- Backend server: 192.168.68.57:3000
- Frontend server: localhost:8080

**Production Recommendations:**
- Firewall rules on web server (block non-HTTP/HTTPS ports)
- Network segmentation (IoT devices on separate VLAN)
- VPN access for remote administration (if internet-accessible)

---

## 7A. Current Deployment Status (February 2026)

### 7A.1 Active Hardware Deployment

**Operational Sensor:**
- **Device ID:** "Sensor 01"
- **MAC Address:** 08:92:72:84:1d:18
- **Status:** ✅ Active and transmitting
- **Connection:** USB-C wall charger power
- **Location:** Development environment
- **Last Seen:** Within 5 seconds (continuous operation)
- **Measurement Frequency:** Every 5 seconds
- **Current Readings:** 76-77 dB ambient levels

**Hardware Configuration:**
- ESP32-C3 Super Mini microcontroller
- INMP441 I2S digital microphone
- Pin connections verified: GPIO 4 (data), GPIO 5 (BCLK), GPIO 6 (WS)
- I2S configuration: 16kHz sample rate, 32-bit containers
- WiFi: Connected to local network (192.168.68.x)

### 7A.2 Software Deployment

**Backend Server:**
- Platform: Node.js with Express
- Host: 192.168.68.57:3000
- Status: ✅ Running and accepting measurements
- API Endpoints: All operational
- Storage: File-based JSON (backend/data/)
- Log: backend/src/utils/logger.js

**Frontend Application:**
- Platform: Vanilla JavaScript + Chart.js
- Host: localhost:8080 (Python http.server)
- Status: ✅ Operational
- Features: Dashboard, history chart, analytics, config management
- Browser: Chrome/Safari compatible

**Firmware:**
- Framework: ESP-IDF v6.1-dev-2300
- Language: C
- Features:
  - I2S audio sampling (16kHz)
  - FFT frequency analysis (3 bands: 20-200Hz, 200-2000Hz, 2000-8000Hz)
  - Dynamic configuration fetch (startup + periodic refresh)
  - HTTP POST measurements every 5 seconds
  - URL encoding for device IDs with spaces
  - Calibration offset application (1.0 dB)

### 7A.3 Data Flow Verification

**Measurement Transmission:**
```
ESP32 Device → WiFi Network → Backend API (POST /api/data/measurements)
              ↓
         JSON storage (backend/data/measurements/Sensor 01_YYYY-MM-DD.json)
              ↓
         Frontend retrieval (GET /api/data/measurements/:deviceId)
              ↓
         Dashboard display + Chart visualization
```

**Configuration Sync:**
```
Backend storage (backend/data/devices/Sensor 01.json)
              ↓
ESP32 fetch (GET /api/config/devices/Sensor%2001/frequency-bands)
              ↓
Apply settings (calibration offset, frequency bands)
              ↓
Periodic refresh (every 100 measurements, ~5 minutes)
```

**Performance Metrics:**
- Measurement latency: < 1 second (device to server)
- API response time: < 200ms (typical)
- Configuration update: < 60 seconds (includes periodic refresh)
- Data retention: Currently unlimited (no auto-purge implemented)
- Active status threshold: 60 seconds

---

## 8. Deployment Architecture

### 8.1 Deployment Environments

This system supports multiple deployment configurations depending on the development phase and scale of deployment.

#### 8.1.1 Development Environment #1 (Current - January 2026)

**Local Development and Testing**

See Section 9.6.1 for detailed configuration.

**Platform:**
- **Server:** MacBook running local development servers
- **Network:** Home WiFi network
- **ESP32:** Single device connected via USB and WiFi
- **Purpose:** Initial development, firmware testing, system prototyping

**Quick Summary:**
- All components (backend, frontend, ESP32) run on or connect to MacBook
- ESP32-C3 connected via USB for flashing, WiFi for runtime communication
- INMP441 microphone wired per design specifications (GPIO 4, 5, 6)
- Ideal for rapid development and testing

#### 8.1.2 Production Environment (Future)

**Remote Server Deployment**

**Target Platform:**
- **Operating System:** Ubuntu 20.04 LTS
- **Web Server:** Nginx (already installed and running)
- **Deployment Type:** On-premise or cloud server
- **Network:** Local network or public IP with WiFi access
- **ESP32 Devices:** Up to 10 units deployed at various locations

**Server Environment:**
- Ubuntu 20.04.4 LTS server
- Nginx web server (reverse proxy and static file serving)
- Application server (Node.js, Python, or Go backend)
- File system storage for data and configuration files

### 8.2 Deployment Components

```
┌─────────────────────────────────────┐
│      Deployment Environment         │
├─────────────────────────────────────┤
│                                     │
│  ┌──────────────────────────────┐   │
│  │   Nginx Web Server           │   │
│  │   - Reverse Proxy           │   │
│  │   - HTTP Server (port 80)   │   │
│  │   - Static File Serving      │   │
│  │   - API Proxy to Backend     │   │
│  └──────────────┬───────────────┘   │
│                 │                    │
│  ┌──────────────▼───────────────┐   │
│  │   Application Server         │   │
│  │   - Backend API              │   │
│  │   - Frontend App             │   │
│  └──────────────┬───────────────┘   │
│                 │                    │
│  ┌──────────────▼───────────────┐   │
│  │   File System Storage        │   │
│  │   - JSON config files         │   │
│  │   - CSV/JSON measurement files│   │
│  │   - Local file system        │   │
│  └──────────────────────────────┘   │
│                                     │
│  ┌──────────────────────────────┐   │
│  │   Background Jobs            │   │
│  │   - Data Retention Cleanup   │   │
│  │   - Health Monitoring        │   │
│  └──────────────────────────────┘   │
└─────────────────────────────────────┘
```

### 8.3 Infrastructure Requirements

**Server Platform:**
- **Operating System:** Ubuntu 20.04 LTS
- **Web Server:** Nginx (pre-installed)
- **Package Manager:** apt

**Server Specifications (Minimum):**
- CPU: 2 cores
- RAM: 4 GB
- Storage: 50 GB (for 7 days of data from 10 devices)
- Network: 100 Mbps connection

**Server Specifications (Recommended):**
- CPU: 4 cores
- RAM: 8 GB
- Storage: 100 GB SSD
- Network: 1 Gbps connection

### 8.4 Nginx Configuration

**Nginx Setup:**
- Nginx installed and running on Ubuntu 20.04
- Configuration file: `/etc/nginx/sites-available/sound-monitoring`
- Symlink to: `/etc/nginx/sites-enabled/sound-monitoring`
- Default port: 80 (HTTP, unencrypted)

**Nginx Configuration Example:**

```nginx
server {
    listen 80;
    server_name localhost;  # or your domain/IP

    # Root directory for static files (frontend)
    root /var/www/sound-monitoring/frontend/dist;
    index index.html;

    # API proxy to backend application
    location /api/ {
        proxy_pass http://localhost:3000;  # Backend API port
        proxy_http_version 1.1;
        proxy_set_header Upgrade $http_upgrade;
        proxy_set_header Connection 'upgrade';
        proxy_set_header Host $host;
        proxy_set_header X-Real-IP $remote_addr;
        proxy_set_header X-Forwarded-For $proxy_add_x_forwarded_for;
        proxy_set_header X-Forwarded-Proto $scheme;
        proxy_cache_bypass $http_upgrade;
    }

    # WebSocket support (if using WebSocket for real-time updates)
    location /ws/ {
        proxy_pass http://localhost:3000;
        proxy_http_version 1.1;
        proxy_set_header Upgrade $http_upgrade;
        proxy_set_header Connection "upgrade";
        proxy_set_header Host $host;
        proxy_set_header X-Real-IP $remote_addr;
        proxy_set_header X-Forwarded-For $proxy_add_x_forwarded_for;
    }

    # Static files (frontend)
    location / {
        try_files $uri $uri/ /index.html;
    }

    # File storage directory (optional, for direct file access)
    location /data/ {
        alias /var/www/sound-monitoring/data/;
        autoindex off;
    }
}
```

**Nginx Service Management:**
- Start: `sudo systemctl start nginx`
- Stop: `sudo systemctl stop nginx`
- Restart: `sudo systemctl restart nginx`
- Reload config: `sudo nginx -s reload`
- Status: `sudo systemctl status nginx`
- Enable on boot: `sudo systemctl enable nginx`

### 8.5 Ubuntu 20.04 Deployment Steps

**Note:** These steps are performed via SSH from your MacBook development machine.

**Prerequisites:**
- SSH access to Ubuntu 20.04 server
- Sudo privileges on server
- Files transferred from MacBook to server (via SCP, Git, or rsync)

**Remote Access:**
```bash
# From MacBook, connect to server
ssh user@your-server-ip

# Or use Cursor's remote SSH extension for seamless editing
```

**1. System Preparation:**
```bash
# Update system packages
sudo apt update
sudo apt upgrade -y

# Install required packages
sudo apt install -y nginx nodejs npm  # or python3, python3-pip for Python
sudo apt install -y git curl
```

**2. Application Deployment:**
```bash
# Create application directory
sudo mkdir -p /var/www/sound-monitoring
sudo chown $USER:$USER /var/www/sound-monitoring

# Transfer files from MacBook to server (from MacBook terminal)
# Option A: Using SCP
scp -r backend/ user@server-ip:/var/www/sound-monitoring/
scp -r frontend/ user@server-ip:/var/www/sound-monitoring/

# Option B: Using Git (recommended)
# On MacBook: git push origin main
# On server:
cd /var/www/sound-monitoring
git clone <repository-url> .
# Or: git pull (if already cloned)

# Install dependencies and build (on server via SSH)
cd /var/www/sound-monitoring
cd backend && npm install
cd ../frontend && npm install && npm run build

# Create data directory
mkdir -p /var/www/sound-monitoring/data/{config,measurements,logs}
```

**3. Nginx Configuration:**
```bash
# Create nginx configuration
sudo nano /etc/nginx/sites-available/sound-monitoring
# (paste configuration from above)

# Enable site
sudo ln -s /etc/nginx/sites-available/sound-monitoring /etc/nginx/sites-enabled/

# Test nginx configuration
sudo nginx -t

# Reload nginx
sudo systemctl reload nginx
```

**4. Application Service (systemd):**
```bash
# Create systemd service file
sudo nano /etc/systemd/system/sound-monitoring.service
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

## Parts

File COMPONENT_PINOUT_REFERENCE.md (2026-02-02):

# Component Pinout Reference
## ESP32-C3 SuperMini & INMP441 I2S Microphone

**Document Version:** 1.0  
**Date:** January 28, 2026  
**Status:** Hardware Verified  
**Related Documents:** [Hardware Design Document](sound%20level%20mesh%20hardware%20design.md)

---

## Overview

This document provides the complete pinout specifications for the components used in the Sound Level Mesh System monitoring devices:

- **ESP32-C3 SuperMini Development Board** (Microcontroller)
- **MH-ET LIVE INMP441 Digital Microphone Module** (I2S Audio Input)

This reference includes physical pin layouts, recommended I2S wiring configuration, and software setup examples.

---

## 1. ESP32-C3 SuperMini Pinout

The ESP32-C3 SuperMini is a compact development board based on the **RISC-V architecture** (single-core, 160 MHz). It features built-in USB-CDC (USB-to-Serial) eliminating the need for external USB-to-UART chips.

### Physical Orientation

**Hold the board with:**
- USB-C connector facing **UP** (top)
- Chip and buttons facing **YOU** (front)

**Header Layout:**
- **Right Header:** Starts with `5V` at top right (Pin 1)
- **Left Header:** Starts with `GPIO 5` at top left (Pin 1)

### Complete Pinout Table

| Pin Label | GPIO | Physical Position | Function / Notes |
|---|---|---|---|
| **5V** | - | Right Side, Pin 1 (Top)  | 5V Power Input (from USB or external) |
| **GND** | - | Right Side, Pin 2 | Ground |
| **3V3** | - | Right Side, Pin 3 | 3.3V Output (Regulated) or Input |
| **0** | GPIO 0  | Right Side, Pin 4 | ADC1_CH0, Digital I/O |
| **1** | GPIO 1  | Right Side, Pin 5 | ADC1_CH1, Digital I/O |
| **2** | GPIO 2  | Right Side, Pin 6 | ⚠️ Strapping Pin (Keep floating at boot) |
| **3** | GPIO 3  | Right Side, Pin 7 | ADC1_CH3, Digital I/O |
| **4** | GPIO 4  | Right Side, Pin 8 (Bottom)| ADC1_CH4, **I2S SCK** (Recommended) |
| **5** | GPIO 5  | Left Side, Pin 1 (Top) | ADC1_CH5, **I2S WS** (Recommended), MISO (SPI)|
| **6** | GPIO 6  | Left Side, Pin 2 | **I2S SD** (Recommended), MOSI (SPI) |
| **7** | GPIO 7  | Left Side, Pin 3 | SS (SPI), Digital I/O |
| **8** | GPIO 8  | Left Side, Pin 4 | I2C SDA, LED, ⚠️ Strapping Pin |
| **9** | GPIO 9  | Left Side, Pin 5 | I2C SCL, Boot Button, ⚠️ Strapping Pin |
| **10** | GPIO 10 | Left Side, Pin 6 | Digital I/O |
| **20** | GPIO 20 | Left Side, Pin 7 | UART RX (USB Serial) |
| **21** | GPIO 21 | Left Side, Pin 8 (Bottom)| UART TX (USB Serial) |

### Pin Categories

#### Power Pins
- **5V:** Input voltage from USB or external power (not regulated)
- **3V3:** Regulated 3.3V output (can supply ~500mA) or 3.3V input if powered externally
- **GND:** Ground reference

#### I2S Recommended Pins (For INMP441 Connection)
- **GPIO 4:** I2S Serial Clock (SCK/BCLK) - Right Side, Pin 8
- **GPIO 5:** I2S Word Select (WS/LRCK) - Left Side, Pin 1
- **GPIO 6:** I2S Serial Data (SD/DIN) - Left Side, Pin 2

#### Strapping Pins ⚠️ **IMPORTANT**

These pins affect boot behavior if held HIGH or LOW during power-on:

| GPIO | Boot Behavior |
|---|---|
| GPIO 2 | Keep **floating** at boot (do not pull HIGH or LOW) |
| GPIO 8 | Boot mode selection - avoid external connections |
| GPIO 9 | Download mode - connected to boot button |

**Recommendation:** Avoid using GPIO 2, 8, and 9 for I2S or other critical functions to prevent boot issues.

#### Serial/Debug Pins
- **GPIO 20:** UART RX (USB CDC)
- **GPIO 21:** UART TX (USB CDC)

**Note:** These are used by the USB-CDC serial interface. Avoid using them for I2S.

### Visual Pinout Diagram

```
        USB-C Connector (TOP)
        ┌─────────────┐
        │   ╔═══════╗ │
        │   ║ USB-C ║ │
        │   ╚═══════╝ │
        │             │
        │  ┌───────┐  │
        │  │ ESP32 │  │
        │  │  C3   │  │
        │  └───────┘  │
        │             │
Right   │             │   Left
Header  │             │   Header
────────┴─────────────┴────────
        
 5V  ●               ● GPIO 5  (I2S WS) ← Recommended
GND  ●               ● GPIO 6  (I2S SD) ← Recommended
3V3  ●               ● GPIO 7
  0  ●               ● GPIO 8  (⚠️ Strapping)
  1  ●               ● GPIO 9  (⚠️ Strapping)
  2  ●               ● GPIO 10 (Boot Button)
  3  ●               ● GPIO 20 (USB RX)
  4  ●               ● GPIO 21 (USB TX)
   (I2S SCK) ←
   Recommended
```

---

## 2. MH-ET LIVE INMP441 Pinout

The INMP441 is a high-precision **MEMS omnidirectional microphone** with digital I2S output. It features:
- Sample rate: Up to 48 kHz
- Bit depth: 24-bit
- SNR: 65 dB
- Sensitivity: -26 dBFS
- Operating voltage: **3.3V only** (do not use 5V!)

### Physical Orientation

**Hold the module with:**
- **Gold Circle** (microphone) facing **YOU** (front)
- **Pins at the BOTTOM**
- Count pins from **LEFT to RIGHT**

### Complete Pinout Table

| Pin # | Name  | Physical Position | Function | Connect To |
|---|---|---|---|---|
| 1 | **SCK** | Far Left (Pin 1) | Serial Clock (BCLK - Bit Clock) | ESP32-C3 GPIO 4 |
| 2 | **WS**  | Pin 2 | Word Select (LRCK - Left/Right Clock) | ESP32-C3 GPIO 5 |
| 3 | **L/R** | Pin 3 | Channel Select (Low=Left, High=Right) | ESP32-C3 GND |
| 4 | **SD**  | Pin 4 | Serial Data (DOUT - Audio Data) | ESP32-C3 GPIO 6 |
| 5 | **VDD** | Pin 5 | Power Supply (**3.3V ONLY**) | ESP32-C3 3V3 |
| 6 | **GND** | Far Right (Pin 6)  | Ground | ESP32-C3 GND |

### Pin Function Details

#### I2S Interface Pins
- **SCK (Serial Clock / BCLK):** Bit clock input - synchronizes data transmission
- **WS (Word Select / LRCK):** Determines left vs right channel in stereo mode
- **SD (Serial Data / DOUT):** Digital audio data output (24-bit I2S format)

#### Power Pins
- **VDD:** **3.3V power supply** - Do NOT connect to 5V! Will damage the microphone.
- **GND:** Ground reference

#### Channel Selection
- **L/R:** Connect to GND for **LEFT channel** (standard for mono)
  - Connect to GND = Left Channel
  - Connect to VDD = Right Channel
  - For mono recording, always connect to GND

### Visual Pinout Diagram

```
     ┌─────────────────┐
     │                 │
     │      ┌───┐      │
     │      │ ⦿ │      │  ← Gold circle = Microphone
     │      └───┘      │
     │                 │
     │   INMP441       │
     │                 │
     └─────────────────┘
     │ │ │ │ │ │
     1 2 3 4 5 6
     │ │ │ │ │ │
    SCK WS L/R SD VDD GND
     │  │  │  │  │  │
     ↓  ↓  ↓  ↓  ↓  ↓
  GPIO4 GPIO5 GND GPIO6 3V3 GND
     │  │     │  │  │  │
     └──┴─────┴──┴──┴──┴── ESP32-C3
```

---

## 3. Wiring Guide

### Recommended Connection Table

This wiring configuration uses GPIO 4, 5, and 6 to avoid conflicts with:
- Strapping pins (GPIO 2, 8, 9)
- USB serial pins (GPIO 20, 21)
- Boot button (GPIO 9)

| INMP441 Pin | INMP441 Function | ESP32-C3 Pin | ESP32-C3 Location | Wire Color (Suggested) |
|---|---|---|---|---|
| **VDD** | Power (3.3V) | **3V3** | Right Side, Pin 3 | Red |
| **GND** | Ground | **GND** | Right Side, Pin 2 | Black |
| **L/R** | Channel Select | **GND** | Right Side, Pin 2 | Black (tie to GND) |
| **SCK** | I2S Bit Clock | **GPIO 4** | Right Side, Pin 8 | Yellow |
| **WS** | I2S Word Select  | **GPIO 5** | Left Side, Pin 1  | Green |
| **SD** | I2S Serial Data  | **GPIO 6** | Left Side, Pin 2  | Blue |

### Wiring Notes

1. **Power Supply:**
   - Use **3V3 pin only** (ESP32-C3 regulated 3.3V output)
   - **Never connect VDD to 5V** - this will damage the INMP441
   - Current draw: ~1.2 mA (very low)

2. **Ground Connections:**
   - Connect both INMP441 GND and L/R to ESP32-C3 GND
   - Use same ground reference for all connections

3. **L/R Channel Selection:**
   - Connect L/R to GND for **mono left channel** recording
   - This is the standard configuration for single microphone systems
   - Do not leave L/R floating

4. **I2S Signal Routing:**
   - Keep wire lengths **short** (< 10 cm recommended)
   - Use twisted pair or shielded cable for longer runs
   - Avoid routing near power cables or high-frequency signals

5. **Signal Quality:**
   - GPIO 4, 5, 6 provide clean I2S signals
   - No conflicts with boot, USB, or strapping functions
   - Reliable operation without boot issues

### Physical Assembly Diagram

```
ESP32-C3 SuperMini              INMP441 Microphone
(USB-C UP)                      (Mic facing you)

Right Side:                     Pins (Left to Right):
  5V  ●                         1. SCK ──┐
  GND ●───────────────────┬─────2. WS  ──┤
  3V3 ●───────┐           │     3. L/R ──┤
   0  ●       │           │     4. SD  ──┤
   1  ●       │           │     5. VDD ──┤
   2  ●       │           │     6. GND ──┘
   3  ●       │           │
   4  ●───────┼───────────┼─────────────────(SCK)
              │           │
Left Side:    │           │
   5  ●───────┼───────────┼─────────────────(WS)
   6  ●───────┼───────────┼─────────────────(SD)
   7  ●       │           │
   8  ●       │           │
   9  ●       │           │
  10  ●       │           │
  20  ●       │           │
  21  ●       └───(VDD)   └───(GND + L/R)
```

---

## 4. Software Configuration

### Arduino IDE / ESP-IDF Configuration

When programming the ESP32-C3, configure the I2S pins to match the wiring above.

#### Pin Definitions

```cpp
#include <driver/i2s.h>

// I2S Pin Configurations
#define I2S_WS   5    // Word Select (LRCK) - Left Side Pin 1
#define I2S_SD   6    // Serial Data (DIN)  - Left Side Pin 2  
#define I2S_SCK  4    // Bit Clock (BCLK)   - Right Side Pin 8

// I2S Port Selection
#define I2S_PORT I2S_NUM_0
```

#### I2S Configuration Structure

```cpp
void setup() {
  Serial.begin(115200);
  
  // I2S Configuration
  i2s_config_t i2s_config = {
    .mode = (i2s_mode_t)(I2S_MODE_MASTER | I2S_MODE_RX),  // Master, receive mode
    .sample_rate = 44100,                                  // 44.1 kHz (or 16000, 48000)
    .bits_per_sample = I2S_BITS_PER_SAMPLE_32BIT,         // 32-bit for 24-bit data
    .channel_format = I2S_CHANNEL_FMT_ONLY_LEFT,          // Mono (L/R tied to GND)
    .communication_format = I2S_COMM_FORMAT_STAND_I2S,    // Standard I2S format
    .intr_alloc_flags = ESP_INTR_FLAG_LEVEL1,             // Interrupt priority
    .dma_buf_count = 8,                                    // Number of DMA buffers
    .dma_buf_len = 64,                                     // DMA buffer length
    .use_apll = false,                                     // Don't use APLL
    .tx_desc_auto_clear = false,                           // Don't auto-clear TX
    .fixed_mclk = 0                                        // Auto MCLK
  };
  
  // I2S Pin Configuration
  i2s_pin_config_t pin_config = {
    .bck_io_num = I2S_SCK,           // Bit clock pin
    .ws_io_num = I2S_WS,             // Word select pin
    .data_out_num = I2S_PIN_NO_CHANGE,  // Not used for microphone
    .data_in_num = I2S_SD            // Serial data input pin
  };
  
  // Install and configure I2S driver
  i2s_driver_install(I2S_PORT, &i2s_config, 0, NULL);
  i2s_set_pin(I2S_PORT, &pin_config);
  
  Serial.println("I2S initialized successfully");
}

void loop() {
  // Read audio data from I2S
  size_t bytes_read = 0;
  int32_t samples[64];  // Buffer for audio samples
  
  i2s_read(I2S_PORT, &samples, sizeof(samples), &bytes_read, portMAX_DELAY);
  
  // Process audio data here...
  // Note: INMP441 outputs 24-bit data in 32-bit format
  // Upper 24 bits contain audio, lower 8 bits are zero
}
```

#### Key Configuration Parameters

| Parameter | Value | Notes |
|---|---|---|
| Sample Rate | 44100 Hz | Can use 16000, 22050, 44100, or 48000 Hz |
| Bits per Sample | 32-bit | INMP441 outputs 24-bit in 32-bit container |
| Channel Format | ONLY_LEFT | Because L/R is tied to GND (mono) |
| Communication Format | STAND_I2S | Standard I2S protocol |
| DMA Buffers | 8 × 64 | Adjustable based on latency needs |

#### Sample Rate Options

```cpp
// Low latency, lower quality (good for sound level monitoring)
.sample_rate = 16000   // 16 kHz

// Standard quality
.sample_rate = 44100   // 44.1 kHz (CD quality)

// High quality (maximum for INMP441)
.sample_rate = 48000   // 48 kHz
```

### Data Format

The INMP441 outputs **24-bit audio data** in a **32-bit container**:

```
32-bit Word Structure:
┌───────────────────────────────┬───────────┐
│  Audio Data (24 bits)         │ Zero (8)  │
│  [MSB..................LSB]   │ [0000000] │
└───────────────────────────────┴───────────┘
 Bit 31                    Bit 8  Bit 7...0

To extract 24-bit audio from 32-bit sample:
  audio_value = (sample >> 8) & 0xFFFFFF;
```

---

## 5. Testing and Verification

### Initial Testing Procedure

1. **Power Check:**
   ```cpp
   // Verify 3.3V at INMP441 VDD pin
   // Expected: 3.25V - 3.35V
   ```

2. **I2S Signal Check (with oscilloscope):**
   - SCK: Should see square wave at bit clock frequency
   - WS: Should see square wave at sample rate
   - SD: Should see data transitions

3. **Audio Data Verification:**
   ```cpp
   void test_audio_read() {
     int32_t sample;
     size_t bytes_read;
     
     i2s_read(I2S_PORT, &sample, sizeof(sample), &bytes_read, 1000);
     
     if (bytes_read > 0) {
       Serial.print("Sample: ");
       Serial.println(sample, HEX);
     } else {
       Serial.println("ERROR: No data received");
     }
   }
   ```

4. **Expected Results:**
   - Silent room: Samples around 0x00800000 (mid-scale)
   - With sound: Samples varying around mid-scale
   - No data: Check wiring and power

### Common Issues

| Problem | Possible Cause | Solution |
|---|---|---|
| No data received | Wiring incorrect | Verify all connections |
| All zeros | VDD not connected | Check 3.3V power supply |
| All 0xFF | L/R floating | Connect L/R to GND |
| Noisy data | Poor grounding | Use common ground reference |
| Boot issues | Strapping pin conflict | Use GPIO 4, 5, 6 as specified |

---

## 6. Alternative Pin Configurations

While GPIO 4, 5, 6 are recommended, the ESP32-C3 allows flexible I2S pin mapping.

### Alternative GPIO Options

**If GPIO 4, 5, 6 are unavailable:**

| Function | Primary | Alternative 1 | Alternative 2 | Avoid |
|---|---|---|---|---|
| I2S SCK  | GPIO 4  | GPIO 3 | GPIO 7 | 2, 8, 9, 20, 21 |
| I2S WS | GPIO 5  | GPIO 10 | GPIO 7 | 2, 8, 9, 20, 21 |
| I2S SD | GPIO 6  | GPIO 0 | GPIO 1 | 2, 8, 9, 20, 21 |

**Pins to Avoid:**
- **GPIO 2, 8, 9:** Strapping pins (boot mode)
- **GPIO 20, 21:** USB serial (debugging)

---

## 7. Specifications Summary

### ESP32-C3 SuperMini Specifications

| Parameter | Value |
|---|---|
| Architecture | RISC-V (Single-core) |
| Clock Speed | 160 MHz |
| Flash | 4 MB |
| SRAM | 400 KB |
| WiFi | 802.11 b/g/n (2.4 GHz) |
| Bluetooth | BLE 5.0 |
| Operating Voltage | 3.3V |
| Input Voltage | 5V (USB) or 3.3V |
| GPIO Pins | 22 (15 available) |
| USB Interface | USB-CDC (built-in) |

### INMP441 Specifications

| Parameter | Value |
|---|---|
| Type | MEMS Omnidirectional |
| Interface | I2S Digital |
| Operating Voltage | 3.3V (±10%) |
| Current Consumption | 1.2 mA typical |
| Sample Rate | Up to 48 kHz |
| Bit Depth | 24-bit |
| SNR | 65 dB |
| Sensitivity | -26 dBFS |
| Frequency Response | 60 Hz - 15 kHz |
| Operating Temp | -40°C to +85°C |

---

## 8. References

### Official Documentation
- [ESP32-C3 Technical Reference Manual](https://www.espressif.com/sites/default/files/documentation/esp32-c3_technical_reference_manual_en.pdf)
- [ESP32-C3 Datasheet](https://www.espressif.com/sites/default/files/documentation/esp32-c3_datasheet_en.pdf)
- [INMP441 Datasheet](https://invensense.tdk.com/wp-content/uploads/2015/02/INMP441.pdf)
- [I2S Bus Specification](https://www.sparkfun.com/datasheets/BreakoutBoards/I2SBUS.pdf)

### ESP-IDF Documentation
- [I2S Driver API Reference](https://docs.espressif.com/projects/esp-idf/en/latest/esp32c3/api-reference/peripherals/i2s.html)
- [GPIO & RTC GPIO](https://docs.espressif.com/projects/esp-idf/en/latest/esp32c3/api-reference/peripherals/gpio.html)

### Related Project Documents
- [Sound Level Mesh Hardware Design](sound%20level%20mesh%20hardware%20design.md)
- [Sound Level Mesh Architecture](sound%20level%20mesh%20architecture.md)

---

## Revision History

| Version | Date | Changes |
|---|---|---|
| 1.0 | 2026-01-28 | Initial release with verified pinouts |

---

**Document Status:** ✅ Verified and Ready for Implementation  
**Hardware Status:** ⏳ Awaiting component delivery for physical verification

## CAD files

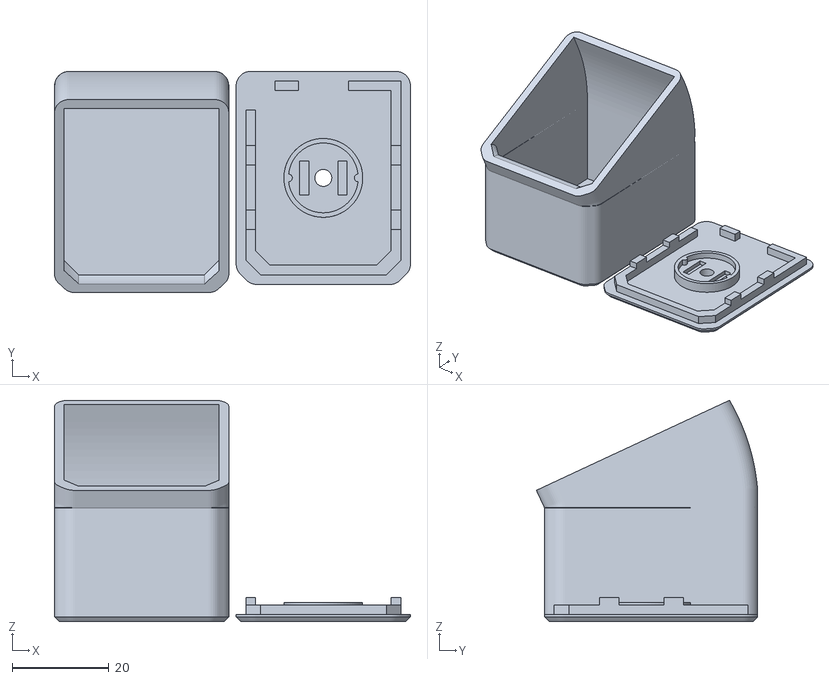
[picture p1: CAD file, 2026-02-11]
enclosure/Sound Sensor enclosure.stl
73.5 x 45.7 x 45.7

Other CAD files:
enclosure/Sound Sensor enclosure.f3d

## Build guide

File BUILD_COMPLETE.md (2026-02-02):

# Sound Level Mesh System - Build Complete! 🎉

All system code has been successfully built and is ready for deployment.

## What Was Built

### ✅ 1. ESP32-C3 Firmware (`firmware/sound-level-sensor/`)

**Full-featured firmware** for ESP32-C3 microcontroller with INMP441 I2S microphone:
- I2S audio sampling (16 kHz, 24-bit)
- FFT analysis (1024-point with Hamming window)
- 3 configurable frequency bands
- dB level calculation with calibration
- WiFi connectivity
- HTTP client for data transmission
- NTP time synchronization
- Configurable via menuconfig

**Files Created:**
- `main/main.c` - Complete firmware implementation (500+ lines)
- `main/CMakeLists.txt` - Build configuration
- `main/Kconfig.projbuild` - Configuration menu
- `CMakeLists.txt` - Project configuration
- `README.md` - Build and flash instructions

**Hardware Wiring:**
- GPIO 4 → I2S_DATA (INMP441 SD pin)
- GPIO 5 → I2S_BCLK (INMP441 SCK pin)
- GPIO 6 → I2S_WS (INMP441 WS pin)
- 3.3V → VDD, GND → GND, GND → L/R

### ✅ 2. Backend API Server (`backend/`)

**Node.js RESTful API server** with file-based storage:
- Device registration and management
- Measurement data storage
- API key authentication
- Configuration management
- Automatic data cleanup
- Winston logging

**Files Created:**
- `src/server.js` - Main Express server
- `src/routes/devices.js` - Device endpoints
- `src/routes/data.js` - Measurement endpoints
- `src/routes/config.js` - Configuration endpoints
- `src/models/Device.js` - Device storage model
- `src/models/Measurement.js` - Measurement storage model
- `src/utils/logger.js` - Winston logger
- `package.json` - Dependencies
- `.env` - Configuration
- `.gitignore` - Git ignore rules
- `README.md` - API documentation

**API Endpoints:**
- `POST /api/devices/register` - Register device
- `GET /api/devices` - List all devices
- `GET /api/devices/:id` - Get device details
- `POST /api/data/measurements` - Submit measurement (with auth)
- `GET /api/data/measurements/:id` - Get measurements
- `GET /api/config/devices/:id/frequency-bands` - Get config
- `PUT /api/config/devices/:id/calibration` - Update calibration

### ✅ 3. Frontend Web Dashboard (`frontend/`)

**Responsive web application** for monitoring and management:
- Real-time dashboard with live updates
- Device registration interface
- Measurement history viewer
- Device configuration
- Mobile-responsive design
- Auto-refresh (30 seconds)

**Files Created:**
- `index.html` - Main HTML structure
- `css/styles.css` - Complete styling (400+ lines)
- `js/api.js` - API client library
- `js/app.js` - Main application logic (400+ lines)
- `README.md` - Usage instructions

**Features:**
- Dashboard tab - Live device monitoring
- Devices tab - Registration and management
- History tab - Historical data viewer
- Settings tab - Configuration and cleanup

### ✅ 4. Documentation

**Complete documentation** for the entire system:
- `QUICKSTART.md` - Step-by-step setup guide
- `README.md` (main) - Updated with development status
- Component READMEs - Detailed instructions for each part
- Architecture docs - Updated with Environment #1 details

## Project Statistics

- **Total Files Created**: 20+ source files
- **Lines of Code**: 2000+ lines
- **Programming Languages**: C, JavaScript, HTML, CSS
- **Frameworks**: ESP-IDF, Node.js/Express, Vanilla JS
- **Documentation**: 5 README files + architecture docs

## Ready to Run

All three components are **ready to build and deploy**:

1. **Firmware**: Ready to flash to ESP32-C3
   ```bash
   cd firmware/sound-level-sensor
   . ~/esp/esp-idf/export.sh
   idf.py menuconfig  # Configure WiFi and server
   idf.py build flash monitor
   ```

2. **Backend**: Ready to start
   ```bash
   cd backend
   npm install
   PORT=3000 npm start
   ```

3. **Frontend**: Ready to serve
   ```bash
   cd frontend
   python3 -m http.server 8080
   ```

## Next Steps

1. **Configure firmware**: Set WiFi credentials and backend URL via menuconfig
2. **Start backend**: Install npm packages and start server
3. **Open frontend**: Access dashboard at http://localhost:8080
4. **Register device**: Use web interface to register ESP32
5. **Flash firmware**: Flash ESP32 with the API key from registration
6. **Monitor**: Watch live data appear on dashboard!

## Features Implemented

### ESP32 Firmware ✅
- [x] I2S audio sampling from INMP441
- [x] FFT analysis with windowing
- [x] Frequency band calculations
- [x] dB level measurements
- [x] WiFi connectivity
- [x] HTTP POST to backend
- [x] Configuration via menuconfig
- [x] Calibration support
- [x] NTP time sync

### Backend API ✅
- [x] Device registration
- [x] Device management
- [x] Measurement storage (file-based)
- [x] API key authentication
- [x] Configuration endpoints
- [x] Data cleanup
- [x] Winston logging
- [x] Error handling

### Frontend Dashboard ✅
- [x] Real-time dashboard
- [x] Device registration
- [x] Device list view
- [x] Measurement history
- [x] Settings configuration
- [x] Responsive design
- [x] Auto-refresh
- [x] Error handling

## System Architecture

```
┌─────────────────────┐
│  ESP32-C3 + INMP441 │
│                     │
│  - Samples audio    │
│  - FFT analysis     │
│  - Sends via WiFi   │
└──────────┬──────────┘
           │ HTTP POST
           │ (Home WiFi)
           ▼
┌─────────────────────┐
│  MacBook            │
│                     │
│  Backend API:3000   │◄──── Browser
│  Frontend:8080      │
│                     │
│  - Stores data      │
│  - Serves dashboard │
└─────────────────────┘
```

## Port Configuration

- **Backend API**: Port 3000 (available ✅)
- **Frontend UI**: Port 8080 (available ✅)
- **MacBook IP**: 192.168.68.67 (current)

**Note**: Port 5000 is in use by macOS ControlCenter, so we avoided it.

## Testing Checklist

Before first run:
- [ ] Backend dependencies installed (`npm install`)
- [ ] ESP32 connected via USB
- [ ] INMP441 wired to ESP32 (GPIO 4, 5, 6)
- [ ] WiFi credentials configured in firmware
- [ ] Backend URL set to MacBook IP in firmware
- [ ] API key obtained from device registration

## Success! 🎊

Your Sound Level Mesh System is **completely built** and ready for testing!

Check `QUICKSTART.md` for detailed setup instructions.

---

**Built**: January 30, 2026  
**Status**: Complete and ready for deployment  
**Environment**: Development Environment #1 (MacBook local)

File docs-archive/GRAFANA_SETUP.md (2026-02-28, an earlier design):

# Grafana Installation and Configuration Guide

## Installation (Run on production server: xibo.space.nova-labs.org)

```bash
# 1. Add Grafana repository
sudo mkdir -p /etc/apt/keyrings/
wget -q -O - https://apt.grafana.com/gpg.key | gpg --dearmor | sudo tee /etc/apt/keyrings/grafana.gpg > /dev/null
echo "deb [signed-by=/etc/apt/keyrings/grafana.gpg] https://apt.grafana.com stable main" | sudo tee /etc/apt/sources.list.d/grafana.list

# 2. Install Grafana
sudo apt-get update
sudo apt-get install -y grafana

# 3. Install JSON datasource plugin
sudo grafana-cli plugins install simpod-json-datasource

# 4. Configure Grafana port (to avoid conflict with backend on 3000)
sudo sed -i 's/;http_port = 3000/http_port = 3001/' /etc/grafana/grafana.ini

# 5. Start Grafana
sudo systemctl daemon-reload
sudo systemctl enable grafana-server
sudo systemctl start grafana-server
sudo systemctl status grafana-server
```

## Access Grafana

- **URL:** http://xibo.space.nova-labs.org:3001
- **Default Username:** admin
- **Default Password:** admin
- You'll be prompted to change password on first login

## Configure JSON Datasource

1. Login to Grafana
2. Go to Configuration → Data Sources
3. Click "Add data source"
4. Search for "JSON API" (simpod-json-datasource)
5. Configure:
   - **Name:** Sound Monitoring System
   - **URL:** http://localhost:3000/api/grafana
   - Click "Save & Test"

## Create Dashboard

### Method 1: Import Pre-configured Dashboard

Save this JSON to a file and import it in Grafana:

```json
{
  "dashboard": {
    "title": "Sound Monitoring Mesh",
    "panels": [
      {
        "id": 1,
        "title": "All Sensors - dB Levels",
        "type": "graph",
        "targets": [
          {
            "target": "08:92:72:84:1c:ec.db_level_peak",
            "refId": "A",
            "type": "timeserie"
          },
          {
            "target": "08:92:72:84:1d:18.db_level_peak",
            "refId": "B",
            "type": "timeserie"
          },
          {
            "target": "08:92:72:84:1d:1c.db_level_peak",
            "refId": "C",
            "type": "timeserie"
          }
        ],
        "gridPos": {
          "h": 8,
          "w": 24,
          "x": 0,
          "y": 0
        }
      }
    ]
  }
}
```

### Method 2: Manual Dashboard Creation

1. Click "+" → "Dashboard"
2. Click "Add new panel"
3. Select datasource: "Sound Monitoring System"
4. In the query editor, type a metric like: `08:92:72:84:1c:ec.db_level_peak`
5. Repeat to add more sensors
6. Save dashboard

## Available Metrics

All sensors report:
- `{device_id}.db_level` - Average dB level
- `{device_id}.db_level_peak` - Peak dB level
- `{device_id}.band_1` - Low frequency band (20-200 Hz)
- `{device_id}.band_2` - Mid frequency band (200-2000 Hz)
- `{device_id}.band_3` - High frequency band (2000-8000 Hz)

Aggregate metrics:
- `all.avg` - Average across all sensors
- `all.max` - Maximum across all sensors
- `all.min` - Minimum across all sensors

## Device IDs

- Blue: 08:92:72:84:1c:ec
- Yellow: 08:92:72:84:1d:18
- Grey: 08:92:72:84:1d:1c
- Orange: 08:92:72:84:1d:4c
- Green: 08:92:72:84:1d:50
- Red: 08:92:72:84:1d:84
- Black: 08:92:72:84:1d:d4
- Pink: 08:92:72:84:1e:34
- Purple: 08:92:72:84:1e:4c

## Troubleshooting

### Check Grafana status
```bash
sudo systemctl status grafana-server
```

### View Grafana logs
```bash
sudo journalctl -u grafana-server -f
```

### Check datasource connectivity
```bash
curl -X POST http://localhost:3000/api/grafana/search \
  -H "Content-Type: application/json" \
  -d '{"target":""}'
```

### Restart Grafana
```bash
sudo systemctl restart grafana-server
```

## Security Notes

- Grafana runs on port 3001 (backend on 3000)
- Change default admin password immediately
- Consider setting up SSL/HTTPS through Apache proxy
- Restrict firewall access if needed

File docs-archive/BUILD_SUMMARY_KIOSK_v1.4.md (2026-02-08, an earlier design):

# Build Summary - Kiosk Display Implementation (v1.4)

**Date**: February 2, 2026
**Status**: Complete - Ready for Testing

## Overview

Successfully implemented a public kiosk display system for the Sound Monitoring Mesh System, optimized for 1080p monitors and designed for unattended operation.

## Documents Updated

### 1. Product Requirements Document (PRD)
**File**: `sound level mesh system PRD.md`
- Updated version to 1.4
- Added Feature F6D: Public Kiosk Display with comprehensive requirements
- Added 4 user stories (Epic 6) for kiosk display
- Updated timeline with Phase 4 for kiosk display development
- Added risk mitigation for kiosk operation
- Updated glossary with kiosk-related terms

### 2. Architecture Document
**File**: `sound level mesh architecture.md`
- Updated version to 1.4
- Added kiosk display to component overview
- Added public kiosk display section to application structure
- Added kiosk display component to component list

### 3. Hardware Design Document
**File**: `sound level mesh hardware design.md`
- Updated version to 1.3
- Added Section 14: Public Kiosk Display Hardware Requirements
- Detailed hardware specifications (monitors, computers, network)
- Added software requirements (OS, browsers, kiosk mode)
- Comprehensive installation checklist
- Budget configurations (Budget/Standard/Professional)
- Maintenance guidelines

## Frontend Implementation

### New Files Created

#### 1. kiosk.html
**Location**: `frontend/kiosk.html`
**Features**:
- 1080p optimized layout (1920x1080)
- Full-screen design without chrome
- Large workshop map (SVG-based)
- Sidebar with system status, sensor list, events, and legend
- Real-time connection status indicator
- Auto-refresh every 10 seconds

#### 2. css/kiosk.css
**Location**: `frontend/css/kiosk.css`
**Features**:
- Dark theme optimized for readability
- High-contrast color scheme
- Large, legible fonts (18px+ body, 24px+ headings)
- Color-coded sensor status (green/yellow/red)
- Animated sound source markers
- Responsive sidebar with scrolling
- Loading and error states

#### 3. js/kiosk.js
**Location**: `frontend/js/kiosk.js`
**Features**:
- Auto-refresh every 10 seconds
- Fetches devices, sensor positions, and sound sources
- Updates system status and sensor list
- Renders SVG map with sensors and sound sources
- Real-time connection status monitoring
- Prevents accidental navigation
- Configurable API endpoints and refresh rate
- Map coordinate scaling for workshop layout

#### 4. KIOSK_DISPLAY.md
**Location**: `frontend/KIOSK_DISPLAY.md`
**Content**:
- Complete user guide for kiosk display
- Setup instructions for various platforms
- Hardware requirements and recommendations
- Configuration options
- Troubleshooting guide
- Maintenance schedule

### Modified Files

#### 1. index.html
**Changes**:
- Added "📺 Kiosk Display" link in header
- Opens kiosk display in new tab
- Positioned in top-right corner

#### 2. css/styles.css
**Changes**:
- Added `.kiosk-link` styles
- Gradient background with hover effects
- Positioned absolutely in header

## Backend Implementation

### New Files Created

#### 1. routes/triangulation.js
**Location**: `backend/src/routes/triangulation.js`
**Endpoints**:
- `GET /api/triangulation/sensors` - Get sensor positions for map
- `GET /api/triangulation/barriers` - Get acoustic barriers
- `GET /api/triangulation/sources/recent` - Get recent sound sources
- `GET /api/triangulation/kiosk/data` - All-in-one endpoint for kiosk display

### Modified Files

#### 1. server.js
**Changes**:
- Imported triangulation routes
- Added route mounting: `app.use('/api/triangulation', triangulationRoutes)`

## Firmware

**Status**: No changes required

The existing firmware already provides all necessary data:
- Sound level measurements
- Event detection with timestamps
- Device status and last seen information
- Frequency band measurements

The kiosk display is a frontend-only feature that consumes data from the backend API.

## API Endpoints Summary

### New Endpoints for Kiosk Display

1. **GET /api/triangulation/sensors**
   - Returns: Array of sensors with positions
   - Used by: Map visualization

2. **GET /api/triangulation/barriers**
   - Returns: Array of acoustic barriers
   - Used by: Map visualization

3. **GET /api/triangulation/sources/recent?minutes=10&limit=20**
   - Returns: Recent sound source locations
   - Used by: Events list and map markers

4. **GET /api/triangulation/kiosk/data**
   - Returns: All data in single request (devices, sensors, sources, barriers)
   - Used by: Optional consolidated data fetch

### Existing Endpoints Used

- **GET /api/devices** - Device list and status
- **GET /api/sources/recent** - Alternative source endpoint

## Testing Checklist

### Backend Testing
- [ ] Start backend server: `cd backend && npm start`
- [ ] Verify `/api/triangulation/sensors` returns sensor data
- [ ] Verify `/api/triangulation/sources/recent` returns source data
- [ ] Verify `/api/triangulation/kiosk/data` returns complete data
- [ ] Check CORS is enabled for frontend access

### Frontend Testing
- [ ] Start frontend server: `cd frontend && python3 -m http.server 8080`
- [ ] Open main dashboard: `http://localhost:8080/index.html`
- [ ] Verify "Kiosk Display" link appears in header
- [ ] Click link and verify kiosk page opens in new tab
- [ ] Verify kiosk display at: `http://localhost:8080/kiosk.html`
- [ ] Check connection status shows "Connected"
- [ ] Verify sensors appear in sidebar
- [ ] Verify map renders with grid
- [ ] Check data updates every 10 seconds
- [ ] Test with multiple sensors online/offline
- [ ] Test with triangulated sound sources

### Kiosk Mode Testing
- [ ] Test Chrome kiosk mode launch
- [ ] Verify full-screen display (no scroll bars)
- [ ] Check readability from 3-5 meters
- [ ] Test 24-hour continuous operation
- [ ] Verify auto-recovery after network disconnection
- [ ] Test browser refresh prevention

### Display Testing (1080p Monitor)
- [ ] Verify layout fits 1920x1080 without scrolling
- [ ] Check text is legible at viewing distance
- [ ] Verify colors and contrast in various lighting
- [ ] Test on actual kiosk hardware if available

## Known Limitations

1. **Sensor Positions**: Requires manual position configuration in device settings
2. **Map Scaling**: Currently assumes 100m x 75m workshop, needs adjustment per installation
3. **Barriers**: Requires manual barrier configuration via API
4. **Sound Sources**: Requires triangulation system to be operational
5. **Single Location**: One kiosk display per backend instance

## Future Enhancements

Potential improvements for future versions:
- Multiple workshop support
- User-configurable map dimensions
- Drag-and-drop sensor positioning from kiosk
- Historical replay with timeline scrubbing
- Sound level heatmaps
- Customizable color themes
- Audio alerts for critical events
- QR code for mobile access
- Multi-language support

## Deployment Instructions

### Development Environment
1. Start backend: `cd backend && npm start`
2. Start frontend: `cd frontend && python3 -m http.server 8080`
3. Access kiosk: `http://localhost:8080/kiosk.html`

### Production Environment (Raspberry Pi Example)

1. **Install Dependencies**:
```bash
sudo apt-get update
sudo apt-get install chromium-browser unclutter xdotool
```

2. **Configure Auto-Start** (`~/.config/lxsession/LXDE-pi/autostart`):
```bash
@xset s off
@xset -dpms
@xset s noblank
@chromium-browser --noerrdialogs --disable-infobars --kiosk http://SERVER_IP:8080/kiosk.html
@unclumber -idle 0
```

3. **Disable Screen Saver**:
```bash
sudo raspi-config
# Display Options -> Screen Blanking -> Disable
```

4. **Set Static IP** (recommended)
5. **Configure Backend URL** in kiosk.js
6. **Reboot and Test**

## File Structure

```
sound monitoring mesh/
├── sound level mesh system PRD.md          [UPDATED]
├── sound level mesh architecture.md        [UPDATED]
├── sound level mesh hardware design.md     [UPDATED]
├── backend/
│   └── src/
│       ├── server.js                       [MODIFIED]
│       └── routes/
│           └── triangulation.js            [NEW]
└── frontend/
    ├── kiosk.html                          [NEW]
    ├── index.html                          [MODIFIED]
    ├── KIOSK_DISPLAY.md                   [NEW]
    ├── css/
    │   ├── kiosk.css                       [NEW]
    │   └── styles.css                      [MODIFIED]
    └── js/
        └── kiosk.js                        [NEW]
```

## Summary

✅ **Documentation**: All design documents updated (PRD, Architecture, Hardware)
✅ **Frontend**: Complete kiosk display implementation with HTML/CSS/JS
✅ **Backend**: New API endpoints for kiosk data
✅ **Integration**: Link from main dashboard to kiosk display
✅ **Documentation**: Comprehensive user guide and setup instructions
✅ **Firmware**: No changes required (uses existing data)

The kiosk display is now ready for testing and deployment. All requirements from the PRD have been implemented.

## Next Steps

1. Test backend API endpoints
2. Test kiosk display in browser
3. Test on actual 1080p monitor
4. Configure sensor positions for map display
5. Test in kiosk mode (Chrome --kiosk flag)
6. Deploy to Raspberry Pi or kiosk hardware
7. Conduct 24-hour stability test
8. Gather user feedback
9. Fine-tune map scaling and layout as needed
10. Document any production-specific configurations

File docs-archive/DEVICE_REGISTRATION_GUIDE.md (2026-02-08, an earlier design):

# Device Registration Guide - Shared API Key System

## ✅ System Configuration

This system uses a **shared API key** approach where all devices use the same API key compiled into the firmware. Each device is uniquely identified by its MAC address.

**Key Points:**
- ✅ One firmware build flashed to all devices
- ✅ Each device auto-identifies with unique MAC address
- ✅ All devices use the same API key for authentication
- ✅ Suitable for trusted, internal networks

## How Device Registration Works

### 1. Automatic Device ID (Firmware)
Each ESP32 automatically uses its MAC address as the device ID:
- Example: `08:92:72:84:1d:18`
- No manual configuration needed
- Unique for each device
- Read from factory-burned MAC address

### 2. Shared API Key Configuration
- **Firmware**: Set once via `CONFIG_API_KEY` in `sdkconfig` (e.g., `YOUR_API_KEY_HERE`)
- **Backend**: Set via `SHARED_API_KEY` or `API_KEY` in `.env` file
- **Must match exactly** for devices to authenticate
- Same key used for all 10 devices

### 2. Backend Registration
When a device first connects, it can self-register OR you can pre-register it:

#### Option A: Manual Pre-Registration (Recommended)
Use the frontend web interface at `http://localhost:3000`:
1. Click "Register Device" button
2. Fill in the form:
   - **Device ID**: The MAC address (e.g., `08:92:72:84:1d:18`)
   - **MAC Address**: Same as device ID
   - **Name**: Friendly name (e.g., "Front Door Sensor")
   - **Location**: Physical location (e.g., "Building A - Entrance")
3. Click "Register"
4. Backend automatically assigns the shared API key (matches firmware CONFIG_API_KEY)
5. Device starts sending data within 5-10 seconds

#### Option B: Auto-Registration via API
The ESP32 can auto-register on first boot by calling:
```bash
POST /api/devices/register
{
  "device_id": "08:92:72:84:1d:18",
  "mac_address": "08:92:72:84:1d:18",
  "name": "Sensor 1",
  "location": "Unknown"
}
```

**Note**: With shared API key, all devices receive the same `api_key` value during registration (from backend environment variable).

### 3. Device Configuration
After registration, the device will:
- Automatically fetch frequency band configuration
- Apply calibration settings
- Start sending measurements

## Verifying Registration

### Check Serial Output
When monitoring the ESP32, you should see:
```
I (xxx) SOUND_SENSOR: Device ID: 08:92:72:84:1d:18
I (xxx) SOUND_SENSOR: WiFi connected
I (xxx) SOUND_SENSOR: Fetching configuration...
I (xxx) SOUND_SENSOR: Config received, starting measurements
```

### Check Backend
View registered devices:
```bash
# List all devices
curl http://localhost:3000/api/devices

# Check specific device
curl http://localhost:3000/api/devices/08:92:72:84:1d:18
```

### Check Frontend
1. Open `http://localhost:3000` in browser
2. Navigate to "Devices" tab
3. You should see all registered devices with their MAC addresses

## Device ID Format

✅ **Supported format**: `08:92:72:84:1d:18` (colon-separated hex)

The backend and frontend both handle colons in device IDs correctly:
- URLs are properly encoded
- File names use the MAC address format
- All API endpoints work with this format

## Setting Up 10 Devices

### Quick Workflow
1. **Flash all ESP32s** with the same firmware (see [FLASHING_MULTIPLE_DEVICES.md](FLASHING_MULTIPLE_DEVICES.md))
2. **Power up one device** at a time
3. **Monitor serial output** to get its MAC address
4. **Register in frontend** with meaningful name and location
5. **Repeat** for all 10 devices

### Example Device List
| Device ID | Name | Location |
|---|---|---|
| 08:92:72:84:1d:18 | Sensor 01 | Front Entrance |
| 08:92:72:84:2a:3c | Sensor 02 | Conference Room A |
| 08:92:72:84:1f:92 | Sensor 03 | Manufacturing Floor |
| ... | ... | ... |

## Troubleshooting

### Device Not Registering
1. Check WiFi credentials are correct in firmware `sdkconfig`
2. Verify backend server URL in firmware matches your backend
3. Check backend server is running: `cd backend && npm start`
4. Monitor serial output for error messages

### Device ID Not Showing
1. The MAC address is read at startup - check serial monitor output
2. Format should be lowercase with colons: `08:92:72:84:1d:18`
3. Each ESP32 has a unique MAC address - no duplicates possible

### API Key Mismatch Issues
**Symptoms**: Device connects but measurements are rejected (403 errors)

**Solution**:
1. Check firmware API key:
   ```bash
   cd firmware/sound-level-sensor
   grep CONFIG_API_KEY sdkconfig
   ```
2. Check backend API key:
   ```bash
   cd backend
   grep SHARED_API_KEY .env
   # or
   grep API_KEY .env
   ```
3. **Verify they match exactly** (including case and special characters)
4. If they don't match:
   - Update backend `.env` file to match firmware, OR
   - Rebuild and reflash firmware with correct key
5. Restart backend server after .env changes
6. Check backend logs for authentication errors:
   ```bash
   tail -f backend/data/logs/server.log
   ```

### Devices Show Zero Data
**This was the original issue** - all devices except the first were showing zeros because they had different API keys than the firmware. Now with shared key approach:
- All devices use same API key from firmware
- All devices registered with same key in backend
- All devices should send data successfully

## Next Steps

1. ✅ Data cleared
2. ✅ Firmware updated for MAC address IDs
3. ⏳ Flash all 10 ESP32 devices
4. ⏳ Register each device in the system
5. ⏳ Verify measurements are being received

See [FLASHING_MULTIPLE_DEVICES.md](FLASHING_MULTIPLE_DEVICES.md) for flashing instructions.

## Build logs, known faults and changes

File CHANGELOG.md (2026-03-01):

# Changelog

All notable changes to the Sound Monitoring Mesh System will be documented in this file.

The format is based on [Keep a Changelog](https://keepachangelog.com/en/1.0.0/),
and this project adheres to [Semantic Versioning](https://semver.org/spec/v2.0.0.html).

## [2.1.1-prod] - 2026-02-28

### Fixed
- **Critical**: I2S DMA mis-packing caused by using `I2S_DATA_BIT_WIDTH_24BIT` instead of `I2S_DATA_BIT_WIDTH_32BIT` — resulted in constant ~110 dB readings regardless of actual audio level
- Frequency band SPL calculation rewritten to use self-normalizing energy fraction (avoids dependence on absolute FFT magnitude scale)
- 10 kΩ pull-down resistor on SD line (GPIO 4 to GND) confirmed required and documented

### Added
- `2.1.1-prod` firmware binary for production (Nova Labs WiFi + production backend)
- `2.1.2-dev` firmware binary for development OTA testing (dev WiFi + local backend)
- Removed legacy `versions-prod.json`; all versions tracked in `versions.json`

---

## [2.0.0] - 2026-02-12

### Added
- **Major Feature**: Historical data playback for triangulation visualization
  - Timeline controls with play/pause, jog forward/backward
  - Variable playback speed (0.25x, 0.5x, 1x, 2x, 5x, 10x)
  - Date/time range selection (day, hour, minute, second precision)
  - Transport controls (skip to start/end, jog 1 second)
  - Real-time timeline slider with progress indicator
  - Historical sensor state visualization
  - Historical sound source replay
  - Data caching for smooth playback
- Backend API endpoints for historical playback:
  - `/api/triangulation/playback/measurements` - Get measurements in time range
  - `/api/triangulation/playback/sources` - Get sound sources in time range
  - `/api/triangulation/playback/window` - Get data for specific time window
  - `/api/triangulation/playback/range` - Get available data range
- `PlaybackController` class for managing playback state and controls
- `getAvailableDates()` method in Measurement model
- `getLocationsByDateRange()` method in SourceLocation model
- Comprehensive playback UI with responsive design
- Playback mode indicator and controls styling

### Changed
- Version synchronized to 2.0.0 across all components
- Enhanced triangulation interface with playback mode toggle
- Updated frontend script versions for cache busting

### Developer Notes
- Playback feature implemented on dev system only (not yet deployed to production)
- Historical data playback allows analysis of past sound events
- Playback speed control enables both detailed analysis (slow) and overview (fast)

## [1.2.0] - 2026-02-11

### Added
- Kiosk display page for public-facing sound level monitoring
- Kiosk debug tool for API connectivity testing
- Production firmware deployment script with device identification
- Comprehensive flashing scripts for bulk sensor updates
- Firmware flash log tracking

### Fixed
- **Critical**: Fixed Apache ProxyPass configuration causing double `/api/api/` paths
- **Critical**: Fixed frontend API configuration to auto-detect production vs localhost
- Fixed kiosk.js JavaScript syntax errors in multiple functions
- Fixed kiosk triangulation endpoint paths to work with Apache proxy
- Fixed API module method calls for proper path construction
- Added missing `createMapLabel` function for map labels display
- Fixed `formatTimeAgo` function corruption
- Fixed `createSensorItem` incomplete HTML template
- Fixed `updateMap` function duplication and corruption

### Changed
- Updated frontend API module to use environment-aware base URLs
- Added cache-busting version parameters (v=16 through v=22) to frontend scripts
- Improved localStorage handling to clear cached localhost URLs in production
- Enhanced debug.html page with better error reporting
- Synced WiFi credentials to REDACTED_WORKSHOP_WIFI_SSID network for production deployment
- Updated server URL to xibo.space.nova-labs.org/api/sound

### Production Deployment
- Successfully flashed 5 sensors with firmware v1.2.1-prod
  - Identified: Green (08:92:72:84:1d:50), Purple (08:92:72:84:1e:4c)
  - 3 additional sensors flashed but pending physical identification
- Confirmed Blue sensor (08:92:72:84:1c:ec) actively posting data
- 9 total sensors registered in system

### Infrastructure
- Apache 2.4.41 reverse proxy configured
- Node.js backend deployed on port 3000
- Frontend served via Apache at /sound/ path
- Production server: xibo.space.nova-labs.org

## [1.1.1] - 2026-02-08

### Added
- Dual PDM microphone support (INMP441)
- Frequency band analysis (SPL per band)
- Device registration API endpoint
- Triangulation service for sound source localization
- Acoustic barrier modeling

### Changed
- Improved SPL calibration accuracy
- Enhanced WiFi auto-reconnect logic
- Optimized measurement posting frequency

## [1.0.0] - 2026-01-15

### Added
- Initial release
- ESP32-C3 firmware with WiFi connectivity
- Backend API server with Express.js
- Frontend dashboard with real-time updates
- Device management and configuration
- Measurement data collection and storage
- Alert system for threshold violations

[2.1.1-prod]: https://github.com/sklosky-nl/sound-monitoring-mesh/compare/v2.0.0...v2.1.1-prod
[2.0.0]: https://github.com/sklosky-nl/sound-monitoring-mesh/compare/v1.2.0...v2.0.0
[1.2.0]: https://github.com/sklosky-nl/sound-monitoring-mesh/compare/v1.1.1...v1.2.0
[1.1.1]: https://github.com/sklosky-nl/sound-monitoring-mesh/compare/v1.0.0...v1.1.1
[1.0.0]: https://github.com/sklosky-nl/sound-monitoring-mesh/releases/tag/v1.0.0

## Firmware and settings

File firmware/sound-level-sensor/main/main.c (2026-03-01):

/**
 * Sound Level Sensor - ESP32-C3 Firmware
 * 
 * This firmware samples audio from an INMP441 I2S microphone,
 * performs FFT analysis for frequency band measurements,
 * calculates dB levels, and transmits data to a backend server via WiFi.
 */

#include <stdio.h>
#include <string.h>
#include <math.h>
#include "freertos/FreeRTOS.h"
#include "freertos/task.h"
#include "freertos/event_groups.h"
#include "esp_system.h"
#include "esp_mac.h"
#include "esp_wifi.h"
#include "esp_event.h"
#include "esp_log.h"
#include "nvs_flash.h"
#include "esp_netif.h"
#include "esp_http_client.h"
#include "esp_sntp.h"
#include "mdns.h"
#include "driver/i2s_std.h"
#include "esp_dsp.h"
#include "cJSON.h"
#include "esp_ota_ops.h"
#include "esp_http_client.h"
#include "esp_https_ota.h"
#include "driver/gpio.h"

// Firmware Version
#define FIRMWARE_VERSION "2.1.2-dev"

// Configuration
// Device ID will be set dynamically based on MAC address
static char device_id[32];  // Global device ID based on MAC address
#define WIFI_SSID CONFIG_WIFI_SSID
#define WIFI_PASS CONFIG_WIFI_PASSWORD
#define SERVER_URL CONFIG_SERVER_URL
#define API_KEY CONFIG_API_KEY

// OTA Configuration
#define OTA_CHECK_INTERVAL_MS (3600000)  // Check for updates every hour
#define OTA_RECV_TIMEOUT 5000
#define OTA_BUFFER_SIZE 1024

// I2S Configuration for INMP441
#define I2S_PORT I2S_NUM_0
#define I2S_SAMPLE_RATE 16000
#define I2S_BITS_PER_SAMPLE 32  // INMP441 outputs 24-bit, but we use 32-bit container
#define I2S_CHANNELS 1
#define I2S_DMA_BUF_COUNT 4
#define I2S_DMA_BUF_LEN 1024

// GPIO Pins (ESP32-C3 to INMP441)
#define I2S_BCK_PIN 5   // I2S_BCLK
#define I2S_WS_PIN 6    // I2S_WS
#define I2S_DATA_PIN 4  // I2S_DATA

// FFT Configuration
#define FFT_SIZE 1024
#define SAMPLE_BUFFER_SIZE FFT_SIZE

// Frequency Bands (configurable)
#define NUM_BANDS 3
typedef struct {
    int band_number;
    float start_freq;
    float end_freq;
    float level;
} freq_band_t;

// Event Detection Configuration
#define EVENT_THRESHOLD_DB 55.0f  // Threshold for detecting sound events
#define EVENT_RISE_RATE_DB_PER_SEC 5.0f  // Minimum rise rate to consider it an event
#define EVENT_MIN_DURATION_MS 50  // Minimum duration to be considered an event
#define EVENT_MAX_DURATION_MS 5000  // Maximum duration to track
#define EVENT_COOLDOWN_MS 500  // Cooldown period after event ends

typedef struct {
    bool is_active;
    int64_t onset_timestamp_us;  // Microsecond timestamp when event started
    float peak_amplitude_db;
    int64_t peak_timestamp_us;
    int32_t duration_ms;
    float onset_db;
    float previous_db;
    int64_t event_start_time;
    int64_t last_above_threshold_time;
} event_detector_t;

// Calibration offset (configurable from server)
static float calibration_offset_db = 0.0f;

// Peak tracking for continuous sampling
static float peak_db_window = 0.0f;
static float rms_accumulator = 0.0f;
static int rms_sample_count = 0;
#define REPORTING_INTERVAL_SAMPLES 78  // ~5 seconds at 64ms per sample (1024 samples @ 16kHz)

// WiFi event group
static EventGroupHandle_t s_wifi_event_group;
#define WIFI_CONNECTED_BIT BIT0
#define WIFI_FAIL_BIT BIT1

static const char *TAG = "SOUND_SENSOR";
static int s_retry_num = 0;
static i2s_chan_handle_t rx_handle = NULL;

// Frequency bands configuration
static freq_band_t frequency_bands[NUM_BANDS] = {
    {1, 20, 200, 0},
    {2, 200, 2000, 0},
    {3, 2000, 8000, 0}
};

// Event detector state
static event_detector_t event_detector = {
    .is_active = false,
    .onset_timestamp_us = 0,
    .peak_amplitude_db = 0,
    .peak_timestamp_us = 0,
    .duration_ms = 0,
    .onset_db = 0,
    .previous_db = 30.0f,  // Start with minimum expected level
    .event_start_time = 0,
    .last_above_threshold_time = 0
};

// HTTP response buffer for configuration
#define CONFIG_BUFFER_SIZE 2048
static char config_buffer[CONFIG_BUFFER_SIZE];
static int config_buffer_index = 0;

// Forward declarations
static void wifi_event_handler(void* arg, esp_event_base_t event_base,
                              int32_t event_id, void* event_data);
static void init_wifi(void);
static void init_mdns(void);
static void init_i2s(void);
static void init_sntp(void);
static void audio_sampling_task(void *pvParameters);
static float calculate_db_level(float* magnitude, int size);
static float calculate_dbfs(float* samples, int size);
static float calculate_dbfs_from_i2s(const int32_t* buffer, int size, int mode, int32_t* peak_abs_out);
static void calculate_frequency_bands(float* fft_magnitude, int fft_size, int sample_rate, float overall_db);
static void apply_hamming_window(float* samples, int size);
static esp_err_t send_measurement_data(float db_level, float db_peak, freq_band_t* bands, int num_bands);
static void ota_task(void *pvParameters);
static esp_err_t check_and_perform_ota_update(void);

// WiFi event handler
static void wifi_event_handler(void* arg, esp_event_base_t event_base,
                              int32_t event_id, void* event_data)
{
    if (event_base == WIFI_EVENT && event_id == WIFI_EVENT_STA_START) {
        esp_wifi_connect();
    } else if (event_base == WIFI_EVENT && event_id == WIFI_EVENT_STA_DISCONNECTED) {
        if (s_retry_num < 10) {
            esp_wifi_connect();
            s_retry_num++;
            ESP_LOGI(TAG, "Retry connecting to WiFi...");
        } else {
            xEventGroupSetBits(s_wifi_event_group, WIFI_FAIL_BIT);
        }
        ESP_LOGI(TAG, "Failed to connect to WiFi");
    } else if (event_base == IP_EVENT && event_id == IP_EVENT_STA_GOT_IP) {
        ip_event_got_ip_t* event = (ip_event_got_ip_t*) event_data;
        ESP_LOGI(TAG, "Got IP: " IPSTR, IP2STR(&event->ip_info.ip));
        s_retry_num = 0;
        xEventGroupSetBits(s_wifi_event_group, WIFI_CONNECTED_BIT);
    }
}

// Initialize WiFi
static void init_wifi(void)
{
    s_wifi_event_group = xEventGroupCreate();

    ESP_ERROR_CHECK(esp_netif_init());
    ESP_ERROR_CHECK(esp_event_loop_create_default());
    esp_netif_create_default_wifi_sta();

    wifi_init_config_t cfg = WIFI_INIT_CONFIG_DEFAULT();
    ESP_ERROR_CHECK(esp_wifi_init(&cfg));

    esp_event_handler_instance_t instance_any_id;
    esp_event_handler_instance_t instance_got_ip;
    ESP_ERROR_CHECK(esp_event_handler_instance_register(WIFI_EVENT,
                                                        ESP_EVENT_ANY_ID,
                                                        &wifi_event_handler,
                                                        NULL,
                                                        &instance_any_id));
    ESP_ERROR_CHECK(esp_event_handler_instance_register(IP_EVENT,
                                                        IP_EVENT_STA_GOT_IP,
                                                        &wifi_event_handler,
                                                        NULL,
                                                        &instance_got_ip));

    wifi_config_t wifi_config = {
        .sta = {
            .ssid = WIFI_SSID,
            .password = WIFI_PASS,
            .threshold.authmode = WIFI_AUTH_OPEN,  // Allow any auth mode (WPA2/WPA3)
            .sae_pwe_h2e = WPA3_SAE_PWE_BOTH,     // Support both WPA3 methods
        },
    };
    ESP_ERROR_CHECK(esp_wifi_set_mode(WIFI_MODE_STA));
    ESP_ERROR_CHECK(esp_wifi_set_config(WIFI_IF_STA, &wifi_config));
    ESP_ERROR_CHECK(esp_wifi_start());

    ESP_LOGI(TAG, "WiFi initialization finished.");

    // Wait for connection
    EventBits_t bits = xEventGroupWaitBits(s_wifi_event_group,
            WIFI_CONNECTED_BIT | WIFI_FAIL_BIT,
            pdFALSE,
            pdFALSE,
            portMAX_DELAY);

    if (bits & WIFI_CONNECTED_BIT) {
        ESP_LOGI(TAG, "Connected to WiFi SSID:%s", WIFI_SSID);
        // Initialize mDNS after WiFi is connected
        init_mdns();
    } else if (bits & WIFI_FAIL_BIT) {
        ESP_LOGI(TAG, "Failed to connect to SSID:%s", WIFI_SSID);
    }
}

// Initialize mDNS
static void init_mdns(void)
{
    ESP_LOGI(TAG, "Initializing mDNS...");
    esp_err_t err = mdns_init();
    if (err != ESP_OK) {
        ESP_LOGE(TAG, "mDNS Init failed: %d", err);
        return;
    }
    
    // Set hostname for this device (use last 6 chars of device_id to keep it short)
    char mdns_hostname[64];
    size_t id_len = strlen(device_id);
    const char *short_id = (id_len > 6) ? (device_id + id_len - 6) : device_id;
    snprintf(mdns_hostname, sizeof(mdns_hostname), "sound-sensor-%s", short_id);
    mdns_hostname_set(mdns_hostname);
    
    ESP_LOGI(TAG, "mDNS initialized. Hostname: %s.local", mdns_hostname);
}

// Initialize I2S for INMP441 microphone
static void init_i2s(void)
{
    i2s_chan_config_t chan_cfg = I2S_CHANNEL_DEFAULT_CONFIG(I2S_PORT, I2S_ROLE_MASTER);
    ESP_ERROR_CHECK(i2s_new_channel(&chan_cfg, NULL, &rx_handle));

    i2s_std_config_t std_cfg = {
        .clk_cfg = I2S_STD_CLK_DEFAULT_CONFIG(I2S_SAMPLE_RATE),
        .slot_cfg = I2S_STD_PHILIPS_SLOT_DEFAULT_CONFIG(I2S_DATA_BIT_WIDTH_32BIT, I2S_SLOT_MODE_MONO),
        .gpio_cfg = {
            .mclk = I2S_GPIO_UNUSED,
            .bclk = I2S_BCK_PIN,
            .ws = I2S_WS_PIN,
            .dout = I2S_GPIO_UNUSED,
            .din = I2S_DATA_PIN,
            .invert_flags = {
                .mclk_inv = false,
                .bclk_inv = false,
                .ws_inv = false,
            },
        },
    };

    std_cfg.slot_cfg.slot_mask = I2S_STD_SLOT_LEFT;
    std_cfg.slot_cfg.slot_bit_width = I2S_SLOT_BIT_WIDTH_32BIT;

    ESP_ERROR_CHECK(i2s_channel_init_std_mode(rx_handle, &std_cfg));
    ESP_ERROR_CHECK(i2s_channel_enable(rx_handle));

    ESP_LOGI(TAG, "I2S initialized for INMP441");
}

// Initialize SNTP for time synchronization
static void init_sntp(void)
{
    ESP_LOGI(TAG, "Initializing SNTP");
    esp_sntp_setoperatingmode(SNTP_OPMODE_POLL);
    esp_sntp_setservername(0, "pool.ntp.org");
    esp_sntp_init();
}

// HTTP event handler for configuration fetch
static esp_err_t config_http_event_handler(esp_http_client_event_t *evt)
{
    switch(evt->event_id) {
        case HTTP_EVENT_ON_DATA:
            if (config_buffer_index + evt->data_len < CONFIG_BUFFER_SIZE - 1) {
                memcpy(config_buffer + config_buffer_index, evt->data, evt->data_len);
                config_buffer_index += evt->data_len;
                config_buffer[config_buffer_index] = '\0';
            }
            break;
        default:
            break;
    }
    return ESP_OK;
}

// Register device with server
static bool register_device(void)
{
    ESP_LOGI(TAG, "Registering device with server...");
    
    // Build JSON payload
    char payload[512];
    snprintf(payload, sizeof(payload),
             "{\"device_id\":\"%s\",\"mac_address\":\"%s\",\"name\":\"Sound Sensor %s\",\"location\":\"Unknown\",\"api_key\":\"%s\",\"firmware_version\":\"%s\"}",
             device_id, device_id, device_id, API_KEY, FIRMWARE_VERSION);
    
    // Build URL
    char url[256];
    snprintf(url, sizeof(url), "%s/api/register", SERVER_URL);
    ESP_LOGI(TAG, "Registration URL: %s", url);
    ESP_LOGI(TAG, "Payload: %s", payload);
    
    esp_http_client_config_t config = {
        .url = url,
        .method = HTTP_METHOD_POST,
        .timeout_ms = 10000,
    };
    
    esp_http_client_handle_t client = esp_http_client_init(&config);
    
    // Set headers
    esp_http_client_set_header(client, "Content-Type", "application/json");
    esp_http_client_set_post_field(client, payload, strlen(payload));
    
    esp_err_t err = esp_http_client_perform(client);
    bool success = false;
    
    if (err == ESP_OK) {
        int status_code = esp_http_client_get_status_code(client);
        ESP_LOGI(TAG, "Registration response status: %d", status_code);
        
        if (status_code == 201 || status_code == 409) {
            // 201 = created, 409 = already exists (both are OK)
            ESP_LOGI(TAG, "Device registered successfully");
            success = true;
        } else {
            ESP_LOGW(TAG, "Registration failed with status: %d", status_code);
        }
    } else {
        ESP_LOGW(TAG, "HTTP POST request failed: %s", esp_err_to_name(err));
    }
    
    esp_http_client_cleanup(client);
    return success;
}

// Fetch configuration from server
static void fetch_configuration(void)
{
    ESP_LOGI(TAG, "Fetching configuration from server...");
    
    // Reset buffer
    config_buffer_index = 0;
    memset(config_buffer, 0, CONFIG_BUFFER_SIZE);
    
    // Build URL with URL-encoded device ID
    char url[256];
    char encoded_device_id[64];
    
    // URL encoding for device ID (encode special characters like : and spaces)
    const char *src = device_id;
    char *dst = encoded_device_id;
    while (*src && (dst - encoded_device_id) < sizeof(encoded_device_id) - 4) {
        if (*src == ' ') {
            *dst++ = '%';
            *dst++ = '2';
            *dst++ = '0';
        } else if (*src == ':') {
            *dst++ = '%';
            *dst++ = '3';
            *dst++ = 'A';
        } else {
            *dst++ = *src;
        }
        src++;
    }
    *dst = '\0';
    
    snprintf(url, sizeof(url), "%s/api/config/devices/%s/frequency-bands", SERVER_URL, encoded_device_id);
    ESP_LOGI(TAG, "Config URL: %s", url);
    
    esp_http_client_config_t config = {
        .url = url,
        .event_handler = config_http_event_handler,
        .timeout_ms = 5000,
    };
    
    esp_http_client_handle_t client = esp_http_client_init(&config);
    esp_err_t err = esp_http_client_perform(client);
    
    if (err == ESP_OK) {
        int status_code = esp_http_client_get_status_code(client);
        if (status_code == 200) {
            ESP_LOGI(TAG, "Configuration received: %s", config_buffer);
            
            // Parse JSON response
            cJSON *root = cJSON_Parse(config_buffer);
            if (root != NULL) {
                // Update calibration offset
                cJSON *calibration = cJSON_GetObjectItem(root, "calibration_offset_db");
                if (cJSON_IsNumber(calibration)) {
                    calibration_offset_db = (float)calibration->valuedouble;
                    ESP_LOGI(TAG, "Calibration offset: %.2f dB", calibration_offset_db);
                }
                
                // Update frequency bands
                cJSON *bands_array = cJSON_GetObjectItem(root, "frequency_bands");
                if (cJSON_IsArray(bands_array)) {
                    int band_count = cJSON_GetArraySize(bands_array);
                    if (band_count > NUM_BANDS) {
                        band_count = NUM_BANDS;
                    }
                    
                    for (int i = 0; i < band_count; i++) {
                        cJSON *band = cJSON_GetArrayItem(bands_array, i);
                        cJSON *band_num = cJSON_GetObjectItem(band, "band_number");
                        cJSON *start_freq = cJSON_GetObjectItem(band, "start_frequency");
                        cJSON *end_freq = cJSON_GetObjectItem(band, "end_frequency");
                        
                        if (cJSON_IsNumber(band_num) && cJSON_IsNumber(start_freq) && cJSON_IsNumber(end_freq)) {
                            int idx = band_num->valueint - 1;
                            if (idx >= 0 && idx < NUM_BANDS) {
                                frequency_bands[idx].band_number = band_num->valueint;
                                frequency_bands[idx].start_freq = (float)start_freq->valuedouble;
                                frequency_bands[idx].end_freq = (float)end_freq->valuedouble;
                                ESP_LOGI(TAG, "Band %d: %.0f-%.0f Hz", 
                                    frequency_bands[idx].band_number,
                                    frequency_bands[idx].start_freq,
                                    frequency_bands[idx].end_freq);
                            }
                        }
                    }
                }
                
                cJSON_Delete(root);
            } else {
                ESP_LOGW(TAG, "Failed to parse configuration JSON");
            }
        } else {
            ESP_LOGW(TAG, "HTTP GET failed, status code: %d", status_code);
        }
    } else {
        ESP_LOGW(TAG, "HTTP GET request failed: %s", esp_err_to_name(err));
    }
    
    esp_http_client_cleanup(client);
}

// Apply Hamming window to samples
static void apply_hamming_window(float* samples, int size)
{
    for (int i = 0; i < size; i++) {
        float window = 0.54f - 0.46f * cosf(2.0f * M_PI * i / (size - 1));
        samples[i] *= window;
    }
}

// Calculate A-weighting factor in dB for a given frequency
static float calculate_a_weighting(float freq)
{
    if (freq < 1.0f) {
        return -100.0f;  // Very low frequencies are heavily attenuated
    }
    
    // A-weighting formula (IEC 61672-1)
    float f2 = freq * freq;
    float numerator = 12194.0f * 12194.0f * f2 * f2;
    float denominator = (f2 + 20.6f * 20.6f) * 
                       sqrtf((f2 + 107.7f * 107.7f) * (f2 + 737.9f * 737.9f)) * 
                       (f2 + 12194.0f * 12194.0f);
    
    // Convert to dB and normalize (A-weighting is 0 dB at 1000 Hz)
    float a_weight = 20.0f * log10f(numerator / denominator) + 2.0f;
    
    return a_weight;
}

// Calculate overall dB SPL from time-domain RMS
static float calculate_db_level(float* samples, int size)
{
    float mean = 0.0f;
    for (int i = 0; i < size; i++) {
        mean += samples[i];
    }
    mean /= (float)size;

    float sum = 0.0f;
    for (int i = 0; i < size; i++) {
        float centered = samples[i] - mean;
        sum += centered * centered;
    }

    float rms = sqrtf(sum / (float)size);

    // Prevent log(0)
    if (rms < 1e-10f) {
        rms = 1e-10f;
    }

    // INMP441 calibration:
    // -26 dBFS corresponds to 94 dB SPL (1 Pa reference)
    // dB_SPL = 94 + (dBFS - (-26)) = 120 + 20*log10(rms)
    float db = 120.0f + 20.0f * log10f(rms);

    // Apply calibration offset
    db += calibration_offset_db;

    // Clamp to reasonable range (30-120 dB SPL)
    if (db < 30.0f) db = 30.0f;
    if (db > 120.0f) db = 120.0f;

    return db;
}

// Calculate raw dBFS from time-domain RMS (no SPL offset)
static float calculate_dbfs(float* samples, int size)
{
    float mean = 0.0f;
    for (int i = 0; i < size; i++) {
        mean += samples[i];
    }
    mean /= (float)size;

    float sum = 0.0f;
    for (int i = 0; i < size; i++) {
        float centered = samples[i] - mean;
        sum += centered * centered;
    }

    float rms = sqrtf(sum / (float)size);
    if (rms < 1e-10f) {
        rms = 1e-10f;
    }

    return 20.0f * log10f(rms);
}
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
void app_main(void)
{
    // v2.1.1-prod: OTA Response Reading Fix - Properly read JSON response for firmware updates
    ESP_LOGI(TAG, "Sound Level Sensor Starting...");
    ESP_LOGI(TAG, "Firmware Version: %s", FIRMWARE_VERSION);
    
    // Get and log partition information
    const esp_partition_t *running = esp_ota_get_running_partition();
    esp_ota_img_states_t ota_state;
    if (esp_ota_get_state_partition(running, &ota_state) == ESP_OK) {
        if (ota_state == ESP_OTA_IMG_PENDING_VERIFY) {
            ESP_LOGI(TAG, "OTA update pending verification - marking as valid");
            esp_ota_mark_app_valid_cancel_rollback();
        }
    }
    ESP_LOGI(TAG, "Running partition: %s", running->label);
    
    // Initialize device ID from MAC address
    uint8_t mac[6];
    esp_efuse_mac_get_default(mac);
    snprintf(device_id, sizeof(device_id), "%02x:%02x:%02x:%02x:%02x:%02x",
             mac[0], mac[1], mac[2], mac[3], mac[4], mac[5]);
    ESP_LOGI(TAG, "Device ID: %s", device_id);
    
    // Initialize NVS
    esp_err_t ret = nvs_flash_init();
    if (ret == ESP_ERR_NVS_NO_FREE_PAGES || ret == ESP_ERR_NVS_NEW_VERSION_FOUND) {
        ESP_ERROR_CHECK(nvs_flash_erase());
        ret = nvs_flash_init();
    }
    ESP_ERROR_CHECK(ret);
    
    // Initialize WiFi
    init_wifi();
    
    // Initialize SNTP
    init_sntp();
    
    // Wait a bit for time sync
    vTaskDelay(pdMS_TO_TICKS(2000));
    
    // Register device with server
    int registration_retries = 3;
    bool registered = false;
    while (registration_retries > 0 && !registered) {
        registered = register_device();
        if (!registered) {
            ESP_LOGW(TAG, "Registration failed, retrying... (%d attempts left)", registration_retries - 1);
            vTaskDelay(pdMS_TO_TICKS(2000));
            registration_retries--;
        }
    }
    
    if (!registered) {
        ESP_LOGE(TAG, "Failed to register device after multiple attempts");
        // Continue anyway - device may already be registered
    }
    
    // Fetch configuration from server
    fetch_configuration();
    
    // Initialize I2S
    init_i2s();
    
    // Start audio sampling task
    xTaskCreate(audio_sampling_task, "audio_sampling", 8192, NULL, 5, NULL);
    
    // Start OTA update task (lower priority, runs in background)
    xTaskCreate(ota_task, "ota_task", 8192, NULL, 3, NULL);
    
    ESP_LOGI(TAG, "Sound Level Sensor Running with OTA support");
}

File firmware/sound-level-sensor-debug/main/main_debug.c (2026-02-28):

/**
 * INMP441 / ESP32-C3 — Microphone Debug Firmware
 * ================================================
 * Purpose : Standalone UART diagnostic tool for verifying INMP441 wiring,
 *           I2S bit-alignment, and signal health — no WiFi or server needed.
 *
 * Hardware assumptions (same as production):
 *   GPIO 4  → INMP441 SD   (data)
 *   GPIO 5  → INMP441 SCK  (clock / BCLK)
 *   GPIO 6  → INMP441 WS   (word-select / LRCK)
 *   INMP441 L/R pin → GND  (selects LEFT channel)
 *   3.3 V VDD, GND
 *
 * What this firmware reports (every buffer, ~64 ms):
 *   - Raw I2S word [0] and descriptive bit pattern
 *   - dBFS via 3 alignment modes:
 *       Mode A: 32-bit MSB-aligned  (sample = raw word as-is)
 *       Mode B: 24-bit right-justified (lower 24 bits, sign-extended)
 *       Mode C: 24-bit left-justified (raw >> 8)  ← correct for INMP441
 *   - Estimated dB SPL (using Mode C + INMP441 calibration constant)
 *   - Peak, RMS, min/max, zero-count, clipping count
 *   - ASCII level meter
 *   - PASS / WARN / FAIL health assessment
 *
 * Every ~5 seconds a summary with running min/max SPL range is also printed.
 *
 * Compile & flash:
 *   source ~/esp/esp-idf/export.sh
 *   cd firmware/sound-level-sensor-debug
 *   idf.py set-target esp32c3
 *   idf.py build
 *   idf.py -p /dev/cu.usbmodem21101 flash monitor
 */

#include <stdio.h>
#include <string.h>
#include <math.h>
#include <stdint.h>
#include <inttypes.h>
#include "freertos/FreeRTOS.h"
#include "freertos/task.h"
#include "esp_log.h"
#include "esp_system.h"
#include "driver/i2s_std.h"
#include "driver/gpio.h"
#include "esp_timer.h"

/* ── Tag ──────────────────────────────────────────────────────────────────── */
static const char *TAG = "MIC_DEBUG";

/* ── I2S / Hardware constants  (match production wiring) ───────────────────
 *  BCK  = GPIO5   (bit clock)
 *  WS   = GPIO6   (word select / LR clock)
 *  DATA = GPIO4   (serial data from mic)
 */
#define I2S_BCK_PIN       5
#define I2S_WS_PIN        6
#define I2S_DATA_PIN      4
#define I2S_SAMPLE_RATE   16000
#define BUF_SAMPLES       1024        /* one FFT-sized frame = ~64 ms       */
#define DMA_BUF_COUNT     4
#define DMA_BUF_LEN       1024

/* ── INMP441 calibration ───────────────────────────────────────────────────
 *  Datasheet: -26 dBFS ≡ 94 dB SPL (1 kHz, 1 Pa)
 *  → dB_SPL = dBFS + 94 + 26 = dBFS + 120
 *  Sensitivity correction is absorbed into the +120 offset.
 */
#define INMP441_SPL_OFFSET  120.0f

/* ── Summary window ───────────────────────────────────────────────────────  */
#define SUMMARY_EVERY_N_BUFFERS  78   /* 78 × 64 ms ≈ 5 s                  */

/* ── Clipping threshold (24-bit signal) ────────────────────────────────────*/
#define CLIP_THRESHOLD_24BIT  (0x7FFFFF - 32)

/* ── Global I2S handle ─────────────────────────────────────────────────────*/
static i2s_chan_handle_t rx_handle = NULL;

/* ── Running stats for the 5-second summary ───────────────────────────────*/
static float  s_spl_min = 999.0f;
static float  s_spl_max = -999.0f;
static float  s_spl_sum = 0.0f;
static int    s_spl_cnt  = 0;
static int    s_buf_cnt  = 0;

/* =========================================================================
 * Helper: build a 30-character ASCII bar for the level meter.
 * spl_db is clamped to [30, 100] dB before mapping to bar width.
 * ========================================================================= */
static void build_bar(float spl_db, char *out, int out_len)
{
    const int BAR_FULL = 28;
    float clamped = spl_db < 30.0f ? 30.0f : (spl_db > 100.0f ? 100.0f : spl_db);
    int   filled  = (int)((clamped - 30.0f) / (100.0f - 30.0f) * BAR_FULL);
    if (filled > BAR_FULL) filled = BAR_FULL;

    int i = 0;
    out[i++] = '[';
    for (int k = 0; k < BAR_FULL && i < out_len - 2; k++) {
        if (k < filled) {
            /* colour-code by zone: low=safe, mid=caution, high=loud */
            if (k < BAR_FULL * 5 / 10)       out[i++] = '=';   /* ≤65 dB  */
            else if (k < BAR_FULL * 7 / 10)  out[i++] = '#';   /* ≤79 dB  */
            else                              out[i++] = '!';   /* >79 dB  */
        } else {
            out[i++] = ' ';
        }
    }
    out[i++] = ']';
    out[i]   = '\0';
}

/* =========================================================================
 * Helper: calculate dBFS from a raw int32 I2S buffer.
 *
 *  mode A (0) — treat entire 32-bit word as sample (MSB-aligned)
 *               divisor = INT32_MAX ≈ 2,147,483,648
 *  mode B (1) — 24-bit right-justified in lower 24 bits (sign-extended)
 *               divisor = 0x7FFFFF = 8,388,607
 *  mode C (2) — 24-bit left-justified: shift right 8  (correct for INMP441)
 *               divisor = 0x7FFFFF = 8,388,607
 *
 * Returns dBFS (negative number; 0 dBFS = full scale).
 * Also writes peak absolute value to *peak_out (in raw integer counts).
 * ========================================================================= */
static float calc_dbfs(const int32_t *buf, int n, int mode, int32_t *peak_out)
{
    const float scale = (mode == 0) ? 2147483648.0f : 8388608.0f;
    double mean  = 0.0;
    double sumsq = 0.0;
    int32_t peak = 0;
    int32_t zero_count = 0;

    /* --- first pass: mean and peak --- */
    for (int i = 0; i < n; i++) {
        int32_t s;
        if (mode == 0) {
            s = buf[i];
        } else if (mode == 1) {
            /* right-justify: keep lower 24 bits, sign-extend */
            s = buf[i] & 0x00FFFFFF;
            if (s & 0x00800000) s |= (int32_t)0xFF000000;
        } else {
            /* left-justify: upper 24 bits are the sample */
            s = buf[i] >> 8;
        }
        int32_t a = (s == INT32_MIN) ? INT32_MAX : (s < 0 ? -s : s);
        if (a > peak) peak = a;
        if (a == 0)   zero_count++;
        mean += (double)s;
    }
    mean /= (double)n;

    /* --- second pass: variance (DC-removed) --- */
    for (int i = 0; i < n; i++) {
        int32_t s;
        if (mode == 0) {
            s = buf[i];
        } else if (mode == 1) {
            s = buf[i] & 0x00FFFFFF;
            if (s & 0x00800000) s |= (int32_t)0xFF000000;
        } else {
            s = buf[i] >> 8;
        }
        double centred = (double)s / scale - mean / scale;
        sumsq += centred * centred;
    }

    float rms = (float)sqrt(sumsq / (double)n);
    if (rms < 1e-10f) rms = 1e-10f;

    if (peak_out) *peak_out = peak;
    return 20.0f * log10f(rms);
}

/* =========================================================================
 * Helper: count zero samples (lower 24 bits == 0) — detects dead mic.
 * ========================================================================= */
static int count_zeros(const int32_t *buf, int n)
{
    int z = 0;
    for (int i = 0; i < n; i++) {
        int32_t s = buf[i] >> 8;            /* 24-bit left-justified       */
        if (s == 0) z++;
    }
    return z;
}
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

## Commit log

2026-01-07 Initial commit: Sound Level Mesh System documentation
    - Product Requirements Document (PRD)
    - Architecture Document
    - Hardware Design Document
    - Complete system specifications for 10 ESP32 devices with INMP441 microphones
    - File-based storage architecture
    - Ubuntu 20.04 with Nginx deployment configuration
    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
2026-01-07 Add README.md - Project welcome page and status documentation
    - Project overview and current status (design/planning phase)
    - Links to all documentation files
    - Technology stack summary
    - Getting started guide
    - Development status table
    - Repository structure
2026-01-07 Update documentation to reflect purchased hardware
    - Updated to ESP32-C3 (purchased 10 units) instead of standard ESP32
    - Added purchased hardware status section with order details
    - Updated all specifications to reflect ESP32-C3 (RISC-V, single-core)
    - Added notes about I2S pin verification needed upon hardware receipt
    - Updated power supply info (USB wall chargers and USB-C cables purchased)
    - Updated BOM to show purchased vs. needed components
    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
2026-01-07 Add anti-aliasing and windowing techniques for frequency analysis
    - Add digital anti-aliasing low-pass filter before FFT processing
    - Implement windowing functions (Hamming/Hanning/Blackman) to reduce spectral leakage
    - Add window gain compensation in frequency calculations
    - Update audio processing pipeline to include anti-aliasing and windowing steps
    - Add signal processing requirements to PRD
    - Update firmware structure to include anti-alias filter and window function modules
    - Add glossary terms for anti-aliasing, windowing, and spectral leakage
    - Update performance considerations with signal processing details
2026-01-07 Complete anti-aliasing and windowing documentation updates
    - Update data flow diagram to show anti-aliasing and windowing steps
    - Add glossary terms for signal processing concepts
    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
2026-02-02 Complete sound monitoring mesh system implementation
    - Implemented ESP32-C3 firmware with RMS sound level measurement and frequency band analysis
    - Added backend API server with device management, data storage, and analytics endpoints
    - Created responsive web frontend with real-time monitoring and charting
    - Integrated full stack: firmware -> backend -> frontend
    - Added comprehensive documentation and quickstart guides
    - Configured CORS, persistent background processes for frontend/backend
    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
2026-02-08 Major update: Add triangulation, kiosk display, sanitize credentials
    - Add sound source triangulation with TDOA algorithm
    - Add acoustic barrier modeling for sound attenuation
    - Implement kiosk display mode for 1080p touchscreens with auto-scaling map
    - Add sensor position configuration interface
    - Integrate mDNS support for ESP32 devices
    - Reorganize documentation (moved old docs to docs-archive/)
    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
2026-02-11 Add WiFi signal solutions documentation and firmware partition configuration
    [Sound Sensor enclosure.f3d, Sound Sensor enclosure.stl, partitions.csv]
2026-02-12 Release v1.2.0 - Production deployment fixes and kiosk display
    Major changes:
    - Fixed critical API routing issues (/api/api/ double path)
    - Implemented kiosk display page for public monitoring
    - Added comprehensive debug tools
    - Synced version numbers across all components
    - Deployed to production server (xibo.space.nova-labs.org)
    - Flashed 5 sensors with firmware v1.2.1-prod
    Bug fixes:
    - Fixed Apache ProxyPass configuration
    - Fixed frontend API auto-detection for production
    - Fixed multiple kiosk.js syntax errors
    - Fixed triangulation endpoint paths
    Documentation:
    - Added CHANGELOG.md
    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
    [main.c]
2026-02-28 security: scrub WiFi credentials and API key from tracked files
    - README.md, HARDWARE_AND_FIRMWARE.md: replace passwords/API key with CREDENTIALS.local references
    - DEVELOPER_REFERENCE.md, backend/README.md: replace API key examples with placeholders
    - sdkconfig.defaults: replace real WiFi/API credentials with placeholder values
    - firmware: fix I2S_DATA_BIT_WIDTH_24BIT -> 32BIT in production firmware
    [main.c, main_debug.c]
2026-03-01 v2.1.1-prod/v2.1.2-dev: Fix I2S DMA mis-packing and frequency band SPL calculation
    - Fix 24-bit→32-bit I2S DMA data width mis-packing causing constant ~110 dB readings
    - Fix frequency band SPL calculation using self-normalizing energy fraction
    - Add 10K pull-down on SD line (confirmed required)
    - Add firmware versions 2.1.1-prod and 2.1.2-dev to versions.json
    - Remove legacy versions-prod.json (merged into versions.json)
    - Add firmware binaries: sound-sensor-2.1.1-prod.bin, sound-sensor-2.1.2-dev.bin
    [main.c]
2026-03-01 docs: consolidate README, reorganize scripts, archive old docs
    - README.md: full rewrite to match current firmware (v2.1.1-prod/v2.1.2-dev),
    backend (13 routes), and frontend (7 tabs + kiosk). Covers architecture,
    hardware wiring (with 10kΩ SD pull-down note), I2S DMA fix, OTA workflow,
    API reference, production deployment, and security guidance.
    - CHANGELOG.md: add v2.1.1-prod entry; fix placeholder GitHub username in links
    - backend/README.md, frontend/README.md: simplified to pointers to main README
    - scripts/: new directory; move deploy-kiosk.sh here
    - scripts/grafana/: move grafana install scripts and dashboard JSON here
    - docs-archive/: move DEVELOPER_REFERENCE.md, HARDWARE_AND_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
